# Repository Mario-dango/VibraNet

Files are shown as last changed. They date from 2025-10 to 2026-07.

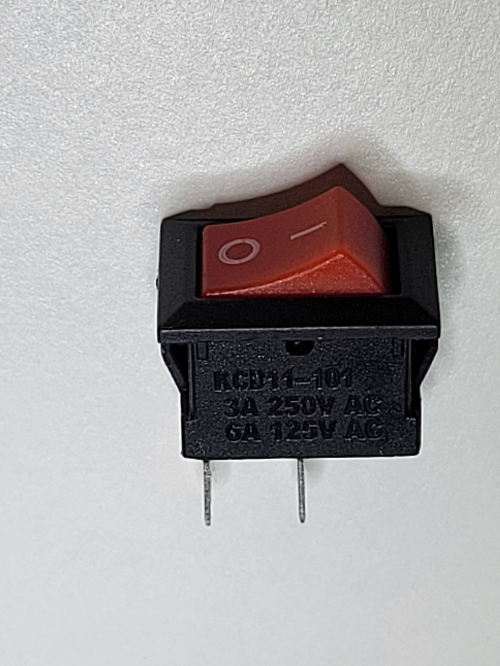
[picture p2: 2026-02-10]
DESIGN/mini-on-off-rocker-switch-2-pins-1.snapshot.4/KCD11-101.jpg

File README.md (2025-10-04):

# Proyecto Tipo C · Red de nodos de adquisición de datos sismográficos

> Monitoreo de vibraciones/sismos en edificación universitaria con nodos ESP8266 + MPU6050, backend Node-RED/Mosquitto/MySQL en Ubuntu Server. 

---

## 1) Contexto y alcance

* **Dominio:** monitoreo sísmico estructural en la Facultad de Medicina (UNCuyo), con **4–10 nodos** distribuidos en puntos de interés. 
* **Tecnologías núcleo:** Node-RED (gestión/visualización), Mosquitto (MQTT), MySQL (persistencia), Ubuntu Server (SO). 
* **Nodo:** ESP8266 (ESP-01) + MPU6050 (GY-521), alimentación fija y Li-ion, PCB propia. 
* **Motivación:** alternativa **de bajo costo** con desempeño “accionable” frente a soluciones comerciales de alta precisión pero costosas.  

**Objetivo general:** validar la factibilidad y el error objetivo (≤10%) mediante prototipado, pruebas y calibración.  

---

## 2) Arquitectura (E2E)

```mermaid
flowchart LR
  %% IDs simples (A–Z, 0–9, _), solo ASCII. Sin <br/> ni comillas curvas.
  subgraph Capa_Nodos_4_10
    A1["ESP8266 / ESP-01\nMPU6050 (GY-521)"] -->|MQTT QoS1| BRK[(Mosquitto)]
    A2["ESP8266 / ESP-01\nMPU6050 (GY-521)"] -->|MQTT QoS1| BRK
  end

  BRK --> NR["Node-RED\nFlows + Dashboards"]
  NR  --> DB[(MySQL)]
  NR  --> A[Alertas / Notificaciones]

  %% Estilo básico para infra
  classDef infra fill:#eeeeee,stroke:#333333,stroke-width:1px;
  class BRK,DB infra;
```

**Notas:**

* Visualización y orquestación en **Node-RED**, broker **Mosquitto**, almacenamiento **MySQL** sobre **Ubuntu Server**. 
* Escalabilidad por cobertura de **4–10** dispositivos; despliegue in situ en el edificio objetivo. 

---

## 3) Estructura del repositorio

```
.
├─ firmware/                # Código ESP8266 (ESP-01) + MPU6050
   ├─ src/
   └─ include/
├─ design/                  # 3D models
│  ├─ Acoples/              
│  ├─ Accesorios/                 
│  └─ Impresiones 3D/                   
├─ PCB/
│  └─ Diseño de módulo      
├─ docs/
│  ├─ arquitectura.md
│  ├─ calibracion.md
│  └─ o&m.md
└─ README.md
```

---

## 4) Requisitos

* **Nodo:** Módulo ESP-07, módulo GY-521, fuente 5 V + step-down 3.3 V, batería Li-ion opcional. 
* **Servidor:** Ubuntu Server con Node-RED, Mosquitto y MySQL. 

---

## 5) Firmware (ESP8266 + MPU6050)

**Intención:** lectura de aceleraciones/giroscopio, timestamp NTP, buffer local, MQTT QoS1 con reconexión y LWT, watchdog, empaquetado JSON/CBOR.

**Supuestos de diseño:**

* Frecuencia de muestreo recomendada 100–200 Hz para vibraciones estructurales de baja a media frecuencia.
* Antialiasing digital simple con media móvil/BIQUAD; calibración in situ en etapa de instalación.

**Esqueleto de payload (JSON):**

```json
{
  "node_id": "FACMED-03",
  "ts_unix_ms": 1733345678901,
  "ax": -0.0123, "ay": 0.0045, "az": 1.0012,
  "gx": 0.12, "gy": -0.05, "gz": 0.02,
  "vbat": 3.94, "temp": 28.4, "seq": 15231
}
```

**Tópicos MQTT:**

```
sismo/nodo/<node_id>/datos       (QoS1, no retenido)
sismo/nodo/<node_id>/estado      (QoS1, retenido)      # heartbeats
sismo/nodo/<node_id>/lwt         (QoS1, retenido)      # Last Will
sismo/cmd/<node_id>              (QoS1)                # control
```

**Criterios de prueba rápida:**

1. Pérdida de WiFi: datos en buffer y reenvío al reconectar.
2. Desconexión broker: activación de **LWT** y recuperación de sesión.
3. Variación NTP: jitter de timestamp < 20 ms en red local.

---

## 6) Backend

### 6.1 Mosquitto (MQTT)

**Intención:** broker central con TLS, usuarios/ACL y LWT.

```conf
# deploy/mqtt/mosquitto.conf (resumen)
listener 8883
cafile /etc/mosquitto/certs/ca.crt
certfile /etc/mosquitto/certs/server.crt
keyfile /etc/mosquitto/certs/server.key
require_certificate false
allow_anonymous false
password_file /etc/mosquitto/passwd
acl_file /etc/mosquitto/acl
persistence true
persistence_location /var/lib/mosquitto/
```

**ACL mínimo de ejemplo:**

```
user nodo01
topic write sismo/nodo/nodo01/#
topic read  sismo/cmd/nodo01

user nodered
topic read  sismo/nodo/+/datos
topic read  sismo/nodo/+/estado
topic read  sismo/nodo/+/lwt
topic write sismo/cmd/+
```

### 6.2 Node-RED

**Intención:** ingestión MQTT, cálculo de KPIs (PGA/PGV), alarmas y dashboard.
**KPIs sugeridos:** PGA, PGV, espectros de respuesta 5% amort.
**Entrega:** flujos exportables en `backend/nodered/flows/*.json`.

### 6.3 MySQL (modelo de datos)

**Intención:** persistencia de series temporales y metadatos.

```sql
-- backend/db/schema.sql (resumen)
CREATE TABLE nodes (
  id VARCHAR(32) PRIMARY KEY,
  alias VARCHAR(64),
  location VARCHAR(128),
  installed_at DATETIME,
  active TINYINT DEFAULT 1
);

CREATE TABLE samples (
  id BIGINT AUTO_INCREMENT PRIMARY KEY,
  node_id VARCHAR(32) NOT NULL,
  ts_unix_ms BIGINT NOT NULL,
  ax FLOAT NOT NULL, ay FLOAT NOT NULL, az FLOAT NOT NULL,
  gx FLOAT, gy FLOAT, gz FLOAT,
  vbat FLOAT, temp FLOAT, seq BIGINT,
  KEY k_node_ts (node_id, ts_unix_ms),
  CONSTRAINT fk_samples_node FOREIGN KEY (node_id) REFERENCES nodes(id)
);

CREATE TABLE events (
  id BIGINT AUTO_INCREMENT PRIMARY KEY,
  started_at DATETIME NOT NULL,
  ended_at   DATETIME,
  max_pga FLOAT, max_pgv FLOAT, note VARCHAR(255)
);
```

**Criterios de prueba rápida:**

* Inserción sostenida ≥ 200 msg/s en LAN con retardo < 100 ms E2E.
* Consultas por ventana móvil de 5 min bajo 200 ms.

---

## 7) Despliegue

### 7.1 Docker Compose (opcional)

```yaml
# deploy/docker-compose.yml
version: "3.9"
services:
  mosquitto:
    image: eclipse-mosquitto:2
    ports: ["1883:1883", "8883:8883"]
    volumes:
      - ./mqtt/mosquitto.conf:/mosquitto/config/mosquitto.conf:ro
      - ./mqtt/certs:/etc/mosquitto/certs:ro
      - mosq_data:/var/lib/mosquitto
  nodered:
    image: nodered/node-red:latest
    ports: ["1880:1880"]
    environment:
      - TZ=America/Argentina/Mendoza
    volumes:
      - ./nodered/data:/data
  mysql:
    image: mysql:8
    environment:
      - MYSQL_ROOT_PASSWORD=changeme
      - MYSQL_DATABASE=sismo
    ports: ["3306:3306"]
    volumes: [ "mysql_data:/var/lib/mysql" ]
volumes: { mosq_data: {}, mysql_data: {} }
```

### 7.2 Ubuntu Server

* Instalar paquetes base, habilitar firewall, configurar TLS y usuarios para broker y DB. 

---

## 8) Seguridad y roles

* **Transporte:** TLS en MQTT y en accesos al dashboard.
* **Autenticación:** usuarios separados por rol: `nodo`, `nodered`, `ops`.
* **Principio de mínimo privilegio:** ACL por tópico.
* **DB:** credenciales por servicio, rotación y backups programados.

---

## 9) Calibración y validación

* **Metodología:** prototipado → pruebas con estímulos conocidos → calibración para error ≤10%. 
* **Resultados esperados:** sistema instalado, base de datos operativa, informe técnico. 

---

## 10) Plan de pruebas

1. **Nodo**: watchdog, reconexión, buffer offline, precisión de timestamp.
2. **Red**: caída de WiFi y broker, recuperación de sesión MQTT.
3. **Integración**: ingestión Node-RED → MySQL, latencia y throughput.
4. **Resiliencia**: microcortes de energía, persistencia del broker.
5. **Validación**: comparación contra referencia en mesa vibratoria/estímulo controlado.

---

## 11) Instalación in situ y O&M

* **Ubicación y fijación** de nodos en la estructura; coordinación con autoridades para permisos y posiciones. 
* **Mantenimiento mínimo:** recambio/recarga de batería Li-ion según desgaste. 

---

## 12) Roadmap (alto nivel)

1. Diseño y prototipado del nodo.
2. Backend en nube y pruebas de integración.
3. Fabricación 4–10 unidades, instalación, optimización. 

---

## 13) Trazabilidad (resumen)

* **Requisito**: bajo costo y despliegue escalable → **Diseño**: ESP8266 + MPU6050; **Implementación**: MQTT/Node-RED/MySQL; **Prueba**: error ≤10%; **Resultado**: sistema instalado y DB operativa.   

---

## 14) Contribución

* PRs con tests y flujos reproducibles.
* Convenciones: commits tipo Conventional Commits, revisiones de seguridad básicas.

---

## 15) Licencia

Licencia MIT.

---

## 16) Créditos

* **Organismo:** Facultad de Ingeniería – UNCuyo. **Espacio:** Mecánica Vibratoria. 
* **Beneficiarios:** Facultad de Medicina (sistema + acceso lector a DB); cátedra Mecánica Vibratoria (nodo didáctico).  

---

## 17) Referencias del proyecto

* Documento base del proyecto: “Proyecto Tipo C: Red de nodos de adquisición de datos sismográficos.” (PDF). 
* Contexto y motivación (“Key Information”). 

---

### Anexo A · Diagrama de secuencia (telemetría)

```mermaid
sequenceDiagram
  autonumber
  participant MPU as MPU6050
  participant MCU as ESP8266 (ESP-01)
  participant BRK as Mosquitto
  participant NR as Node-RED
  participant DB as MySQL

  MPU->>MCU: Lectura ax,ay,az,gx,gy,gz @fs
  MCU->>MCU: Timestamp NTP + empaquetado JSON
  MCU->>BRK: PUBLISH sismo/nodo/<id>/datos (QoS1)
  BRK-->>NR: FORWARD mensaje
  NR->>DB: INSERT muestras
  NR-->>NR: KPIs (PGA/PGV) + alarmas
```

---

> **Cómo usar este README**
>
> 1. Adaptá el `docker-compose.yml` a tu servidor.
> 2. Importá los flujos Node-RED y conectá al broker y DB.
> 3. Flasheá el firmware del ESP-01 con tus credenciales WiFi/MQTT.
> 4. Corré pruebas de red, ingestión y calibración hasta cumplir el ≤10% de error. 

---

Medical References:
1. None — DOI: file-QWTmTeDuec8pwW5nHiFvFW

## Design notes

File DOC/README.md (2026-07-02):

## Mejoras futuras
- Que los nodos no deban de estar en la misma red que el servidor.
- Montar el servidor en un host cloud.
- Diseñarle acoples en 3D del nodo principal y de su extensión para el sensor s2.
- Agregarle una instancia de persistencia de datos, módulo microSD para que almacene las lecturas, pregunte si las lecturas guardadas respecto a las del servidor están actualizadas o deberá de enviarlas.
- Agregar en grafana la posibilidad de exportar todos esos datos que visualiza en un archibo .xlsx o .csv para análisis fuera de grafana.
- Agregar un botón de configuración (que permita ponerlo en modo AP y cambiar credenciales manualmente de red y mqtt).
- Configurar parámetros del nodo por mqtt (nodo id, cliente, etc).

## Faltó realizar pruebas
- Recepción de señal Wi-Fi en entornos industriales o de ruido electromagnético (para disernir si agregar antena externa o no).
- Comprobar ruidos EM que se colen en el cable del sensor s2.

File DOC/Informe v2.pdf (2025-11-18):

UNIVERSIDAD NACIONAL DE CUYO

Facultad de Ingeniería

Red de nodos de adquisición de datos sismográficos.

Red de adquisición sísmica: del prototipo THT a la revisión SMD

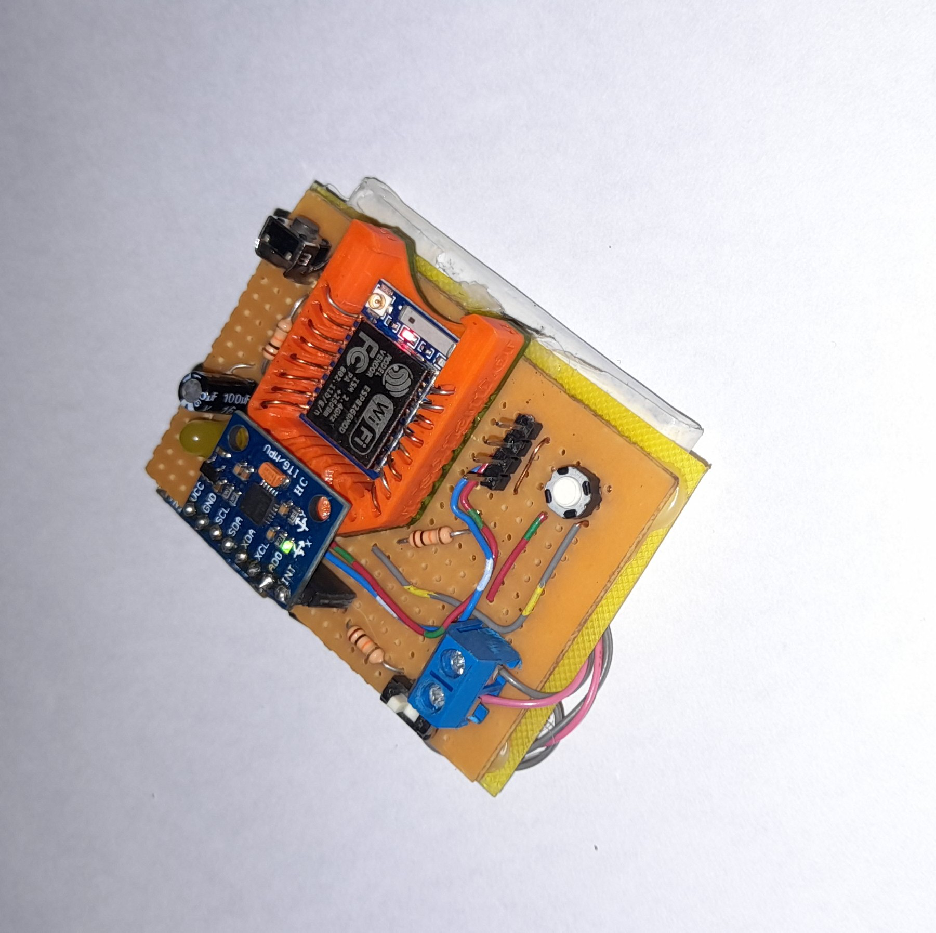
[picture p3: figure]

C A R R E R A | Ingeniería Mecatrónica
S E M E S T R E | Segundo Semestre 2025
C Á T E D R A | Proyecto Tipo C
A L U M N O S | Barrios Retta Federico , 14101
| Cano Francisco , 12487
| Pappeti Mario , 11807
F E C H A | 03 de noviembre de 2025

### Contents

1 Resumen ejecutivo | 3
2 Contexto y objetivos | 3
3 Alcance y trazabilidad | 3
4 Arquitectura general (E2E) | 4
5 Selección de plataforma MCU y módulos Wi-Fi | 5
6 Micro investigación de mercado | 6
7 Diseño HW — Placa v0.0.1 (THT) | 7
8 Problemática de energia — Batería Li-ion | 10
9 Diseño HW — Placa v0.0.2 (SMD) | 12
10 Prototipo físico | 15
11 Firmware (ESP8266/ESP32) | 17

Universidad Nacional de Cuyo | Facultad de Ingeniería
12 Cobertura y propagación (plan de medicion) | 18
13 Deep-sleep y “reset virtual” (ESP8266) | 18
14 Backend y dashboard | 19
15 Frecuencias de muestreo — justificación | 19
16 Riesgos y mitigaciones | 20
17 Plan de proxima iteracion | 20
18 Anexos | 20

### 1 Resumen ejecutivo

Este proyecto desarrolla una red de nodos sismográficos IoT con adquisición triaxial y backend MQTT+MySQL, orientada al monitoreo de vibraciones estructurales en la banda 0.5–30 Hz. Durante este corte se priorizó la verificación funcional de hardware (v0.0.1 THT y v0.0.2 SMD), la puesta en marcha de la base de datos y la consolidación del firmware para adquisición cruda y publicación por bloques. Se identificaron restricciones energéticas y de reconexión asociadas al uso de Li-ion y deep-sleep en ESP8266, que guían las decisiones de regulación y de diseño de ciclos de trabajo. El objetivo inmediato es cerrar mediciones en banco (consumo, autonomía y latencia E2E) y validar cobertura Wi-Fi para el piloto.

Avances clave

- Diseño de placa de desarrollo v0.0.1 (THT) y v0.0.2 (SMD).
- Prototipo físico para verificación dimensional y ensamble.
- Arquitectura de la base de datos MySQL.
- Análisis de energía y batería, con dificultades detectadas.
- Prototipo de firmware con timers/ISR para muestreo periódico (FreeRTOS).

Riesgos activos

- Autonomía real vs objetivo
- Deep sleep con reset
- Tensión de la pila de Li-ion difiere con Vcc de alimentación del microcontrolador
- Reconexión robusta tras sleep.

Próximos hitos

- Validación energética en banco
- Prototipo físico de la placa de desarrollo v0.0.2 (SMD)
- Inserción bulk y particionado en DB.

### 2 Contexto y objetivos

Este piloto aborda el monitoreo de vibraciones estructurales en banda 0.5-30 Hz mediante una red de nodos IoT que adquieren y publican datos crudos para su procesamiento en servidor. Objetivos medibles del corte: (i) adquisicion estable a 200 Hz y publicacion por bloques; (ii) exactitud ≤ 10% tras calibracion estatica de la IMU; (iii) disponibilidad de ingesta continua (MQTT→Node-RED→MySQL) y consultas por ventana temporal en dashboard.

### 3 Alcance y trazabilidad

Esta iteración se centra en adquirir y publicar datos crudos de aceleración triaxial desde nodos ESP8266 con IMU MPU6050, en la banda 0.5–30 Hz. El procesamiento (filtrado, espectros, KPIs) se realiza en el servidor, dejando al nodo la mínima responsabilidad: medir, empaquetar y publicar por bloques con marca de tiempo (ts_ms, fs_hz, seq). La base de datos MySQL debe aceptar ingesta idempotente y consultas por ventana temporal; el dashboard expone disponibilidad por nodo y series para diagnóstico.

Quedan fuera de alcance del presente corte la instalación definitiva en obra, la optimización energética con conversión buck-boost y las alarmas avanzadas; se documentan como pendientes con riesgos asociados. La validación prioriza: estabilidad de muestreo, reconexión tras deep-sleep y consistencia de la ingesta (sin duplicados) end-to-end.

Trazabilidad de requerimientos actuales

Requerimiento
(qué) | Artefacto (con qué) | Prueba/verificación (cómo) | Estado
Muestreo estable a 200 Hz | Firmware con timer+ISR y
| lectura I2C | Desvío < 1 % en periodo y
| | conteo en 30 min continuos | En
| | | curso
Publicación por bloques (QoS1) | MQTT tópicos
sismo/<site>/<nodeId>/data
| | Recepción íntegra y ordenada
| | de N bloques en broker | En
| | | curso
Reconexión tras deep-sleep | GPIO16->RST y arranque
| idempotente | wake->publish p95 ≤ 3 s;
| | status/LWT correcto | Pendiente
Ingesta idempotente en DB | Tabla mediciones con
| UNIQUE | INSERT ... ON DUPLICATE
| | KEY sin duplicados | OK/Parcial
Consulta por ventana temporal | Índice (nodo_id,
| measured_at) | SELECT rango con latencia
| | aceptable (p50/p95) | OK/Parcial
Trazabilidad de pines/IMU | Pinout efectivo y
| calibración | Lectura estable + offset
| | corregido en reposo | En
| | | curso
Cobertura Wi-Fi en sitio piloto | v0.0.2 con keep-out RF y
| plan de medición | RSSI medio y pérdida < 1 %
| | en 30 min | Planificado

Criterio de aceptación del corte: firmware capaz de medir y publicar bloques a 200 Hz con ts_ms/fs_hz/seq, ingesta idempotente operativa en MySQL y reconexión funcional tras deepsleep (jitter de muestreo, wake->publish, pérdida de mensajes).

### 4 Arquitectura general (E2E)

Diagrama de bloques (visión actual)

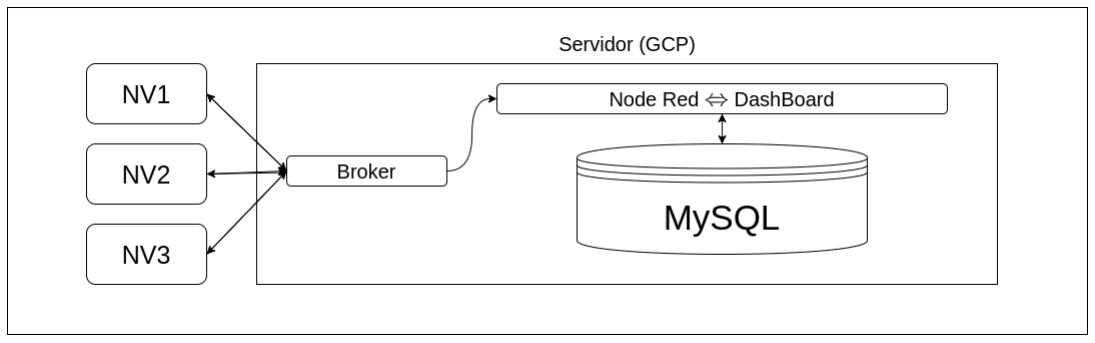
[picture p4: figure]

La solución se organiza en una tubería simple y robusta: cada nodo (ESP8266 + MPU6050) adquiere aceleración triaxial, agrega metadatos mínimos (ts_ms, fs_hz, seq, n, temp_c, vbat) y publica bloques crudos via MQTT hacia un broker Mosquitto. Un flujo en Node-RED valida el esquema, transforma y persiste en MySQL. Todo el posprocesamiento (filtrado, espectros, alarmas) se ejecuta en el servidor, manteniendo el firmware liviano.

El acoplamiento es débil y observable: los nodos usan QoS1 y LWT retenido para señalizar estado; al salir de deep-sleep el arranque es idempotente (re-sincroniza NTP, repone seq y reanuda publicación). El backend aplica inserción idempotente (UNIQUE por nodo_id, measured_at, seq) para tolerar reintentos, y el dashboard consulta por ventanas temporales indexadas. La comunicación va cifrada (TLS en MQTT y MySQL) y con usuarios de privilegios mínimos.

Flujo lógico: Nodos → MQTT (broker) → Node-RED (validación y SQL) → MySQL (persistencia) → Dashboard (consulta).

### 5 Selección de plataforma MCU y módulos Wi-Fi

Fuentes (datasheets)

- ESP8266EX | (Espressif): | https://www.alldatasheet.com/datasheet-pdf/view/
1148030/ESPRESSIF/ESP8266EX.html (https://www.alldatasheet.com/datasheet-pdf/view/1148030/ESPRESSIF/ESP8266EX.html)
- MPU-6050 | (InvenSense): | https://www.alldatasheet.es/datasheet-pdf/view/
517744/ETC1/MPU-6050.html (https://www.alldatasheet.es/datasheet-pdf/view/517744/ETC1/MPU-6050.html)

ESP8266 (ESP-07/ESP-12)

El ESP8266 integra CPU Tensilica LX106 @80–160 MHz, radio 802.11b/g/n 2.4 GHz, TCP/IP embebido, SPI/I2C/UART, timers y GPIO suficientes para un nodo de adquisición sísmica ligera. Para nuestra necesidad (muestreo 100–200 Hz y publicación MQTT), aporta capacidad de cómputo y conectividad de sobra, con un ecosistema maduro (Arduino core/RTOS), bajo costo y buena disponibilidad.

Funciones principales: Wi-Fi STA/AP, pila TCP/IP, TLS por software, interrupciones GPIO, timers HW, deep-sleep con wake en GPIO/RTC.

Consumos típicos (orden de magnitud, dependientes de firmware y AP):

- TX/RX Wi-Fi con ráfagas: picos ~200 mA; promedio en ráfagas 70–120 mA.
- Modem-sleep (CPU activa, radio duty-cycled): ~15–20 mA.
- Light-sleep (CPU en bajo consumo): ~0.8–2 mA.
- Deep-sleep: ~10–25 μA (despierta por GPIO/RTC externo). Estas cifras guían el dimensionamiento de batería y duty-cycle; se recomiendan mediciones reales en banco para validar.

Módulo elegido (ESP-07 frente a ESP-01): migramos de ESP-01 a ESP-07/ESP-12 por: (i) más GPIO útiles (I2C + INT de la IMU sin conflictos), (ii) mejor desempeño RF y keep-out claro para antena, y (iii) opción de antena externa (u.FL en algunas variantes) para ensayos de cobertura en edificio. Esto reduce riesgos de saturación de pines y mejora la robustez del enlace.

Por qué no ESP32 (por ahora): ESP32 agrega BT/BLE, más RAM/CPU y periféricos, pero incrementa costo y consumo en reposo. Dado que el ancho de banda de señal sísmica de interés es 0.5–30 Hz y la tasa de publicación es modesta, el ESP8266 cubre holgadamente requisitos con menor consumo en deep-sleep y menor BOM. Dejamos ESP32 como alternativa si más adelante requerimos: doble núcleo para procesamiento local, ADCs internos de mayor calidad, o cifrado TLS con mayores márgenes.

MPU-6050 (acelerómetro+giroscopio 6-ejes)

El MPU-6050 integra acelerómetro y giróscopo triaxiales con ADCs de 16 bits, DMP, FIFO de 1024 B e interfaz I2C (400 kHz). Rango programable ± 2/4/8/16 g y ±250/500/1000/2000 °/s. La interrupción INT permite muestreo cronometrado y lectura por ráfagas.

Consumos (datasheet):

- Acel+gyro+DMP activos: ~3.9 mA.
- Solo acelerómetro: ~500 μA.
- Acelerómetro en low-power: ~10 μA @1.25 Hz a ~140 μA @40 Hz.
- FIFO e INT reducen actividad del MCU al permitir lecturas en ráfagas.

Justificación de elección: amplia disponibilidad, costo bajo, documentación y ejemplos abundantes, y rendimiento suficiente para 100–200 Hz con ruido aceptable tras calibración de offsets/escala. El pin INT facilita sincronía de muestreo y el FIFO evita jitter por latencias de I2C/MQTT.

Síntesis comparativa

ESP8266 (ESP-07/12) + MPU-6050 ofrece la mejor relación costo/consumo/capacidad para un nodo IoT sísmico: Wi-Fi estable, consumo en deep-sleep de orden decenas de μA, y sensor 6-ejes ~4 mA activo. ESP32 queda como “plan B” si más adelante necesitamos procesamiento embarcado o enlaces más exigentes; el ESP-07 se prefiere al ESP-01 por GPIO y performance RF (opción de antena externa) que simplifican el cableado de I2C+INT y los ensayos de propagación.

### 6 Micro investigación de mercado

El monitoreo de vibraciones en la banda 0.5–30 Hz tiene dos ecosistemas cercanos pero distintos: SHM civil/sísmico y PdM industrial. El primero prioriza baja frecuencia real (hasta DC o 0.5 Hz), autonomía y robustez ambiental; el segundo privilegia diagnósticos de maquinaria y suele cortar por debajo de 1–3 Hz. En este contexto, los acelerómetros MEMS modernos de bajo ruido habilitan nodos IoT triaxiales de costo contenido y consumo moderado, mientras que las soluciones piezoeléctricas IEPE siguen dominando cuando se requiere precisión metrológica de alto nivel.

Hallazgos clave

- Compatibilidad de banda: muchos transmisores 4–20 mA industriales fallan por debajo de 3–10 Hz; no sirven para 0.5–30 Hz. En cambio, MEMS triaxiales específicos de baja frecuencia (p. ej., líneas tipo ADXL35x/derivados) sí cubren la banda objetivo.
- Nodos COTS: existen equipos SHM inalámbricos con rango útil desde 0.5 Hz y pisos de ruido <100 μg/√Hz; son robustos pero caros y, a menudo, con radio/protocolo propietarios (LoRaWAN/protocolos 2.4 GHz).
- Argentina (ecosistema): hay integradores locales para soluciones “llave en mano” y distribuidores de sensores sísmicos de baja frecuencia (v.g., VibraSens vía representante local), además de servicio/calibración con trazabilidad internacional.
- Backend: MQTT es estándar para telemetría; MySQL funciona para prototipo.
- Estrategia: para este proyecto académico con control de pila y costo, conviene Integrar (sensores adecuados + nodos propios + MQTT + DB) en lugar de Comprar COTS o Desarrollar desde cero ASIC/PCB de alto NRE.

Implicancias para nuestro diseño

Para capturar 0.5–30 Hz con SNR adecuado y mantener autonomía, se justifica continuar con nodos IoT MEMS triaxiales y publicación vía MQTT; mantener MySQL. En Argentina existe oferta para: (a) sensores de baja frecuencia, (b) integración LoRaWAN/MQTT, y (c) calibración con trazabilidad, lo que viabiliza escalamiento y validación metrológica local en siguientes cortes.

### 7 Diseño HW — Placa v0.0.1 (THT)

Descripción General

Se diseno una primera revision orientada a verificacion funcional. La alimentacion se resolvio con batería Li-ion, diodo serie y LDO AMS1117-3.3, suficiente para banco pero limitada en eficiencia y margen de caida. La logica de arranque incluye pulsadores de BOOT y RESET con EN por pull-up. La IMU MPU6050 se conecta por I2C y expone INT al MCU. Se dispone de senalizacion mediante cuatro LEDs y de headers para UART y MPU6050.

- Formato: 61.98 × 33.02 mm, 4 orificios de montaje.
- Topologia: batería Li-ion → diodo serie → LDO AMS1117-3.3 → rail 3V3 para ESP-07 y GY-521.
- Senalizacion: cuatro LEDs (Wi-Fi, datos, aux1, aux2) con resistencias limitadoras.
- Control: pulsadores de BOOT y RESET; EN con pull-up (R3).
- Interfaz: header UART para programacion y header I2C/INT para IMU.
- Conectividad IMU: SCL/SDA, INT y AD0 cableados al conector J4 (modulo MPU6050).

Bloques y esquemas

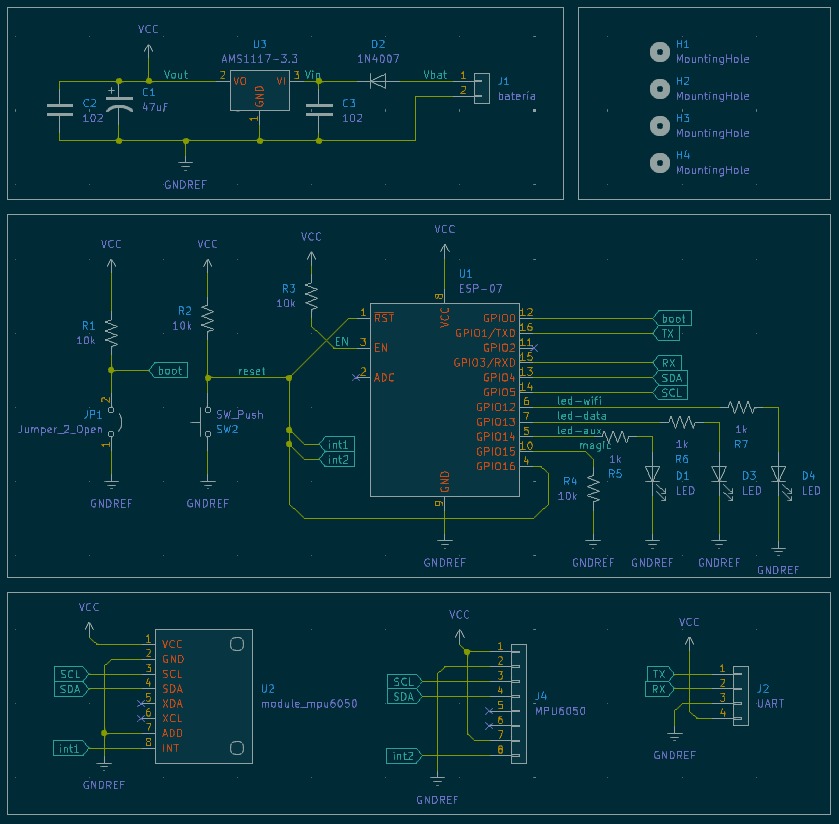
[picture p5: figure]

1. Alimentacion: AMS1117-3.3 con C1=47 μF de bulk y ceramicos de desacople (C2

, C3
).
Diodo 1N4007 en serie desde batería como solucion transitoria para reducir Vbat.
2. Control de arranque:
- BOOT con R1 = 10kΩ a GND y pulsador a VCC para forzar modo flash cuando se requiera.
- RESET con R2 = 10kΩ, pulsador a GND y EN con R3 = 10kΩ a VCC.
3. MCU + IO: ESP-07 con GPIOs mapeados a UART, I2C y LEDs (R4 − R7
).

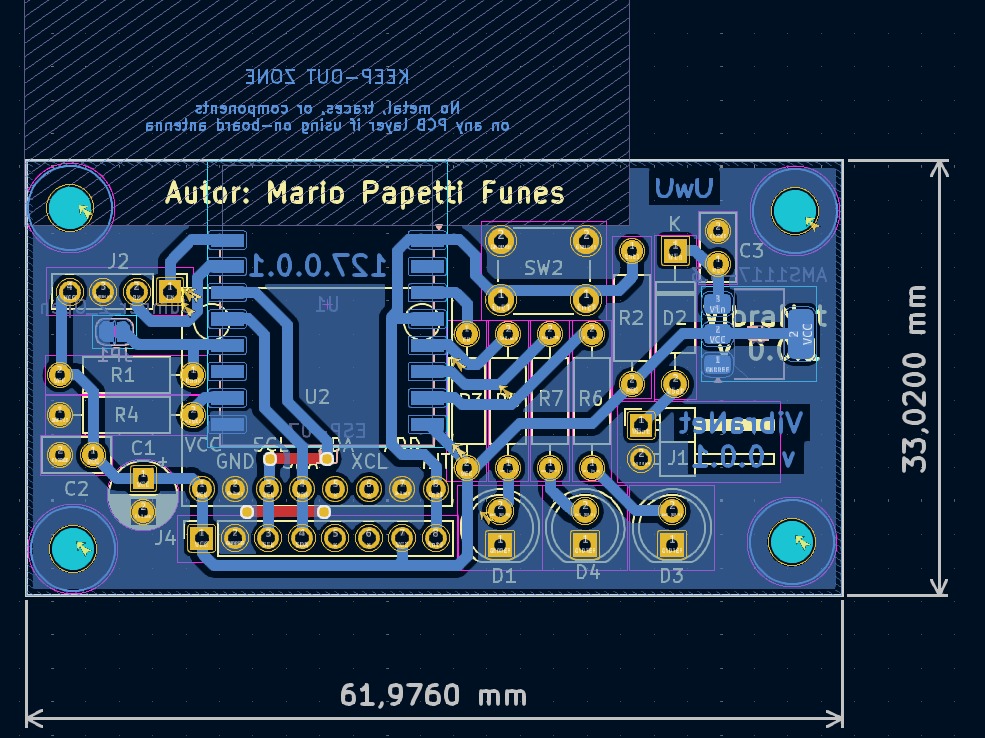
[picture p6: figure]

Ruteo de una cara con puentes; headers dedicados para UART y MPU6050. Se senalan keep-out y leyendas (autor, version).

Pinout efectivo (para trazabilidad de firmware)

Funcion | Pin ESP8266 | Conector | Nota
UART TX | GPIO1/TXD0 | J2-TX | Programacion/registro
UART RX | GPIO3/RXD0 | J2-RX | Programacion/registro
I2C SCL | GPIO5 | J4-SCL | Pull-ups en modulo GY-521
I2C SDA | GPIO4 | J4-SDA | —
IMU INT | GPIO14 (int1) | J4-INT | Interrupciones de movimiento
LED Wi-Fi | GPIO12 | D1 + R4 | Estado radio
LED Datos | GPIO13 | D2 + R5 | Publicacion/actividad
LED Aux 1 | GPIO15 | D3 + R6 | Uso general
LED Aux 2 | GPIO16 | D4 + R7 | Uso general
EN (chip-enable) | EN | — | Pull-up R3 = 10kΩ
RESET | RST | SW2 | Pulsador a GND
BOOT | GPIO0 | SW1/JP1 | Forzar modo programacion

Riesgos e impactos

Riesgo | Impacto
Dropout con LDO + diodo Resets en TX Falta de desacople correcto Ruido en IMU/MCU

Riesgo | Impacto
Sin medicion de corriente | Autonomia incierta
Proteccion insuficiente | Sensibilidad a ESD/fallos

Registro fotográfico (referencias)

- Vista superior: ubicacion de ESP-01, GY-521, LED y controles.
- Vista inferior: batería y cargador/proteccion con cableado.
- Vista lateral: apilado de modulos, disipador en ESP-01, accesos a headers.
- Vista isometrica: vista general de la disposicion del prototipo.

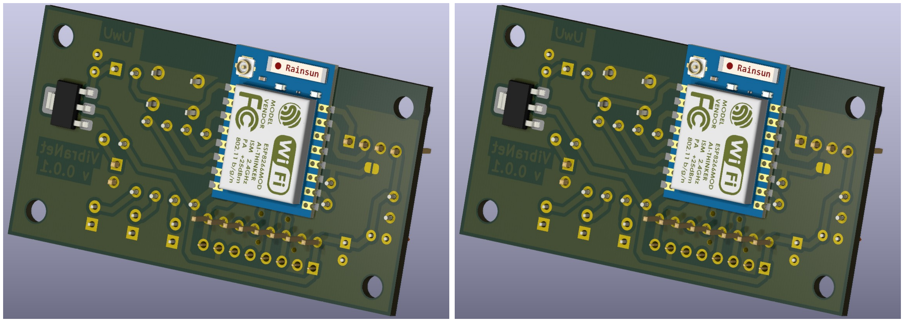
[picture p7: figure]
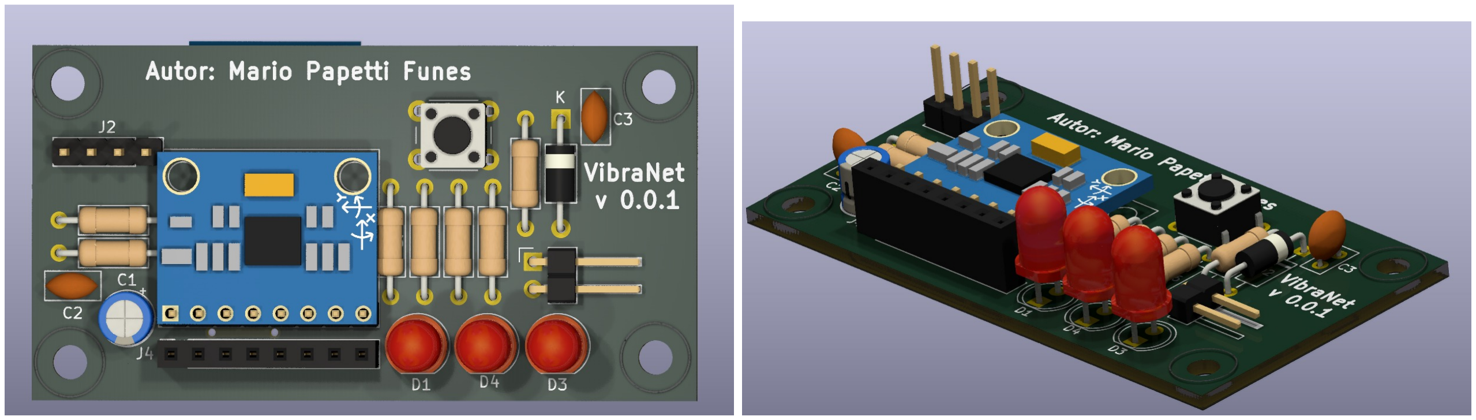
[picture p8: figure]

Figura: Vibranet v0.0.1 (vistas del prototipo THT).

### 8 Problemática de energia — Batería Li-ion

La red de nodos requiere autonomia electrica para operar sin red fija. La fuente elegida es una celda Li-ion de factor de forma compacto (≤ 50 × 50 mm, espesor < 7.5 mm). El ESP8266 opera entre 2.5-3.6 V y presenta cuatro modos de potencia (activo, modem-sleep, light-sleep y deep-sleep). Segun el datasheet del ESP8266EX (https://documentation.espressif.com/0a-esp8266ex_datasheet_en.pdf) , el consumo tipico es: deep-sleep ≈ 20μA, light-sleep ≈ 0.9mA, modem-sleep ≈ 15mA, y en activo con radio el promedio ronda decenas de mA con picos de >100 mA en TX/RX (ver Tabla 3-4 “Power Consumption by Power Modes” y Tabla 1-1 “Specifications”).

El consumo del modulo MPU6050 se debe suponer hasta realizarse mediciones. Supuesto: la IMU MPU6050 anade ≈ 3-4 mA en adquisicion continua y < 10 μA en modo low-power accel. Estos valores se validaran en banco.

Implicancia: la autonomia no la determina el consumo de 20μA en deep-sleep, sino el duty cycle real entre medir, transmitir y dormir. Ademas, el rango de tension de la celda Li-ion

(≈ 4.2 → 3.0V ) no es directamente compatible con la ventana 2.5 − 3.6V del ESP8266 si no se condiciona la tension.

Restricciones de diseno

1. Tensión
- Batería Li-ion: 4.2 V (cargada) a ~3.0 V (descargada).
- ESP8266: 2.5-3.6 V.
- Conclusión: se requiere regulacion.

– Un diodo en serie (≈ 0.7 V) reduce 4.2 -> 3.5 V, pero colapsa a ~2.3 V cuando la celda cae a 3.0 V, bajo el minimo del ESP8266. No es solucion de produccion. – Un LDO a 3.3 V desaprovecha la cola de la batería (cuando Vin < 3.3 V entra en dropout).
– Un buck a 3.3 V es eficiente por arriba de 3.3 V, pero no regula cuando Vin < 3.3 V.
2. Ciclo de operación Definimos un ciclo con tres estados:
- Activo (adquisicion + TX): ESP8266 activo con radio, IMU activa.
- Idle/light-sleep: CPU o perifericos pausados, radio apagado.
- Deep-sleep: solo RTC operativo; en ESP8266 el wake implica reset del MCU.
3. Recuperación post-sleep El deep-sleep reinicia el ESP8266: se debe reconstruir estado (NTP, MQTT, seq, reconfiguracion IMU) de forma idempotente.

Marco de calculo de autonomia

Para un ciclo de duracion T = ta + tl + td

con corrientes Ia

, Il

, Id
:

Considerando:

- T : duracion total de un ciclo.
- ta
: tiempo en estado activo (adquisicion + TX/RX).
- tl
: tiempo en light-sleep (CPU/perifericos en pausa, radio apagada).
- td
: tiempo en deep-sleep (solo RTC activo).
- Ia
: corriente media en estado activo.
- Il
: corriente media en light-sleep.
- Id
: corriente media en deep-sleep.

Iprom =

Ia

ta + Il

tl + Id

td
T

⇒ Autonomia (h) ≈ CmAh ⋅ η Iprom

- Capacidad efectiva CmAh: nominal × factor de eficiencia η ∈ [0.8, 0.9] para perdidas de regulador y temperatura.
- Supuestos iniciales (a validar): Ia = 120 mA promedio durante TX y lectura, Il = 0.9 mA, Id = 20 μA. IMU activa suma ~4 mA en Ia y ~10 μA en bajo consumo.

Ejemplo de orden de magnitud (no compromiso de diseno): Si ta = 2 s, tl = 8 s, td = 50 s por ciclo de 60 s, entonces Iprom ≈

(124)(2)+(0.9)(8)+(0.02)(50)
60 | ≈ 4.5 mA. Con una celda 2000 mAh y
η = 0.85 →≈ 377ℎ teoricas. Pequenos cambios en ta o Ia derrumban la cifra, de ahi la necesidad de medir.

### 9 Diseño HW — Placa v0.0.2 (SMD)

Descripción general

Revision orientada a compactar el diseno y mejorar DFM/EMI manteniendo la funcionalidad de la v0.0.1. Se migra a SMD con plano de masa continuo, keep-out para antena y headers accesibles para IMU y UART. La alimentacion continua con LDO AMS1117-3.3 + diodo serie como solucion de banco, en espera de migrar a buck-boost 3.3 V en la siguiente iteracion.

- Formato: 51.56 × 38.61 mm, 4 orificios de montaje.
- Topologia: batería Li-ion → diodo serie → LDO AMS1117-3.3 → rail 3V3 para ESP-12 y conector MPU6050.
- Keep-out RF: zona superior libre de cobre y componentes sobre la antena integrada (serigrafia “KEEP-OUT ZONE”).
- Control: pulsador RESET, pad para BOOT/FLASH y EN con pull-up.
- Interfaz: header UART de programacion y header I2C/INT para la IMU.
- Senalizacion: tres LEDs SMD para estado (Wi-Fi/datos/aux).

Vease Cobertura y propagacion (plan de medicion) para los ensayos de antena y cobertura asociados a esta revision.

Bloques y esquemas

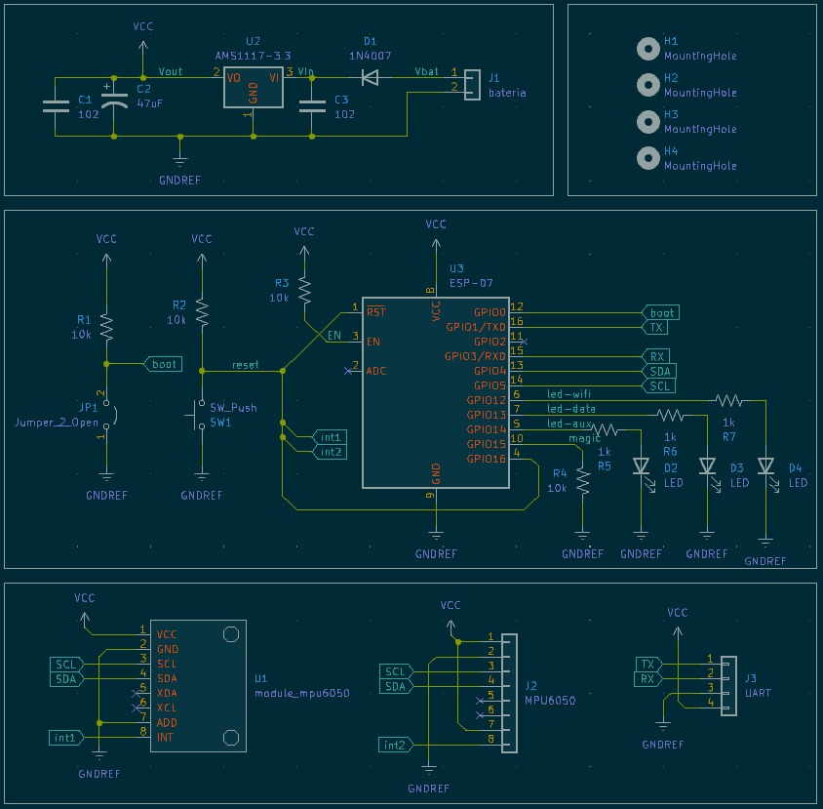
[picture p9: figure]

1. Alimentación: AMS1117-3.3 con C3 bulk y ceramicos de desacople cercanos; diodo 1N4007 serie desde batería como atajo temporal para ajustar Vbat.
2. RF/MCU: ESP-12 (ESP8266MOD) con antena integrada Rainsun y keep-out superior; GPIO mapeados a UART, I2C y LEDs.
3. Control de arranque: EN con pull-up, RESET por pulsador; pads para GPIO0 (modo flash).
4. IMU: conector para MPU6050 con SCL/SDA y INT.

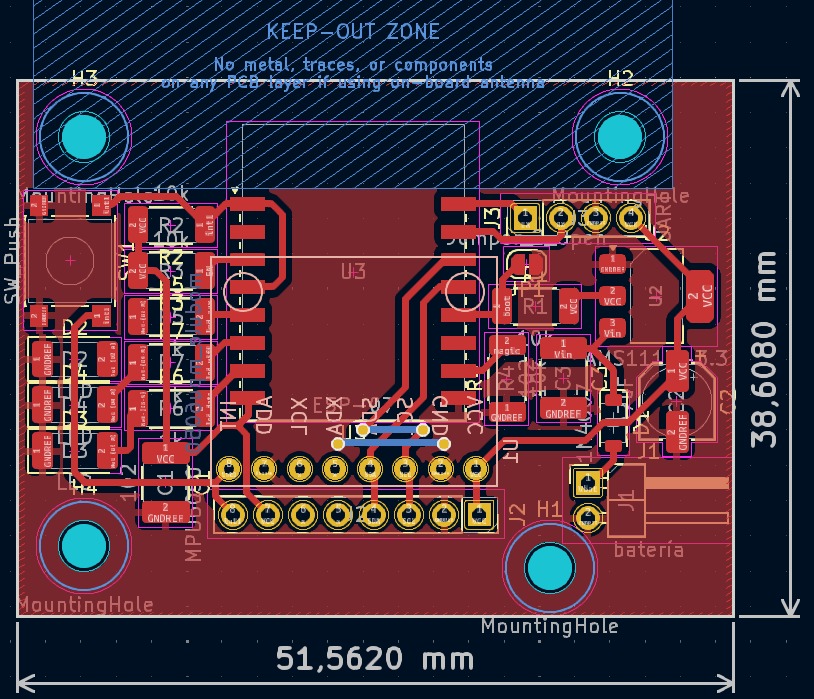
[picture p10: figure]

Ruteo con plano GND en top y via-stitching perimetral; colocacion SMD en bancos compactos para LEDs y RC de control; headers verticales para IMU/UART; keep-out RF claramente marcado.

Pinout efectivo (para trazabilidad de firmware)

Funcion | Pin ESP8266 | Conector | Nota
UART TX | GPIO1/TXD0 | J3-TX | Programacion/registro
UART RX | GPIO3/RXD0 | J3-RX | Programacion/registro
I2C SCL | GPIO5 | J2-SCL | Pull-ups en modulo IMU
I2C SDA | GPIO4 | J2-SDA | —
IMU INT | GPIO14 | J2-INT | Interrupciones de movimiento
LED Wi-Fi | GPIO12 | D? + R? | Estado radio
LED Datos | GPIO13 | D? + R? | Publicacion/actividad
LED Aux | GPIO16 | D? + R? | Uso general
EN (chip-enable) | EN | — | Pull-up
RESET | RST | SW1 | Pulsador a GND
BOOT/FLASH | GPIO0 | Pad/JP | Forzar modo programacion

### 10 Prototipo físico

Descripción general

Modulo de adquisicion autonomo montado en placa perforada (protoboard FR-4) con batería Li-ion plana como sustrato mecanico. El conjunto integra ESP8266 (ESP-01), IMU MPU6050 (GY-521), cargador/proteccion de batería Li-ion, y modulo DC-DC para acondicionamiento de tension. Se incorporan interruptor, pulsador de reset/usuario, LED de estado y test-pads para depuracion.

Componentes principales

Conjunto | Funcion | Observaciones de montaje
ESP8266 ESP-01 con soporte impreso | MCU + Wi-Fi | Soporte 3D para alivio de tension del conector;
| | disipador pasivo pequeno.
MPU6050 (GY-521) | Acelerometro/giroscopioMontado en el plano superior; acceso a
| | SDA/SCL en header.
Cargador/protector Li-ion | Carga 5 V y
| proteccion de celda | Entrada micro-USB; ubicado en cara inferior
| | junto a la batería.
DC-DC (ajustable) | Regulacion a 3.3 V | Modulo comercial; ajuste en 3.30 +- 0.03 V.
Batería Li-ion tipo “flat” | Fuente | Fijacion con cinta Kapton; cableado con alivio
| | termico.
Diodo serie (temporal) | Caida de ~0.7 V | Solucion transitoria para compatibilidad de
| | tension.
Interfaz | Interruptor,
| pulsador, LED | Acceso lateral; utiles para pruebas de banco.

Interconexión electrica (alto nivel)

- Batería -> cargador/proteccion -> DC-DC 3.3 V -> rail logica (ESP8266 + IMU).
- GPIO/UART: SDA/SCL expuestos; UART accesible para programacion.

Funcionalidad validada en banco

- Encendido estable a 3.3 V regulados.
- Lectura de IMU.
- Carga de batería por micro-USB y operacion en modo “cableado”.

Limitaciones actuales

- Regulación: uso de diodo de caida como solucion temporal; riesgo de subalimentacion cuando Vbat < 3.3 V + Vdrop.
- Mecanica: apilado con adhesivo caliente; se requiere placa SMD y separadores para rigidez y repetibilidad.
- Medición de consumo: sin shunt/INA dedicado; no hay perfil de corrientes por estado.
- Protección: sin TVS ni fusible rearmable en entrada; headers sin retencion.

Proximos pasos de mejora

1. Migrar a PCB v0.0.2 SMD con plano GND continuo bajo IMU y “via-stitching”.

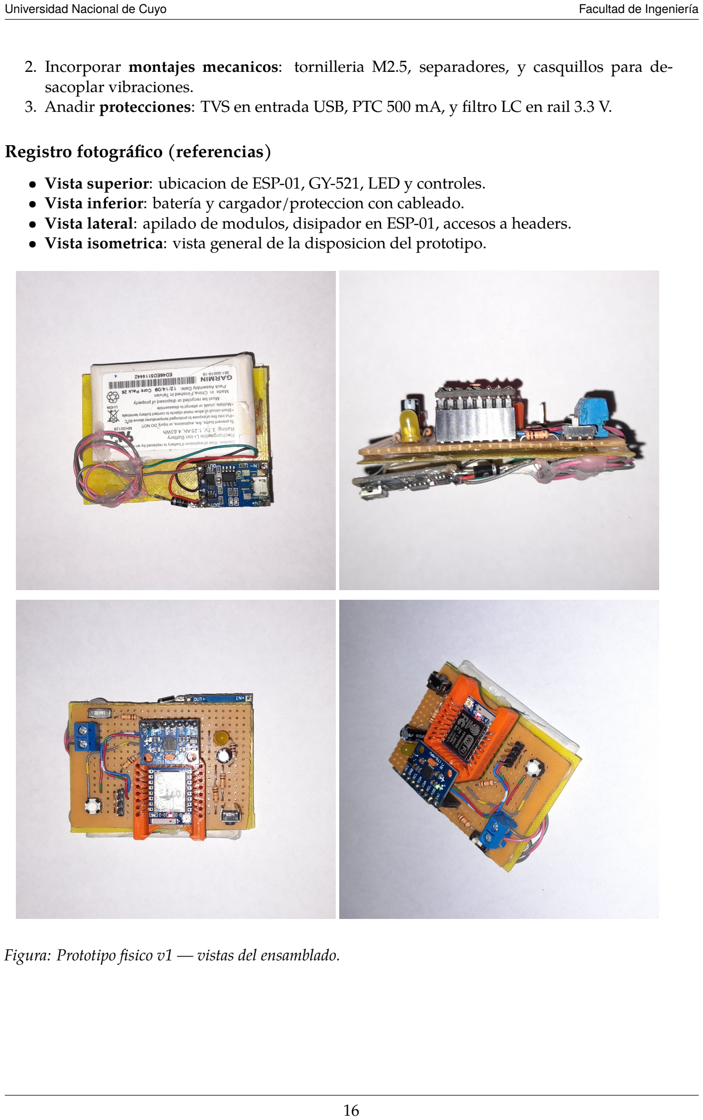
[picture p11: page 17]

2. Incorporar montajes mecanicos: tornilleria M2.5, separadores, y casquillos para desacoplar vibraciones.
3. Anadir protecciones: TVS en entrada USB, PTC 500 mA, y filtro LC en rail 3.3 V.

Registro fotográfico (referencias)

- Vista superior: ubicacion de ESP-01, GY-521, LED y controles.
- Vista inferior: batería y cargador/proteccion con cableado.
- Vista lateral: apilado de modulos, disipador en ESP-01, accesos a headers.
- Vista isometrica: vista general de la disposicion del prototipo.

Figura: Prototipo fisico v1 — vistas del ensamblado.

### 11 Firmware (ESP8266/ESP32)

Objetivo y alcance

El firmware temporiza la adquisicion con un timer periodico (200 Hz). La ISR solo encola un disparo; una tarea lee la IMU (MPU6050) por I2C en burst, aplica calibracion de offset (guardada en NVS/EEPROM) y llena un buffer de tamano fijo. Al completar el bloque, otra tarea empaqueta y publica por MQTT con QoS1; si no hay red, encola en SPIFFS para reenvio. El payload incluye ts_ms (marca de tiempo UTC en milisegundos del inicio del bloque), fs_hz, seq, n y las series crudas por canal. En ESP8266, el deep-sleep despierta por GPIO16→RST, por lo que el arranque rehidrata NTP/MQTT/IMU y seq. Adquirir datos crudos de la MPU6050 y publicarlos sin procesamiento local, delegando el posprocesado en el backend. Veanse §§14 y 15 para la integracion con deep-sleep y la justificacion de F_s.

Temporización y ejecución

- Temporizador periodico: genera una interrupcion cada T = 1/FSHZ para disparar la toma de muestra.
- ISR minima: coloca un “trigger” en una cola.
- Tarea de adquisición: toma el “trigger”, realiza lectura burst I2C del MPU6050, aplica calibracion y escribe la muestra cruda en un ring buffer.
- Tarea de publicacion: empaqueta bloques de N muestras y publica por MQTT (o los deja en cola local si no hay red).
- Deep-sleep (ESP8266): GPIO16 $\rightarrow$ RST produce reset; en setup() se rehidrata NTP/MQTT/IMU y se continua la secuencia seq.

Calibración del MPU6050 (compensación de offset)

Intención: remover sesgo de fabrica y de montaje.

1) Nodo inmovil 10-20 s.
2) Capturar N muestras.
3) Calcular medias por canal. Acel: bias_a[i]=mean(acc[i]) ajustando Z a ± 1 g; Giro: bias_g[i]=mean(gyro[i]). Guardar en NVS/EEPROM junto con temp_ref. En operacion: x_corr = x_raw − bias − k_temp*(temp − temp_ref) si se calibra termicamente. Criterio de aceptacion interno: var(acc) < 0.01 g.

MQTT: tópicos y payload

- Tópicos:

– sismo/<site>/<nodeId>/data (QoS1, no retenido)
– sismo/<site>/<nodeId>/status (QoS1, retenido, LWT=offline) – sismo/<site>/<nodeId>/cfg (QoS1, retenido)

ts_ms significa “timestamp en milisegundos desde epoca UNIX (UTC)”. En modo por bloques, ts_ms es el instante de la primera muestra del bloque. La separacion temporal entre muestras del bloque se infiere con fs_hz o con dt_us opcional.

Payload propuesto (bloques crudos, sin filtrado):

{
"ts_ms": 1730158805123,

"fs_hz": 200,
"seq": 15231,
"n": 100,
"ax": [ ... 100 valores ... ], "ay": [ ... 100 valores ... ], "az": [ ... 100 valores ... ], "gx": [ ... 100 valores ... ], "gy": [ ... 100 valores ... ], "gz": [ ... 100 valores ... ], "temp_c": 27.5,
"vbat": 3.92
}

Justificación de parametros:

- ts_ms y fs_hz permiten reconstruir el tiempo exacto de cada muestra en servidor.
- seq asegura idempotencia extremo a extremo junto al UNIQUE(nodo_id, measured_at, seq) en DB.
- n define tamano del bloque para decodificacion eficiente.
- temp_c habilita compensaciones termicas en analisis.
- vbat permite correlacionar eventos con caida de tension.

### 12 Cobertura y propagación (plan de medicion)

La performance depende del entorno (hormigon, acero, geometria de planta). Con la v0.0.2 se respeta el keep-out RF de antena; aun asi, se realizara un site-survey en dos pasos: (1) recorrido estatico con un nodo portatil registrando RSSI y tasa efectiva de publicacion; (2) prueba dinamica en horarios pico midiendo perdida y latencia “wake→publish” con deepsleep. Criterios de accion: si RSSI < -75 dBm sostenido o perdida > 1 % en 30 min, se define AP auxiliar o antena externa (ESP-07) y se reubican nodos. El backend usara status retenido + LWT para mapear disponibilidad por ubicacion.

### 13 Deep-sleep y “reset virtual” (ESP8266)

Es un hecho tecnico que en el microcontrolador ESP8266 el modo deep-sleep no “despierta” el programa donde quedo: reinicia el chip. El despertar se logra con la union GPIO16 (D0) → RST; al vencer el temporizador interno, GPIO16 impulsa RST y se produce un reset por hardware equivalente a un “software/virtual reset”.

Implicancias de diseno

- Re-hidratacion de estado: al iniciar, el firmware debe reconstruir NTP, MQTT, configuracion de IMU y contadores (seq) de forma idempotente.
- Persistencia minima: guardar en RTC/flash ligera: seq, ultimo ts, flags de “shutdown
limpio”.
- Tiempos de servicio: medir y reportar t_wake $\rightarrow$\rightarrow$\righta$\rightarrow$\rightarrow$row$ Wi-Fi $\rightarrow$\rightarrow$\rightarrow$\rightarrow$ publish (p95); los
costos de asociacion Wi-Fi dominan el consumo si el ciclo de sueno es corto.
- Senalizacion y LWT: publicar status=boot/deepsleep_wakeup y configurar LWT para
recuperacion en backend.

Requisito eléctrico

- Trazar GPIO16 → RST con retorno GND corto y mantener pull-ups de RST/EN segun datasheet. No conectar GPIO16 a otros perifericos.

Prueba minima

1. Programar deepSleep(us), verificar pulso en RST desde GPIO16.
2. Comprobar re-inicio completo y publicacion de status en <= 3 s tras el reset.

En ESP8266, deepSleep(us) despierta por pulso de GPIO16 a RST, equivalendo a un reset por hardware. El arranque debe sincronizar NTP, reconectar MQTT publicando status=deepsleep_wakeup, restaurar seq, reconfigurar la IMU y enviar/barrer cualquier bloque encolado en SPIFFS.

### 14 Backend y dashboard

Node-RED procesa la ingesta (validacion del esquema, construccion de SQL) y publica KPIs en un dashboard (disponibilidad por nodo, volumen por dia y graficos de aceleracion). La conexión a MySQL se realiza con TLS y usuarios de privilegios minimos.

### 15 Frecuencias de muestreo — justificación

Las vibraciones sismicas de interes estan en 0.5-30 Hz. Se adopta Fs = 200 Hz por sobre-muestreo >= 5x respecto de fmax y margen para transitorios y jitter; Nyquist queda en 100 Hz. Publicar por bloques a 200 Hz mantiene resolucion y un volumen de datos razonable; cualquier filtrado/decimado se realiza en servidor.

Justificación de frecuencias de muestreo

Las vibraciones sismicas estructurales de interes se concentran tipicamente entre 0.5 y 30 Hz. Para capturarlas sin distorsion y con margen de analisis, se adopta un factor de sobre-muestreo >= 5x respecto de la frecuencia maxima de interes:

Fs ≥ k ⋅ fmax con k ∈ [5, 10]

Con fmax = 30 Hz y k = 5 resulta Fs ≥ 150 Hz. Se fija Fs = 200 Hz por las siguientes razones:

1. deja banda util hasta 100 Hz (Nyquist) para cubrir picos transitorios o impactos por encima de 30 Hz;
2. mejora la estimacion de espectros y tiempos caracteristicos al contar con mas muestras por ciclo;
3. aporta robustez a jitter del temporizador y a pequenas derivas del bus I2C sin perder cobertura;
4. mantiene un coste de red razonable cuando se publica en bloques (sin filtrado en el nodo), dejando todo el posprocesamiento al servidor.

Parametros operativos asociados:

- FS_HZ = 200 define la frecuencia de adquisicion en el microcontrolador.
- PUB_BLOCK_SAMPLES controla el tamano del bloque publicado y, por ende, la latencia y el ancho de banda efectivo. Por ejemplo, PUB_BLOCK_SAMPLES = 100 implica bloques de 0.5 s a 200 Hz.

Este esquema garantiza resolucion suficiente para la banda 0.5-30 Hz con margen de analisis y sin carga de computo en el firmware, que solo mide y publica datos crudos.

### 16 Riesgos y mitigaciones

Energia (dropout y autonomia), RF/cobertura (areas sombra), DB/retencion (tamano y tiempos de consulta), robustez mecanica. Mitigaciones: buck-boost 3.3 V, site-survey y/o AP auxiliar, particionado temporal, pads de test y protecciones ESD/PTC.

Riesgos y mitigaciones

Riesgo | Efecto | Mitigacion
Picos de TX > 200 mA | Reset
| brown-out | Capacitores cerca del SoC y del regulador, ruta de
| | GND corta
Dropout en LDO | Apagado
| prematuro | Buck-boost o cutoff a Vbat que garantice 3.3 V
| | estable
Overhead de reconexion Wi-Fi | Aumenta ta | Persistir credenciales, aumentar DTIM, batch de
| | publicaciones
Deriva de consumo IMU | Baja
| autonomia | Cambiar a modo low-power accel entre eventos

### 17 Plan de proxima iteracion

Energia (mediciones por estado y decision de regulador), cobertura (site-survey y acciones), firmware (cola local y secuencia persistente), DB (particiones y vistas), instalacion piloto acotada.

Cronograma y plan de la siguiente iteracion

Objetivos verificables

- Crear un prototipo funcional de la placa de desarrollo v0.0.2 (SMD)
- Implementar cola local en firmware con reenvio y prueba de caida 10 min.
- Integrar TLS mutual en Mosquitto y validar ACLs por topico.
- Completar dashboard con espectro en ventana movil y alarmas.
- Ensayo de calibracion de 2 nodos y reporte de error con incertidumbre.

### 18 Anexos

Bibliografía y referencias

[1] Espressif Systems, “ESP8266EX Datasheet,” 2019. | [En linea]. | Disponible:
https://www.alldatasheet.com/datasheet-pdf/view/1148030/ESPRESSIF/ESP8266EX.html.
[2] Espressif Systems, “ESP8266EX Technical Reference,” v2.x. [En linea]. Disponible: https://docs.espressif.com/projects/esp8266-rtos-sdk/en/latest/.
[3] Espressif Systems, “ESP8266 RTOS SDK Programming Guide.” [En linea]. Disponible: https://documentation.espressif.com/en/home.

[4] TDK InvenSense, “MPU-6000 and MPU-6050 Product Specification,” Rev. 3.4. [En linea]. Disponible: https://www.alldatasheet.es/datasheet-pdf/view/517744/ETC1/MPU-6050.html.
[5] TDK InvenSense, “MPU-6050 Register Map and Descriptions,” Rev. 4.2. [En linea]. Disponible: https://invensense.tdk.com/.
[6] OASIS, “MQTT Version 3.1.1 Plus Errata 01,” OASIS Standard, Dec. 2015. [En linea]. Disponible: https://docs.oasis-open.org/mqtt/mqtt/.
[7] Eclipse Foundation, “Eclipse Mosquitto - Open Source MQTT Broker.” [En linea]. Disponible: https://mosquitto.org/.
[8] Node-RED Project, “Node-RED Documentation.” | [En linea]. | Disponible:
https://nodered.org/docs/.
[9] Oracle, | “MySQL 8.0 Reference Manual.” | [En linea]. | Disponible:
https://dev.mysql.com/doc/.
[10] D. Mills, J. Martin, J. Burbank, y W. Kasch, “Network Time Protocol Version 4: Protocol and Algorithms Specification,” RFC 5905, Jun. 2010. [En linea]. Disponible: https://www.rfceditor.org/rfc/rfc5905.
[11] Advanced Monolithic Systems, “AMS1117 Fixed 1A Low Dropout Linear Regulator,” Datasheet. [En linea]. Disponible: https://www.advanced-monolithic.com/.
[12] Espressif Systems, “ESP8266 Deep-sleep and Low Power Solutions,” App Notes. [En linea]. Disponible: https://docs.espressif.com/.
[13] TDK InvenSense, “Low-Power Accelerometer Operating Modes (Application Note),” s.
f. [En linea]. Disponible: https://invensense.tdk.com/.
[14] Proyecto Node-RED, “Node-RED Dashboard (UI) - Documentation.” [En linea]. Disponible: https://nodered.org/docs/user-guide/dashboard/.

Solicitudes al comite/directores (bloqueadores)

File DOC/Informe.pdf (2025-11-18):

UNIVERSIDAD NACIONAL DE CUYO

Facultad de Ingeniería

Red de nodos de adquisición de datos sismográficos.

Informe de avance - Versión 0.1


C A R R E R A | Ingeniería Mecatrónica
S E M E S T R E | Segundo Semestre 2025
C Á T E D R A | Proyecto Tipo C
A L U M N O S | Barrios Retta Federico , 14101
| Cano Francisco , 12487
| Pappeti Juan Ignacio , 11807
F E C H A | 03 de noviembre de 2025

### Contents

1 Resumen ejecutivo | 3
2 Trazabilidad de requerimientos actuales | 3
3 Problematica actual: la bateria de Li-ion | 4
4 Diseños de placas de Desarrollo | 5
5 Base de datos MySQL | 14
6 Firmware | 15
7 Cronograma y plan de la siguiente iteración | 19

Universidad Nacional de Cuyo | Facultad de Ingeniería
8 Solicitudes al comité/directores (bloqueadores) | 19
9 Bibliografia y Referencias | 19

### 1 Resumen ejecutivo

Alcance acordado: red de nodos sismográficos IoT con adquisición triaxial, backend MQTT+MySQL, dashboard.

### 1.1 Avances clave

- Diseño de placa de desarrollo v0.0.1 (THT) y v0.0.2 (SMD).
- Prototipo físico para dimensionamiento de dimensiones.
- Base de datos MySQL operativa.
- Análisis de energía y batería, con dificultades detectadas.
- Prototipo de firmware con timers/ISR para muestreo periódico (FreeRTOS).

### 1.2 Riesgos activos

- Autonomía real vs objetivo
- Deep sleep con reset
- Tensión de la pila de Li-ion difiere con Vcc de alimentación del microcontrolador
- Reconexión robusta tras sleep.

### 1.3 Próximos hitos

- Validación energética en banco
- Prototipo físico de la placa de desarrollo v0.0.2 (SMD)
- Inserción bulk y particionado en DB.

### 1.4 Diagrama de bloques (visión actual)


### 2 Trazabilidad de requerimientos actuales

Tabla simple: Requerimientos clave → Artefactos → Pruebas → Resultado

Req | Artefacto | Prueba | Estado
Muestreo estable (100–200 Hz) | FW timers/ISR | Jitter < 1% en 30 min | En curso
Persistencia | Esquema MySQL | Inserciones 1k msg/min 10 min | OK/Parcial
Autonomía mínima N horas | Modelo energía | Medición I y duty cycle | En riesgo

Req | Artefacto | Prueba | Estado
Reconexión tras deep sleep | FW estados | Publicación QoS1 en ≤3 s | Pendiente

### 3 Problematica actual: la bateria de Li-ion

La red de nodos requiere autonomía eléctrica para operar sin red fija. La fuente elegida es una celda Li-ion de factor de forma compacto (≤ 50 × 50 mm, espesor < 7.5 mm). El ESP8266 opera entre 2.5~3.6 V y presenta cuatro modos de potencia (activo, modem-sleep, light-sleep y deep-sleep). Según el datasheet del ESP8266EX (https://documentation.espressif.com/0a-esp8266ex_datasheet_en.pdf) , el consumo típico es: deep − sleep ≈ 20μA, light − sleep ≈ 0.9mA, modem − sleep ≈ 15mA, y en activo con radio el promedio ronda decenas de mA con picos de >100 mA en TX/RX (ver Tabla 3-4 “Power Consumption by Power Modes” y Tabla 1-1 “Specifications”).

El consumo del módulo MPU6050 se debe suponer hasta realizarse mediciones. Supuesto: la IMU MPU6050 añade ≈ 3–4 mA en adquisición continua y < 10 µA en modo low-power accel. Estos valores se validarán en banco.

Implicancia: la autonomía no la determina el consumo de 20μA en deep-sleep, sino el duty cycle real entre medir, transmitir y dormir. Además, el rango de tensión de la celda Li-ion (≈ 4.2 → 3.0V ) no es directamente compatible con la ventana 2.5–3.6V del ESP8266 si no se condiciona la tensión.

### 3.1 Restricciones de diseño

1. Tensión
- Batería Li-ion: 4.2 V (cargada) a ~3.0 V (descargada).
- ESP8266: 2.5–3.6 V.
- Conclusión: se requiere regulación.

– Un diodo en serie (≈ 0.7 V) reduce 4.2 → 3.5 V, pero colapsa a ~2.3 V cuando la celda cae a 3.0 V, bajo el mínimo del ESP8266. No es solución de producción. – Un LDO a 3.3 V desaprovecha la cola de la batería (cuando Vin < 3.3 V entra en dropout).
– Un buck a 3.3 V es eficiente por arriba de 3.3 V, pero no regula cuando Vin < 3.3 V.
2. Ciclo de operación Definimos un ciclo con tres estados:
- Activo (adquisición + TX): ESP8266 activo con radio, IMU activa.
- Idle/light-sleep: CPU o periféricos pausados, radio apagado.
- Deep-sleep: solo RTC operativo; en ESP8266 el wake implica reset del MCU.
3. Recuperación post-sleep El deep-sleep reinicia el ESP8266: se debe reconstruir estado (NTP, MQTT, seq, reconfiguración IMU) de forma idempotente.

### 3.2 Marco de cálculo de autonomía

Para un ciclo de duración T = ta + tl + td

con corrientes Ia

| | , Il , Id :

Considerando:

- T : duración total de un ciclo.

- ta
: tiempo en estado activo (adquisición + TX/RX).
- tl
: tiempo en light-sleep (CPU/periféricos en pausa, radio apagada).
- td
: tiempo en deep-sleep (solo RTC activo).
- Ia
: corriente media en estado activo.
- Il
: corriente media en light-sleep.
- Id
: corriente media en deep-sleep.

Iprom =

Ia

ta + Il

tl + Id

td
T

⇒ Autonomía (h) ≈

CmAh ⋅ η

Iprom

- Capacidad efectiva CmAh: nominal × factor de eficiencia η ∈ [0.8, 0.9] para pérdidas de regulador y temperatura.
- Supuestos iniciales (a validar): $ I_a=120 mA $ promedio durante TX y lectura, Il = 0.9 mA , Id = 20 μA. IMU activa suma ~4 mA en Ia y ~10 μA en bajo consumo.

Ejemplo de orden de magnitud (no compromiso de diseño): Si ta = 2 s, tl = 8 s, td = 50 s por ciclo de 60 s, entonces Iprom ≈

(124)(2)+(0.9)(8)+(0.02)(50)
60 | ≈ 4.5 mA. Con una celda 2000 mAh y
η = 0.85 →≈ 377ℎ teóricas. Pequeños cambios en ta o Ia derrumban la cifra, de ahí la necesidad de medir.

### 3.3 Riesgos y mitigaciones

Riesgo | Efecto | Mitigación
Picos de TX > 200 mA | Reset
| brown-out | Capacitores cerca del SoC y del regulador, ruta de
| | GND corta
Dropout en LDO | Apagado
| prematuro | Buck-boost o cutoff a Vbat que garantice 3.3 V
| | estable
Overhead de reconexión Wi-Fi | Aumenta ta | Persistir credenciales, aumentar DTIM, batch de
| | publicaciones
Deriva de consumo IMU | Baja
| autonomía | Cambiar a modo low-power accel entre eventos

### 4 Diseños de placas de Desarrollo

### 4.1 Prototipo físico

### 4.1.1 Descripción general

Módulo de adquisición autónomo montado en placa perforada (protoboard FR-4) con batería Li-ion plana como sustrato mecánico. El conjunto integra ESP8266 (ESP-01), IMU MPU6050 (GY-521), cargador/protección de batería Li-ion, y módulo DC-DC para acondicionamiento de tensión. Se incorporan interruptor, pulsador de reset/usuario, LED de estado y test-pads para depuración.

### 4.1.2 Componentes principales

Conjunto | Función | Observaciones de montaje
ESP8266 ESP-01 con soporte impreso | MCU + Wi-Fi | Soporte 3D para alivio de tensión del conector; disipador pasivo pequeño.

Conjunto | Función | Observaciones de montaje
MPU6050 (GY-521) | Acelerómetro/giroscopioMontado en el plano superior; acceso a
| | SDA/SCL en header.
Cargador/protector Li-ion | Carga 5 V y
| protección de celda | Entrada micro-USB; ubicado en cara inferior
| | junto a la batería.
DC-DC (ajustable) | Regulación a 3.3 V | Módulo comercial; ajuste en 3.30 ± 0.03 V.
Batería Li-ion tipo “flat” | Fuente | Fijación con cinta Kapton; cableado con alivio
| | térmico.
Diodo serie (temporal) | Caída de ~0.7 V | Solución transitoria para compatibilidad de
| | tensión.
Interfaz | Interruptor,
| pulsador, LED | Acceso lateral; útiles para pruebas de banco.

### 4.1.3 Interconexión eléctrica (alto nivel)

- Batería → cargador/protección → DC-DC 3.3 V → rail lógica (ESP8266 + IMU).
- GPIO/UA: SDA/SCL expuestos; UART accesible para programación.

### 4.1.4 Funcionalidad validada en banco

- Encendido estable a 3.3 V regulados.
- Lectura de IMU.
- Carga de batería por micro-USB y operación en modo “cableado”.

### 4.1.5 Limitaciones actuales

- Regulación: uso de diodo de caída como solución temporal; riesgo de subalimentación cuando Vbat < 3.3 V + Vdrop.
- Mecánica: apilado con adhesivo caliente; se requiere placa SMD y separadores para rigidez y repetibilidad.
- Medición de consumo: sin shunt/INA dedicado; no hay perfil de corrientes por estado.
- Protección: sin TVS ni fusible rearmable en entrada; headers sin retención.

### 4.1.6 Próximos pasos de mejora

1. Migrar a PCB v0.0.2 SMD con plano GND continuo bajo IMU y “via-stitching”.
2. Incorporar montajes mecánicos: tornillería M2.5, separadores, y casquillos para desacoplar vibraciones.
3. Añadir protecciones: TVS en entrada USB, PTC 500 mA, y filtro LC en rail 3.3 V.

### 4.1.7 Registro fotográfico (referencias)

- Vista superior: ubicación de ESP-01, GY-521, LED y controles.
- Vista inferior: batería y cargador/protección con cableado.
- Vista lateral: apilado de módulos, disipador en ESP-01, accesos a headers.
- Vista isométrica: vista general de la disposición del prototipo.

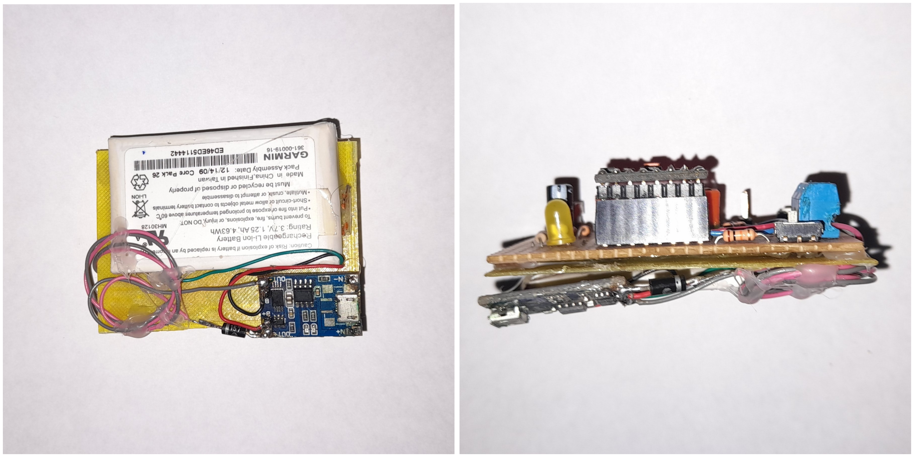
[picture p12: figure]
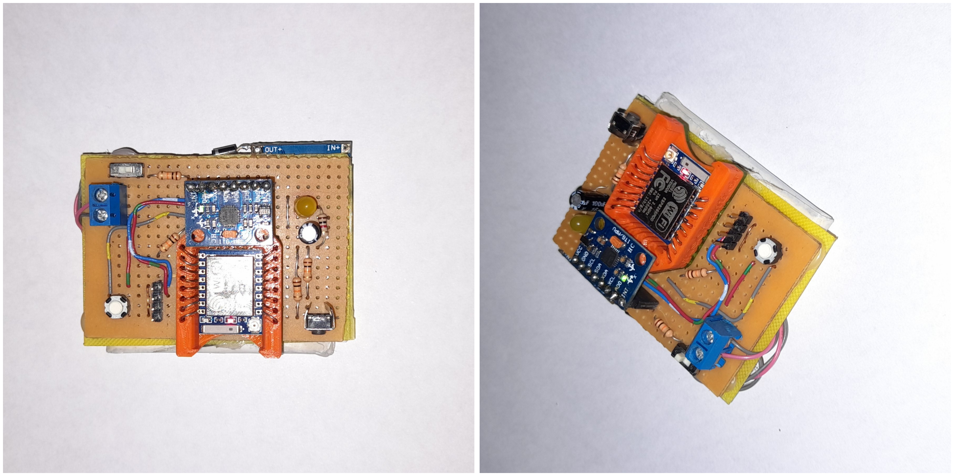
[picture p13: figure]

### 4.2 Placa de Desarrollo v0.0.1 (THT)

### 4.2.1 Descripción General

Se diseñó una primera revisión orientada a verificación funcional. La alimentación se resolvió con batería Li-ion, diodo serie y LDO AMS1117-3.3, suficiente para banco pero limitada en eficiencia y margen de caída. La lógica de arranque incluye pulsadores de BOOT y RESET con EN por pull-up. La IMU MPU6050 se conecta por I2C y expone INT al MCU. Se dispone de señalización mediante cuatro LEDs y de headers para UART y MPU6050.

- Formato: 61.98 × 33.02 mm, 4 orificios de montaje.
- Topología: batería Li-ion → diodo serie → LDO AMS1117-3.3 → rail 3V3 para ESP-07 y GY-521.
- Señalización: cuatro LEDs (Wi-Fi, datos, aux1, aux2) con resistencias limitadoras.
- Control: pulsadores de BOOT y RESET; EN con pull-up (R3).
- Interfaz: header UART para programación y header I2C/INT para IMU.
- Conectividad IMU: SCL/SDA, INT y AD0 cableados al conector J4 (módulo MPU6050).

4.2.2 3) Bloques y esquemas


1. Alimentación: AMS1117-3.3 con C1=47 µF de bulk y cerámicos de desacople (C2, C3). Diodo 1N4007 en serie desde batería como solución transitoria para reducir Vbat.
2. Control de arranque:
- BOOT con R1=10 kΩ a GND y pulsador a VCC para forzar modo flash cuando se requiera.
- RESET con R2=10 kΩ, pulsador a GND y EN con R3=10 kΩ a VCC.
3. MCU + IO: ESP-07 con GPIOs mapeados a UART, I2C y LEDs (R4–R7).


Ruteo de una cara con puentes; headers dedicados para UART y MPU6050. Se señalan keep-out y leyendas (autor, versión).

### 4.2.3 Pinout efectivo (para trazabilidad de firmware)

Función | Pin ESP8266 | Conector | Nota
UART TX | GPIO1/TXD0 | J2-TX | Programación/registro
UART RX | GPIO3/RXD0 | J2-RX | Programación/registro
I2C SCL | GPIO5 | J4-SCL | Pull-ups en módulo GY-521
I2C SDA | GPIO4 | J4-SDA | —
IMU INT | GPIO14 (int1) | J4-INT | Interrupciones de movimiento
LED Wi-Fi | GPIO12 | D1 + R4 | Estado radio
LED Datos | GPIO13 | D2 + R5 | Publicación/actividad
LED Aux 1 | GPIO15 | D3 + R6 | Uso general
LED Aux 2 | GPIO16 | D4 + R7 | Uso general
EN (chip-enable) | EN | — | Pull-up R3=10 kΩ
RESET | RST | SW2 | Pulsador a GND
BOOT | GPIO0 | SW1/JP1 | Forzar modo programación

### 4.2.4 Riesgos y mitigaciones (esta revisión)

Riesgo | Impacto | Mitigación en v0.0.2
Dropout con LDO + diodo Resets en TX | Buck-boost, cutoff Vbat
Falta de desacople correcto Ruido en IMU/MCU | 100 nF locales + 10 µF; trazas cortas

Riesgo | Impacto | Mitigación en v0.0.2
Sin medición de corriente | Autonomía incierta | Shunt/INA + pads Kelvin
Protección insuficiente | Sensibilidad a
| ESD/fallos | TVS, PTC, clearances y serigrafía

Con esto capitalizás las imágenes: el lector ve el esquema, entiende las rutas críticas, tiene tabla de pines para firmware y una lista clara de mejoras hacia v0.0.2.

### 4.2.5 Registro fotográfico (referencias)

- Vista superior: ubicación de ESP-01, GY-521, LED y controles.
- Vista inferior: batería y cargador/protección con cableado.
- Vista lateral: apilado de módulos, disipador en ESP-01, accesos a headers.
- Vista isométrica: vista general de la disposición del prototipo.

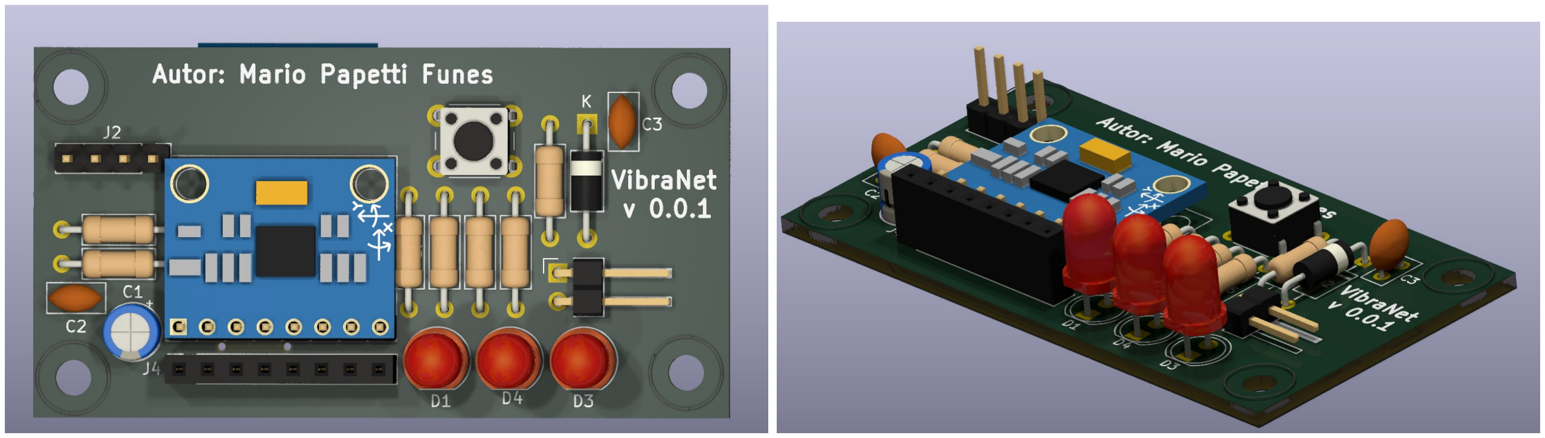
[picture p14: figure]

### 4.3 Placa de Desarrollo v0.0.2 (SMD)

### 4.3.1 Placa de Desarrollo v0.0.2 (SMD)

Descripción general Revisión orientada a compactar el diseño y mejorar DFM/EMI manteniendo la funcionalidad de la v0.0.1. Se migra a SMD con plano de masa continuo, keep-out para antena y headers accesibles para IMU y UART. La alimentación continúa con LDO AMS1117-3.3 + diodo serie como solución de banco, en espera de migrar a buck-boost 3.3 V en la siguiente iteración.

- Formato: 51.56 × 38.61 mm, 4 orificios de montaje.
- Topología: batería Li-ion → diodo serie → LDO AMS1117-3.3 → rail 3V3 para ESP-12 y conector MPU6050.

- Keep-out RF: zona superior libre de cobre y componentes sobre la antena integrada (serigrafía “KEEP-OUT ZONE”).
- Control: pulsador RESET, pad para BOOT/FLASH y EN con pull-up.
- Interfaz: header UART de programación y header I2C/INT para la IMU.
- Señalización: tres LEDs SMD para estado (Wi-Fi/datos/aux).


Bloques y esquemas

1. Alimentación: AMS1117-3.3 con C3 bulk y cerámicos de desacople cercanos; diodo 1N4007 serie desde batería como atajo temporal para ajustar Vbat.
2. RF/MCU: ESP-12 (ESP8266MOD) con antena integrada Rainsun y keep-out superior; GPIO mapeados a UART, I2C y LEDs.
3. Control de arranque: EN con pull-up, RESET por pulsador; pads para GPIO0 (modo flash).
4. IMU: conector para MPU6050 con SCL/SDA y INT.


Ruteo con plano GND en top y vía-stitching perimetral; colocación SMD en bancos compactos para LEDs y RC de control; headers verticales para IMU/UART; keep-out RF claramente marcado.

Pinout efectivo (para trazabilidad de firmware)

Función | Pin ESP8266 | Conector | Nota
UART TX | GPIO1/TXD0 | J3-TX | Programación/registro
UART RX | GPIO3/RXD0 | J3-RX | Programación/registro
I2C SCL | GPIO5 | J2-SCL | Pull-ups en módulo IMU
I2C SDA | GPIO4 | J2-SDA | —
IMU INT | GPIO14 | J2-INT | Interrupciones de movimiento
LED Wi-Fi | GPIO12 | D? + R? | Estado radio
LED Datos | GPIO13 | D? + R? | Publicación/actividad
LED Aux | GPIO16 | D? + R? | Uso general
EN (chip-enable) | EN | — | Pull-up
RESET | RST | SW1 | Pulsador a GND
BOOT/FLASH | GPIO0 | Pad/JP | Forzar modo programación

Registro render/fotográfico

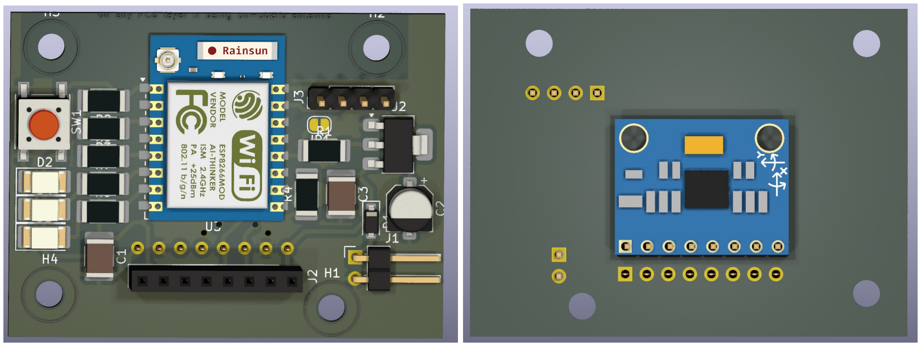
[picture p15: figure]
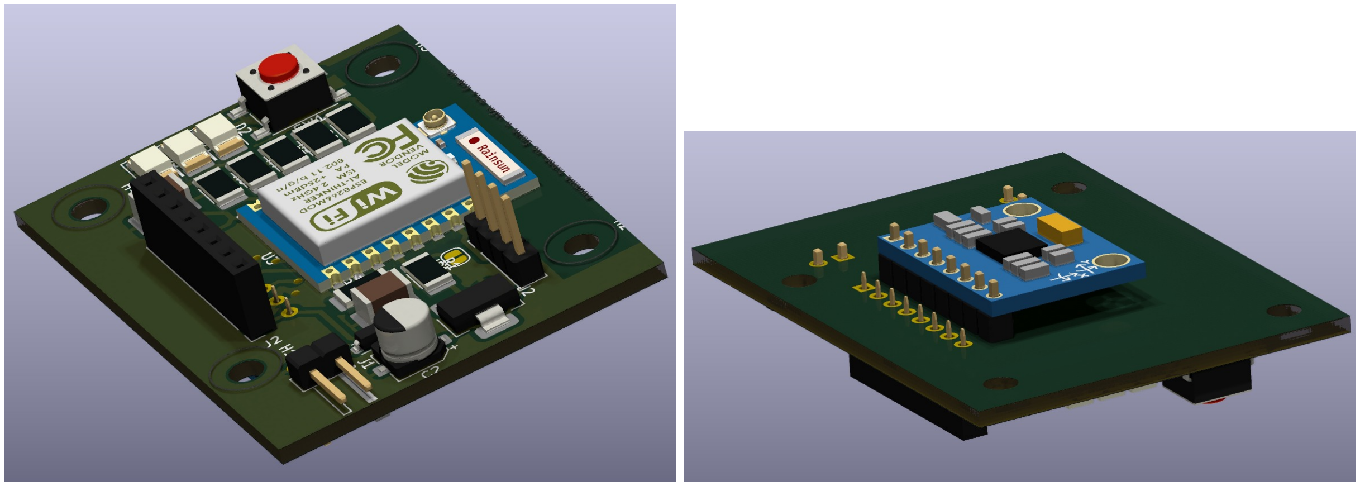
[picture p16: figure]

### 4.4 Deep-sleep y “reset virtual” (ESP8266)

Es un hecho técnico que en el microcontrolador ESP8266 el modo deep-sleep no “despierta” el programa donde quedó: reinicia el chip. El despertar se logra con la unión GPIO16 (D0) → RST; al vencer el temporizador interno, GPIO16 impulsa RST y se produce un reset por hardware equivalente a un “software/virtual reset”.

Implicancias de diseño

- Re-hidratación de estado: al iniciar, el firmware debe reconstruir NTP, MQTT, configuración de IMU y contadores (seq) de forma idempotente.
- Persistencia mínima: guardar en RTC/flash ligera: seq, último ts, flags de “shutdown limpio”.
- Tiempos de servicio: medir y reportar t_wake --> wifi --> publish (p95); los costos de asociación Wi-Fi dominan el consumo si el ciclo de sueño es corto.
- Señalización y LWT: publicar status=boot/deepsleep_wakeup y configurar LWT para recuperación en backend.

Requisito eléctrico

- Trazar GPIO16 → RST con retorno GND corto y mantener pull-ups de RST/EN según datasheet. No conectar GPIO16 a otros periféricos.

Prueba mínima

1. Programar deepSleep(us), verificar pulso en RST desde GPIO16.
2. Comprobar re-inicio completo y publicación de status en ≤ 3 s tras el reset.

### 5 Base de datos MySQL

### 5.1 Objetivo

Almacenar mediciones por nodo con trazabilidad mínima y consultas rápidas por ventana temporal, usando UTC con milisegundos. El diagrama proporcionado es la referencia del modelo: cliente posee sistemas; cada sistema agrupa nodos; cada nodo genera mediciones; los usuarios acceden por rol mediante una tabla de relación.

### 5.2 Modelo lógico

Tablas de administración: cliente, sistema, usuario, usuario_sistema. Tablas operativas: nodo (metadatos, keep-alive, habilitación) y mediciones (serie temporal). Identificadores BIG-INT autoincrementales y campos created_at, updated_at, deleted_at en DATETIME(3) para auditoría y soft-delete. Códigos legibles (*_code) únicos para direccionamiento desde flujos y UI.

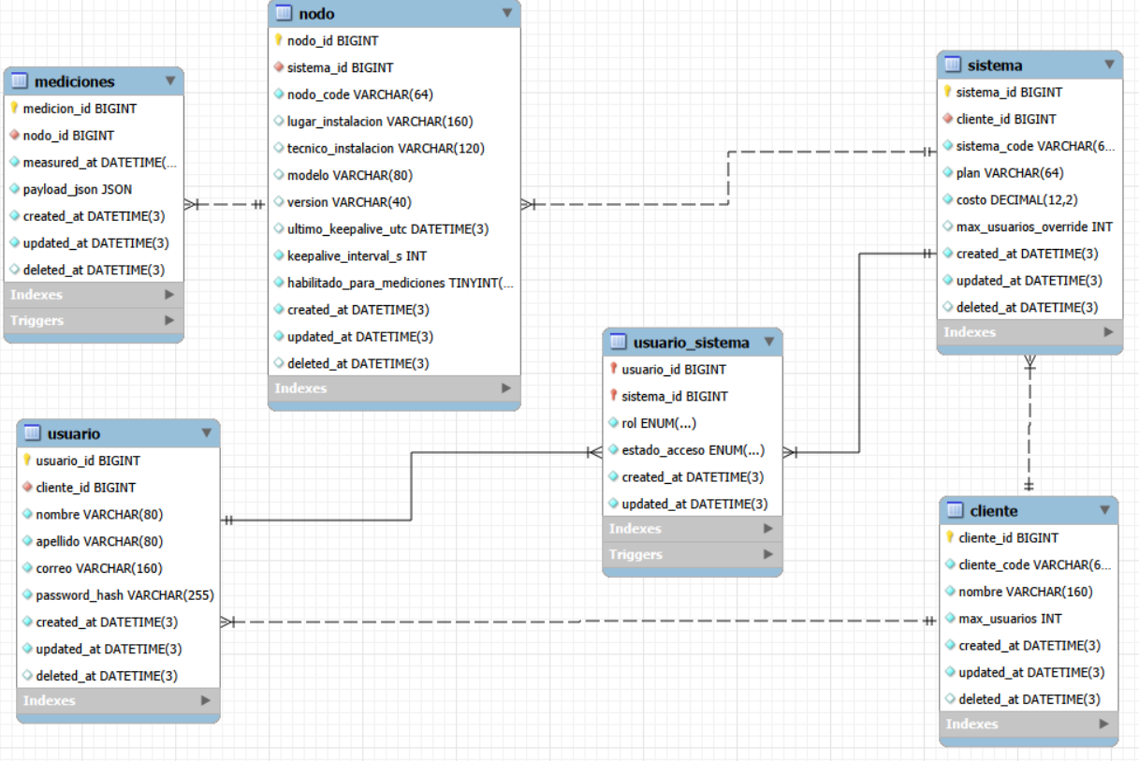
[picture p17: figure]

### 5.3 Tabla central

mediciones guarda el instante de captura y el payload crudo en JSON, más columnas generadas para filtrar por secuencia, frecuencia de muestreo y tensión de batería. Se impone unicidad por (nodo_id, measured_at, seq) para lograr ingesta idempotente y evitar duplicados ante reintentos.

CREATE TABLE mediciones (
medicion_id BIGINT UNSIGNED PRIMARY KEY AUTO_INCREMENT,
nodo_id BIGINT UNSIGNED NOT NULL,
measured_at DATETIME(3) NOT NULL, | -- UTC
payload_json JSON NOT NULL, | -- ax, ay, az, fs_hz, seq, vbat...
seq | INT | GENERATED ALWAYS AS (CAST(JSON_UNQUOTE(JSON_EXTRACT(payload_json,'$.seq')) | AS UNSIGNED)) STORED,
fs_hz SMALLINT GENERATED ALWAYS AS (CAST(JSON_UNQUOTE(JSON_EXTRACT(payload_json,'$.fs_hz')) AS UNSIGNED)) STORED, vbat DECIMAL(4,2) GENERATED ALWAYS AS (CAST(JSON_UNQUOTE(JSON_EXTRACT(payload_json,'$.vbat')) AS DECIMAL(4,2))) STORED, created_at DATETIME(3) NOT NULL DEFAULT CURRENT_TIMESTAMP(3),
updated_at DATETIME(3) NOT NULL DEFAULT CURRENT_TIMESTAMP(3) ON UPDATE CURRENT_TIMESTAMP(3),
UNIQUE KEY uk_med (nodo_id, measured_at, seq),
KEY k_nodo_ts (nodo_id, measured_at),
CONSTRAINT fk_med_nodo FOREIGN KEY (nodo_id) REFERENCES nodo(nodo_id)
) ENGINE=InnoDB;

### 5.4 Ingesta (idempotente)

El flujo de Node-RED inserta usando INSERT ... ON DUPLICATE KEY UPDATE, con tres parámetros: nodo_id (identidad del dispositivo), ts_ms (marca de tiempo en milisegundos convertida a DATETIME(3) UTC) y payload_json (mensaje validado).

INSERT INTO mediciones (nodo_id, measured_at, payload_json)
VALUES (?nodo_id, FROM_UNIXTIME(?ts_ms/1000), ?payload_json)
ON DUPLICATE KEY UPDATE payload_json = VALUES(payload_json), updated_at = CURRENT_TIMESTAMP(3);

### 5.5 Consulta típica

Para graficar una ventana temporal por nodo se filtra por nodo_id y rango de measured_at, aprovechando el índice k_nodo_ts.

SELECT measured_at, payload_json
FROM mediciones
WHERE nodo_id = ? AND measured_at BETWEEN ?ini AND ?fin ORDER BY measured_at;

### 5.6 Particionado y operación

Se recomienda particionar mediciones por rango mensual de measured_at para mantener índices compactos y facilitar la retención de crudos (p. ej., 180 días). El acceso desde Node-RED debe ir por TLS y con privilegios mínimos; la UI solo requiere SELECT.

Roles propuestos: - ingestor (INSERT/SELECT en mediciones y SELECT en nodo) -dashboard (SELECT) - admin_db (DDL/particiones).

### 6 Firmware

### 6.1 Objetivo y alcance

Adquirir datos crudos de la MPU6050 con temporización estable y publicarlos por MQTT con marca de tiempo en milisegundos UTC. El microcontrolador no filtra ni procesa: solo mide y publica. Todo posprocesado (filtros, espectros, KPIs) corre en el servidor.

### 6.2 Justificación de frecuencias de muestreo

Las vibraciones sísmicas estructurales de interés se concentran típicamente entre 0.5 y 30 Hz. Para capturarlas sin distorsión y con margen de análisis, se adopta un factor de sobre-muestreo ≥ 5 × respecto de la frecuencia máxima de interés:

Fs ≥ k ⋅ fmax con k ∈ [5, 10]

Con fmax = 30, Hz y k = 5 resulta Fs ≥ 150 Hz. Se fija Fs = 200 Hz por las siguientes razones:

1. deja banda útil hasta 100 Hz (Nyquist) para cubrir picos transitorios o impactos por encima de 30 Hz;
2. mejora la estimación de espectros y tiempos característicos al contar con más muestras por ciclo;
3. aporta robustez a jitter del temporizador y a pequeñas derivas del bus I2C sin perder cobertura;
4. mantiene un coste de red razonable cuando se publica en bloques (sin filtrado en el nodo), dejando todo el posprocesamiento al servidor.

Parámetros operativos asociados:

- FS_HZ = 200 define la frecuencia de adquisición en el microcontrolador.
- PUB_BLOCK_SAMPLES controla el tamaño del bloque publicado y, por ende, la latencia y el ancho de banda efectivo. Por ejemplo, PUB_BLOCK_SAMPLES = 100 implica bloques de 0.5 s a 200 Hz.

Este esquema garantiza resolución suficiente para la banda 0.5–30 Hz con margen de análisis y sin carga de cómputo en el firmware, que solo mide y publica datos crudos.

### 6.3 Temporización y ejecución

- Temporizador periódico: genera una interrupción cada T = 1/FSHZ para disparar la toma de muestra.
- ISR mínima: coloca un “trigger” en una cola.
- Tarea de adquisición: toma el “trigger”, realiza lectura burst I2C del MPU6050, aplica calibración y escribe la muestra cruda en un ring buffer.
- Tarea de publicación: empaqueta bloques de N muestras y publica por MQTT (o los deja en cola local si no hay red).
- Deep-sleep (ESP8266): GPIO16 --> RST produce reset; en setup() se rehidrata NTP/MQTT/IMU y se continúa la secuencia seq.

### 6.4 Calibración del MPU6050 (compensación de offset)

Intención: remover sesgo de fábrica y de montaje.

1) Nodo inmóvil 10–20 s.
2) Capturar N muestras.
3) Calcular medias por canal. Acel: bias_a[i]=mean(acc[i]) ajustando Z a ± 1 g; Giro: bias_g[i]=mean(gyro[i]). Guardar en NVS/EEPROM junto con temp_ref. En operación: x_corr = x_raw − bias − k_temp*(temp − temp_ref) si se calibra térmicamente. Criterio de aceptación interno: var(acc) < 0.01 g.

### 6.5 MQTT: tópicos y payload

- Tópicos:

– sismo/<site>/<nodeId>/data (QoS1, no retenido)
– sismo/<site>/<nodeId>/status (QoS1, retenido, LWT=offline)

– sismo/<site>/<nodeId>/cfg (QoS1, retenido)

ts_ms significa “timestamp en milisegundos desde época UNIX (UTC)”. En modo por bloques, ts_ms es el instante de la primera muestra del bloque. La separación temporal entre muestras del bloque se infiere con fs_hz o con dt_us opcional.

Payload propuesto (bloques crudos, sin filtrado):

{
"ts_ms": 1730158805123, | // UTC de la PRIMERA muestra del bloque
"fs_hz": 200, | // frecuencia de adquisición en el MCU
"seq": 15231, | // contador de bloque (monótono, persiste entre resets)
"n": 100, | // muestras por canal en este bloque
"ax": [ ... 100 valores ... ],
"ay": [ ... 100 valores ... ],
"az": [ ... 100 valores ... ],
"gx": [ ... 100 valores ... ],
"gy": [ ... 100 valores ... ],
"gz": [ ... 100 valores ... ],
"temp_c": 27.5, | // temperatura IMU durante el bloque (media)
"vbat": 3.92 | // tensión de batería al cerrar el bloque
}

Justificación de parámetros:

- ts_ms y fs_hz permiten reconstruir el tiempo exacto de cada muestra en servidor.
- seq asegura idempotencia extremo a extremo junto al UNIQUE(nodo_id, measured_at, seq) en DB.
- n define tamaño del bloque para decodificación eficiente.
- temp_c habilita compensaciones térmicas en análisis.
- vbat permite correlacionar eventos con caída de tensión.

### 6.6 Código de referencia (ESP32 FreeRTOS; crudo → bloque → MQTT)

Intención: ISR mínima, adquisición I2C con calibración, publicación por bloques, sin filtros en MCU.

// ---- Parámetros clave ----
constexpr uint16_t FS_HZ = 200; | // adquisición cruda
constexpr uint16_t PUB_BLOCK_SAMPLES = 100; | // tamaño de bloque (0.5 s)
constexpr uint32_t T_US = 1000000UL / FS_HZ; | // periodo en microsegundos

struct Calib { float ax, ay, az, gx, gy, gz, t_ref; } gCal;
struct Sample { uint32_t t_us; float ax, ay, az, gx, gy, gz; float temp; };

static QueueHandle_t qTrig;
static hw_timer_t* timer0 = nullptr;

// --- ISR: solo notifica tiempo ---
void IRAM_ATTR onTimerISR() {
BaseType_t hp = pdFALSE;
uint32_t t = (uint32_t) esp_timer_get_time(); xQueueSendFromISR(qTrig, &t, &hp);
if (hp) portYIELD_FROM_ISR();

}

// --- Buffer de muestras crudas ---
static Sample rb[PUB_BLOCK_SAMPLES];
static volatile uint16_t rb_idx = 0;

// --- Tarea de adquisición: I2C + calibración ---void taskAcquire(void*){
for(;;){
uint32_t t_us;
if (xQueueReceive(qTrig, &t_us, portMAX_DELAY)) {
int16_t ra[3], rg[3]; float temp;
mpu6050_read_raw_burst(ra, rg, &temp); | // lectura atómica

Sample s;
s.t_us = t_us;
s.ax = ra[0]*ACC_SCALE - gCal.ax;
s.ay = ra[1]*ACC_SCALE - gCal.ay; s.az = ra[2]*ACC_SCALE - gCal.az; s.gx = rg[0]*GYR_SCALE - gCal.gx; s.gy = rg[1]*GYR_SCALE - gCal.gy; s.gz = rg[2]*GYR_SCALE - gCal.gz; s.temp = temp;

rb[rb_idx++] = s;
if (rb_idx >= PUB_BLOCK_SAMPLES) {
rb_idx = 0;
notify_block_ready(); | // señal a publicador
}
}
}
}

// --- Tarea de publicación: empaqueta y envía bloque ---void taskPublish(void*){
static uint32_t seq = load_seq_from_nvs();
for(;;){
if (block_ready()){
// construir JSON (o CBOR) con ts_ms de la primera muestra: uint64_t ts_ms = to_unix_ms(rb[0].t_us); // NTP base + offset local JsonDoc doc;
doc["ts_ms"] = ts_ms;
doc["fs_hz"] = FS_HZ;
doc["seq"] | = seq++;
doc["n"] | = PUB_BLOCK_SAMPLES;
append_arrays_from_rb(rb, PUB_BLOCK_SAMPLES, doc); // ax..gz, temp/vbat

if (net_ok()) mqtt_publish_qos1("sismo/siteX/nodeY/data", doc);
else spiffs_enqueue(doc);

save_seq_to_nvs(seq);

} else {
vTaskDelay(pdMS_TO_TICKS(1)); }
}
}

void setup(){
// NTP (UTC), MQTT con LWT retenido, carga de calibración y seq load_calibration(&gCal);

qTrig = xQueueCreate(64, sizeof(uint32_t));
timer0 = timerBegin(0, 80, true); | // 80 MHz / 80 = 1 MHz
timerAttachInterrupt(timer0, &onTimerISR, true);
timerAlarmWrite(timer0, T_US, true);
timerAlarmEnable(timer0);

xTaskCreatePinnedToCore(taskAcquire, "acq", 4096, nullptr, 3, nullptr, 0); xTaskCreatePinnedToCore(taskPublish, "pub", 6144, nullptr, 2, nullptr, 1); }

ESP8266 | (sin | FreeRTOS): | sustituir | hw_timer_t | por | Timer1, | y
notify_block_ready()/block_ready() por una cola circular en “loop cooperativo”. El resto del flujo se mantiene igual.

### 6.7 Deep-sleep y “reset virtual”

En ESP8266, deepSleep(us) despierta por pulso de GPIO16 a RST, equivalendo a un reset por hardware. El arranque debe: sincronizar NTP, reconectar MQTT publicando status=deepsleep_wakeup, restaurar seq, reconfigurar IMU y enviar/barrer cualquier bloque encolado en SPIFFS.

### 7 Cronograma y plan de la siguiente iteración

Objetivos verificables

- Crear un prototípo funcional de la placa de desarrollo v0.0.2 (SMD)
- Implementar cola local en firmware con reenvío y prueba de caída 10 min.
- Integrar TLS mutual en Mosquitto y validar ACLs por tópico.
- Completar dashboard con espectro en ventana móvil y alarmas.
- Ensayo de calibración de 2 nodos y reporte de error con incertidumbre.

### 8 Solicitudes al comité/directores (bloqueadores)

### 9 Bibliografia y Referencias

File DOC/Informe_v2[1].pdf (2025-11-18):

UNIVERSIDAD NACIONAL DE CUYO

Facultad de Ingeniería

Red de nodos de adquisición de datos sismográficos.

Informe de avance - Versión 0.2


C A R R E R A | Ingeniería Mecatrónica
S E M E S T R E | Segundo Semestre 2025
C Á T E D R A | Proyecto Tipo C
A L U M N O S | Barrios Retta Federico , 14101
| Cano Francisco , 12487
| Pappeti Juan Ignacio , 11807
F E C H A | 03 de noviembre de 2025

### Contents

1 Resumen ejecutivo | 3
2 Contexto y objetivos | 3
3 Alcance y trazabilidad | 3
4 Trazabilidad de requerimientos actuales | 3
5 Arquitectura general (E2E) | 4
6 Selección de plataforma MCU y módulos Wi-Fi | 4
7 Micro-investigación del mercado | 4
8 Diseño HW — Placa v0.0.1 (THT) | 4
9 Problemática de energia — Batería Li-ion | 7
10 Diseño HW — Placa v0.0.2 (SMD) | 9
11 Prototipo físico | 12
12 Firmware (ESP8266/ESP32) | 14
13 Cobertura y propagación (plan de medicion) | 15

Universidad Nacional de Cuyo | Facultad de Ingeniería
14 Deep-sleep y “reset virtual” (ESP8266) | 15
15 Frecuencias de muestreo — justificación | 16
16 Base de datos (MySQL) — resumen operativo | 17
17 Backend y dashboard | 18
18 Riesgos y mitigaciones | 19
19 Plan de proxima iteracion | 19
20 Anexos | 19

### 1 Resumen ejecutivo

Alcance acordado: red de nodos sismográficos IoT con adquisición triaxial, backend MQTT+MySQL, dashboard.

### 1.1 Avances clave

- Diseño de placa de desarrollo v0.0.1 (THT) y v0.0.2 (SMD).
- Prototipo físico para dimensionamiento de dimensiones.
- Base de datos MySQL operativa.
- Análisis de energía y batería, con dificultades detectadas.
- Prototipo de firmware con timers/ISR para muestreo periódico (FreeRTOS).

### 1.2 Riesgos activos

- Autonomía real vs objetivo
- Deep sleep con reset
- Tensión de la pila de Li-ion difiere con Vcc de alimentación del microcontrolador
- Reconexión robusta tras sleep.

### 1.3 Próximos hitos

- Validación energética en banco
- Prototipo físico de la placa de desarrollo v0.0.2 (SMD)
- Inserción bulk y particionado en DB.

### 2 Contexto y objetivos

Este piloto aborda el monitoreo de vibraciones estructurales en banda 0.5-30 Hz mediante una red de nodos IoT que adquieren y publican datos crudos para su procesamiento en servidor. Objetivos medibles del corte: (i) adquisicion estable a 200 Hz y publicacion por bloques; (ii) exactitud ≤ 10% tras calibracion estatica de la IMU; (iii) disponibilidad de ingesta continua (MQTT→Node-RED→MySQL) y consultas por ventana temporal en dashboard.

### 3 Alcance y trazabilidad

### 4 Trazabilidad de requerimientos actuales

Tabla simple: Requerimientos clave → Artefactos → Pruebas → Resultado

Req | Artefacto | Prueba | Estado
Muestreo estable (100–200 Hz) | FW timers/ISR | Jitter < 1% en 30 min | En curso
Persistencia | Esquema MySQL | Inserciones 1k msg/min 10 min | OK/Parcial
Autonomía mínima N horas | Modelo energía | Medición I y duty cycle | En riesgo
Reconexión tras deep sleep | FW estados | Publicación QoS1 en ≤3 s | Pendiente

### 5 Arquitectura general (E2E)

### 5.1 Diagrama de bloques (visión actual)


### 6 Selección de plataforma MCU y módulos Wi-Fi

La iteracion actual adopta ESP8266 por costo, disponibilidad local y suficiencia para el objetivo de esta fase: adquirir y publicar datos crudos (sin procesamiento en el nodo). ESP32 queda como ruta de crecimiento (mas RAM/flash, doble core, BLE, FreeRTOS nativo) si en validacion aparecen limites en latencia de reconexion, TLS mutuo o colas locales. La migracion ESP-01 → ESP-07/ESP-12 obedecio a dos necesidades: mas GPIO utiles (I2C + INT + senales de estado sin “malabares”) y mejor diseno RF con keep-out sobre la antena y opcion de antena externa (ESP-07) para pruebas de cobertura. En esta etapa se optimiza el I/O minimo y la RF antes de escalar complejidad de computo.

### 7 Micro-investigación del mercado

El monitoreo de vibraciones se usa en CMS industrial (fallas en rodamientos, desbalances) y en estructuras civiles (SHM, vibraciones de suelo). El relevamiento del equipo situa cuatro niveles de costo: transmisores 4-20 mA (~USD 200-600), acelerometros industriales (~USD 500-1 500), nodos IIoT integrados (~USD 1 000-2 500) y analizadores portatiles (USD 3 000-15 000+). El proyecto se posiciona como nodo IoT academico/de bajo costo con stack abierto (MQTT + MySQL + Node-RED) para banda 0.5-30 Hz en edificaciones, aceptando como tradeoff la necesidad de ensayos de exactitud y confiabilidad para cerrar la brecha con equipos industriales.

### 8 Diseño HW — Placa v0.0.1 (THT)

### 8.1 Placa de Desarrollo v0.0.1 (THT)

### 8.1.1 Descripción General

Se diseno una primera revision orientada a verificacion funcional. La alimentacion se resolvio con batería Li-ion, diodo serie y LDO AMS1117-3.3, suficiente para banco pero limitada en eficiencia y margen de caida. La logica de arranque incluye pulsadores de BOOT y RESET con EN por pull-up. La IMU MPU6050 se conecta por I2C y expone INT al MCU. Se dispone de senalizacion mediante cuatro LEDs y de headers para UART y MPU6050.

- Formato: 61.98 × 33.02 mm, 4 orificios de montaje.

- Topologia: batería Li-ion → diodo serie → LDO AMS1117-3.3 → rail 3V3 para ESP-07 y GY-521.
- Senalizacion: cuatro LEDs (Wi-Fi, datos, aux1, aux2) con resistencias limitadoras.
- Control: pulsadores de BOOT y RESET; EN con pull-up (R3).
- Interfaz: header UART para programacion y header I2C/INT para IMU.
- Conectividad IMU: SCL/SDA, INT y AD0 cableados al conector J4 (modulo MPU6050).

8.1.2 3) Bloques y esquemas


1. Alimentacion: AMS1117-3.3 con C1=47 μF de bulk y ceramicos de desacople (C2

, C3
).
Diodo 1N4007 en serie desde batería como solucion transitoria para reducir Vbat.
2. Control de arranque:
- BOOT con R1 = 10kΩ a GND y pulsador a VCC para forzar modo flash cuando se requiera.
- RESET con R2 = 10kΩ, pulsador a GND y EN con R3 = 10kΩ a VCC.
3. MCU + IO: ESP-07 con GPIOs mapeados a UART, I2C y LEDs (R4 − R7
).


Ruteo de una cara con puentes; headers dedicados para UART y MPU6050. Se senalan keep-out y leyendas (autor, version).

### 8.1.3 Pinout efectivo (para trazabilidad de firmware)

Funcion | Pin ESP8266 | Conector | Nota
UART TX | GPIO1/TXD0 | J2-TX | Programacion/registro
UART RX | GPIO3/RXD0 | J2-RX | Programacion/registro
I2C SCL | GPIO5 | J4-SCL | Pull-ups en modulo GY-521
I2C SDA | GPIO4 | J4-SDA | —
IMU INT | GPIO14 (int1) | J4-INT | Interrupciones de movimiento
LED Wi-Fi | GPIO12 | D1 + R4 | Estado radio
LED Datos | GPIO13 | D2 + R5 | Publicacion/actividad
LED Aux 1 | GPIO15 | D3 + R6 | Uso general
LED Aux 2 | GPIO16 | D4 + R7 | Uso general
EN (chip-enable) | EN | — | Pull-up R3 = 10kΩ
RESET | RST | SW2 | Pulsador a GND
BOOT | GPIO0 | SW1/JP1 | Forzar modo programacion

### 8.1.4 Riesgos y mitigaciones

Riesgo | Impacto | Mitigacion en v0.0.2
Dropout con LDO + diodo Resets en TX | Buck-boost, cutoff Vbat
Falta de desacople correcto Ruido en IMU/MCU | 100 nF locales + 10 μF; trazas cortas

Riesgo | Impacto | Mitigacion en v0.0.2
Sin medicion de corriente | Autonomia incierta | Shunt/INA + pads Kelvin
Proteccion insuficiente | Sensibilidad a
| ESD/fallos | TVS, PTC, clearances y serigrafia

### 8.1.5 Registro fotográfico (referencias)

- Vista superior: ubicacion de ESP-01, GY-521, LED y controles.
- Vista inferior: batería y cargador/proteccion con cableado.
- Vista lateral: apilado de modulos, disipador en ESP-01, accesos a headers.
- Vista isometrica: vista general de la disposicion del prototipo.


Figura: Vibranet v0.0.1 (vistas del prototipo THT).

### 9 Problemática de energia — Batería Li-ion

La red de nodos requiere autonomia electrica para operar sin red fija. La fuente elegida es una celda Li-ion de factor de forma compacto (≤ 50 × 50 mm, espesor < 7.5 mm). El ESP8266 opera entre 2.5-3.6 V y presenta cuatro modos de potencia (activo, modem-sleep, light-sleep y deep-sleep). Segun el datasheet del ESP8266EX (https://documentation.espressif.com/0a-esp8266ex_datasheet_en.pdf) , el consumo tipico es: deep-sleep ≈ 20μA, light-sleep ≈ 0.9mA, modem-sleep ≈ 15mA, y en activo con radio el promedio ronda decenas de mA con picos de >100 mA en TX/RX (ver Tabla 3-4 “Power Consumption by Power Modes” y Tabla 1-1 “Specifications”).

El consumo del modulo MPU6050 se debe suponer hasta realizarse mediciones. Supuesto: la IMU MPU6050 anade ≈ 3-4 mA en adquisicion continua y < 10 μA en modo low-power accel. Estos valores se validaran en banco.

Implicancia: la autonomia no la determina el consumo de 20μA en deep-sleep, sino el duty cycle real entre medir, transmitir y dormir. Ademas, el rango de tension de la celda Li-ion (≈ 4.2 → 3.0V ) no es directamente compatible con la ventana 2.5 − 3.6V del ESP8266 si no se condiciona la tension.

### 9.1 Restricciones de diseno

1. Tensión
- Batería Li-ion: 4.2 V (cargada) a ~3.0 V (descargada).
- ESP8266: 2.5-3.6 V.
- Conclusión: se requiere regulacion.

– Un diodo en serie (≈ 0.7 V) reduce 4.2 -> 3.5 V, pero colapsa a ~2.3 V cuando la celda cae a 3.0 V, bajo el minimo del ESP8266. No es solucion de produccion. – Un LDO a 3.3 V desaprovecha la cola de la batería (cuando Vin < 3.3 V entra en dropout).
– Un buck a 3.3 V es eficiente por arriba de 3.3 V, pero no regula cuando Vin < 3.3 V.
2. Ciclo de operación Definimos un ciclo con tres estados:
- Activo (adquisicion + TX): ESP8266 activo con radio, IMU activa.
- Idle/light-sleep: CPU o perifericos pausados, radio apagado.
- Deep-sleep: solo RTC operativo; en ESP8266 el wake implica reset del MCU.
3. Recuperación post-sleep El deep-sleep reinicia el ESP8266: se debe reconstruir estado (NTP, MQTT, seq, reconfiguracion IMU) de forma idempotente.

### 9.2 Marco de calculo de autonomia

Para un ciclo de duracion T = ta + tl + td

con corrientes Ia

, Il

, Id
:

Considerando:

- T : duracion total de un ciclo.
- ta
: tiempo en estado activo (adquisicion + TX/RX).
- tl
: tiempo en light-sleep (CPU/perifericos en pausa, radio apagada).
- td
: tiempo en deep-sleep (solo RTC activo).
- Ia
: corriente media en estado activo.
- Il
: corriente media en light-sleep.
- Id
: corriente media en deep-sleep.

Iprom =

Ia

ta + Il

tl + Id

td
T

⇒ Autonomia (h) ≈ CmAh ⋅ η Iprom

- Capacidad efectiva CmAh: nominal × factor de eficiencia η ∈ [0.8, 0.9] para perdidas de regulador y temperatura.
- Supuestos iniciales (a validar): $ I_a=120 mA $ promedio durante TX y lectura, Il = 0.9 mA , Id = 20 μA. IMU activa suma ~4 mA en Ia y ~10 μA en bajo consumo.

Ejemplo de orden de magnitud (no compromiso de diseno): Si ta = 2 s, tl = 8 s, td = 50 s por ciclo de 60 s, entonces Iprom ≈

(124)(2)+(0.9)(8)+(0.02)(50)
60 | ≈ 4.5 mA. Con una celda 2000 mAh y

η = 0.85 →≈ 377ℎ teoricas. Pequenos cambios en ta o Ia derrumban la cifra, de ahi la necesidad de medir.

### 10 Diseño HW — Placa v0.0.2 (SMD)

### 10.1 Placa de Desarrollo v0.0.2 (SMD)

### 10.1.1 Placa de Desarrollo v0.0.2 (SMD)

Descripción general Revision orientada a compactar el diseno y mejorar DFM/EMI manteniendo la funcionalidad de la v0.0.1. Se migra a SMD con plano de masa continuo, keep-out para antena y headers accesibles para IMU y UART. La alimentacion continua con LDO AMS1117-3.3 + diodo serie como solucion de banco, en espera de migrar a buck-boost 3.3 V en la siguiente iteracion.

- Formato: 51.56 × 38.61 mm, 4 orificios de montaje.
- Topologia: batería Li-ion → diodo serie → LDO AMS1117-3.3 → rail 3V3 para ESP-12 y conector MPU6050.
- Keep-out RF: zona superior libre de cobre y componentes sobre la antena integrada (serigrafia “KEEP-OUT ZONE”).
- Control: pulsador RESET, pad para BOOT/FLASH y EN con pull-up.
- Interfaz: header UART de programacion y header I2C/INT para la IMU.
- Senalizacion: tres LEDs SMD para estado (Wi-Fi/datos/aux).

Vease Cobertura y propagacion (plan de medicion) para los ensayos de antena y cobertura asociados a esta revision.


Bloques y esquemas

1. Alimentación: AMS1117-3.3 con C3 bulk y ceramicos de desacople cercanos; diodo 1N4007 serie desde batería como atajo temporal para ajustar Vbat.
2. RF/MCU: ESP-12 (ESP8266MOD) con antena integrada Rainsun y keep-out superior; GPIO mapeados a UART, I2C y LEDs.
3. Control de arranque: EN con pull-up, RESET por pulsador; pads para GPIO0 (modo flash).
4. IMU: conector para MPU6050 con SCL/SDA y INT.


Ruteo con plano GND en top y via-stitching perimetral; colocacion SMD en bancos compactos para LEDs y RC de control; headers verticales para IMU/UART; keep-out RF claramente marcado.

Pinout efectivo (para trazabilidad de firmware)

Funcion | Pin ESP8266 | Conector | Nota
UART TX | GPIO1/TXD0 | J3-TX | Programacion/registro
UART RX | GPIO3/RXD0 | J3-RX | Programacion/registro
I2C SCL | GPIO5 | J2-SCL | Pull-ups en modulo IMU
I2C SDA | GPIO4 | J2-SDA | —
IMU INT | GPIO14 | J2-INT | Interrupciones de movimiento
LED Wi-Fi | GPIO12 | D? + R? | Estado radio
LED Datos | GPIO13 | D? + R? | Publicacion/actividad
LED Aux | GPIO16 | D? + R? | Uso general
EN (chip-enable) | EN | — | Pull-up
RESET | RST | SW1 | Pulsador a GND
BOOT/FLASH | GPIO0 | Pad/JP | Forzar modo programacion

### 11 Prototipo físico

### 11.0.1 Descripción general

Modulo de adquisicion autonomo montado en placa perforada (protoboard FR-4) con batería Li-ion plana como sustrato mecanico. El conjunto integra ESP8266 (ESP-01), IMU MPU6050 (GY-521), cargador/proteccion de batería Li-ion, y modulo DC-DC para acondicionamiento de tension. Se incorporan interruptor, pulsador de reset/usuario, LED de estado y test-pads para depuracion.

### 11.0.2 Componentes principales

Conjunto | Funcion | Observaciones de montaje
ESP8266 ESP-01 con soporte impreso | MCU + Wi-Fi | Soporte 3D para alivio de tension del conector;
| | disipador pasivo pequeno.
MPU6050 (GY-521) | Acelerometro/giroscopioMontado en el plano superior; acceso a
| | SDA/SCL en header.
Cargador/protector Li-ion | Carga 5 V y
| proteccion de celda | Entrada micro-USB; ubicado en cara inferior
| | junto a la batería.
DC-DC (ajustable) | Regulacion a 3.3 V | Modulo comercial; ajuste en 3.30 +- 0.03 V.
Batería Li-ion tipo “flat” | Fuente | Fijacion con cinta Kapton; cableado con alivio
| | termico.
Diodo serie (temporal) | Caida de ~0.7 V | Solucion transitoria para compatibilidad de
| | tension.
Interfaz | Interruptor,
| pulsador, LED | Acceso lateral; utiles para pruebas de banco.

### 11.0.3 Interconexión electrica (alto nivel)

- Batería -> cargador/proteccion -> DC-DC 3.3 V -> rail logica (ESP8266 + IMU).
- GPIO/UART: SDA/SCL expuestos; UART accesible para programacion.

### 11.0.4 Funcionalidad validada en banco

- Encendido estable a 3.3 V regulados.
- Lectura de IMU.
- Carga de batería por micro-USB y operacion en modo “cableado”.

### 11.0.5 Limitaciones actuales

- Regulación: uso de diodo de caida como solucion temporal; riesgo de subalimentacion cuando Vbat < 3.3 V + Vdrop.
- Mecanica: apilado con adhesivo caliente; se requiere placa SMD y separadores para rigidez y repetibilidad.
- Medición de consumo: sin shunt/INA dedicado; no hay perfil de corrientes por estado.
- Protección: sin TVS ni fusible rearmable en entrada; headers sin retencion.

### 11.0.6 Proximos pasos de mejora

1. Migrar a PCB v0.0.2 SMD con plano GND continuo bajo IMU y “via-stitching”.

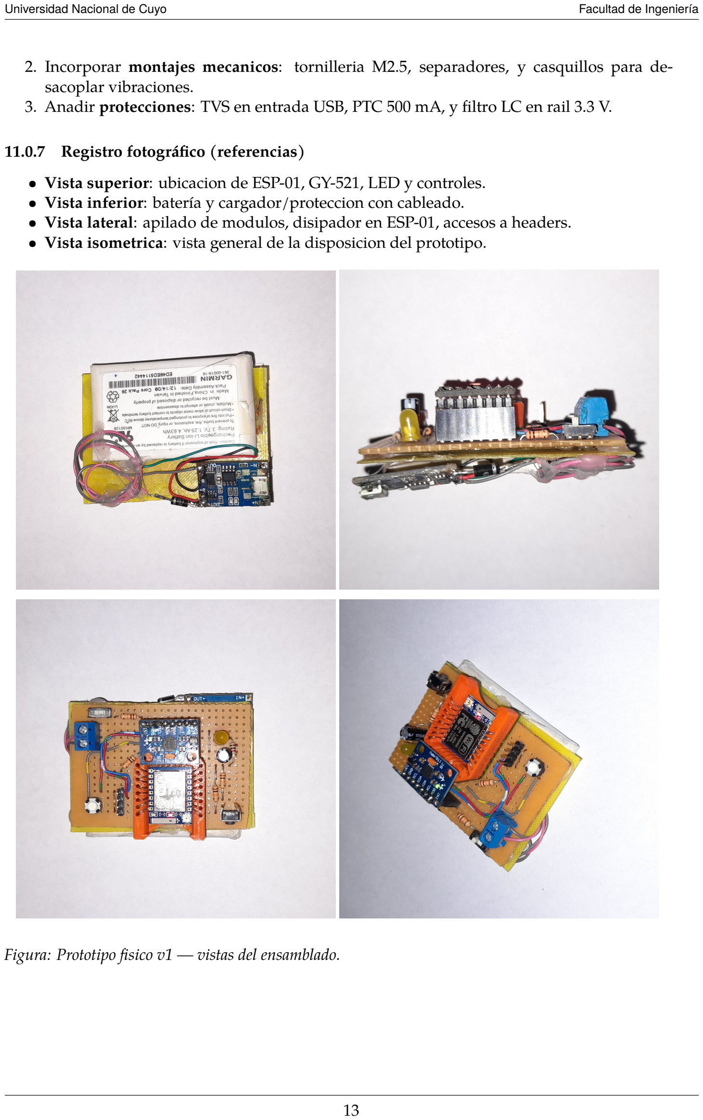
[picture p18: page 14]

2. Incorporar montajes mecanicos: tornilleria M2.5, separadores, y casquillos para desacoplar vibraciones.
3. Anadir protecciones: TVS en entrada USB, PTC 500 mA, y filtro LC en rail 3.3 V.

### 11.0.7 Registro fotográfico (referencias)

- Vista superior: ubicacion de ESP-01, GY-521, LED y controles.
- Vista inferior: batería y cargador/proteccion con cableado.
- Vista lateral: apilado de modulos, disipador en ESP-01, accesos a headers.
- Vista isometrica: vista general de la disposicion del prototipo.

Figura: Prototipo fisico v1 — vistas del ensamblado.

### 12 Firmware (ESP8266/ESP32)

### 12.1 Objetivo y alcance

El firmware temporiza la adquisicion con un timer periodico (200 Hz). La ISR solo encola un disparo; una tarea lee la IMU (MPU6050) por I2C en burst, aplica calibracion de offset (guardada en NVS/EEPROM) y llena un buffer de tamano fijo. Al completar el bloque, otra tarea empaqueta y publica por MQTT con QoS1; si no hay red, encola en SPIFFS para reenvio. El payload incluye ts_ms (marca de tiempo UTC en milisegundos del inicio del bloque), fs_hz, seq, n y las series crudas por canal. En ESP8266, el deep-sleep despierta por GPIO16→RST, por lo que el arranque rehidrata NTP/MQTT/IMU y seq. Adquirir datos crudos de la MPU6050 y publicarlos sin procesamiento local, delegando el posprocesado en el backend. Veanse §§14 y 15 para la integracion con deep-sleep y la justificacion de F_s.

### 12.2 Temporización y ejecución

- Temporizador periodico: genera una interrupcion cada T = 1/FSHZ para disparar la toma de muestra.
- ISR minima: coloca un “trigger” en una cola.
- Tarea de adquisición: toma el “trigger”, realiza lectura burst I2C del MPU6050, aplica calibracion y escribe la muestra cruda en un ring buffer.
- Tarea de publicacion: empaqueta bloques de N muestras y publica por MQTT (o los deja en cola local si no hay red).
- Deep-sleep (ESP8266): GPIO16 $\rightarrow$ RST produce reset; en setup() se rehidrata NTP/MQTT/IMU y se continua la secuencia seq.

### 12.3 Calibración del MPU6050 (compensación de offset)

Intención: remover sesgo de fabrica y de montaje.

1) Nodo inmovil 10-20 s.
2) Capturar N muestras.
3) Calcular medias por canal. Acel: bias_a[i]=mean(acc[i]) ajustando Z a ± 1 g; Giro: bias_g[i]=mean(gyro[i]). Guardar en NVS/EEPROM junto con temp_ref. En operacion: x_corr = x_raw − bias − k_temp*(temp − temp_ref) si se calibra termicamente. Criterio de aceptacion interno: var(acc) < 0.01 g.

### 12.4 MQTT: tópicos y payload

- Tópicos:

– sismo/<site>/<nodeId>/data (QoS1, no retenido)
– sismo/<site>/<nodeId>/status (QoS1, retenido, LWT=offline) – sismo/<site>/<nodeId>/cfg (QoS1, retenido)

ts_ms significa “timestamp en milisegundos desde epoca UNIX (UTC)”. En modo por bloques, ts_ms es el instante de la primera muestra del bloque. La separacion temporal entre muestras del bloque se infiere con fs_hz o con dt_us opcional.

Payload propuesto (bloques crudos, sin filtrado):

{
"ts_ms": 1730158805123,

"fs_hz": 200,
"seq": 15231,
"n": 100,
"ax": [ ... 100 valores ... ], "ay": [ ... 100 valores ... ], "az": [ ... 100 valores ... ], "gx": [ ... 100 valores ... ], "gy": [ ... 100 valores ... ], "gz": [ ... 100 valores ... ], "temp_c": 27.5,
"vbat": 3.92
}

Justificación de parametros:

- ts_ms y fs_hz permiten reconstruir el tiempo exacto de cada muestra en servidor.
- seq asegura idempotencia extremo a extremo junto al UNIQUE(nodo_id, measured_at, seq) en DB.
- n define tamano del bloque para decodificacion eficiente.
- temp_c habilita compensaciones termicas en analisis.
- vbat permite correlacionar eventos con caida de tension.

### 13 Cobertura y propagación (plan de medicion)

La performance depende del entorno (hormigon, acero, geometria de planta). Con la v0.0.2 se respeta el keep-out RF de antena; aun asi, se realizara un site-survey en dos pasos: (1) recorrido estatico con un nodo portatil registrando RSSI y tasa efectiva de publicacion; (2) prueba dinamica en horarios pico midiendo perdida y latencia “wake→publish” con deepsleep. Criterios de accion: si RSSI < -75 dBm sostenido o perdida > 1 % en 30 min, se define AP auxiliar o antena externa (ESP-07) y se reubican nodos. El backend usara status retenido + LWT para mapear disponibilidad por ubicacion.

### 14 Deep-sleep y “reset virtual” (ESP8266)

Es un hecho tecnico que en el microcontrolador ESP8266 el modo deep-sleep no “despierta” el programa donde quedo: reinicia el chip. El despertar se logra con la union GPIO16 (D0) → RST; al vencer el temporizador interno, GPIO16 impulsa RST y se produce un reset por hardware equivalente a un “software/virtual reset”.

Implicancias de diseno

- Re-hidratacion de estado: al iniciar, el firmware debe reconstruir NTP, MQTT, configuracion de IMU y contadores (seq) de forma idempotente.
- Persistencia minima: guardar en RTC/flash ligera: seq, ultimo ts, flags de “shutdown
limpio”.
- Tiempos de servicio: medir y reportar t_wake $\rightarrow$\rightarrow$\righta$\rightarrow$\rightarrow$row$ Wi-Fi $\rightarrow$\rightarrow$\rightarrow$\rightarrow$ publish (p95); los
costos de asociacion Wi-Fi dominan el consumo si el ciclo de sueno es corto.
- Senalizacion y LWT: publicar status=boot/deepsleep_wakeup y configurar LWT para
recuperacion en backend.

Requisito eléctrico

- Trazar GPIO16 → RST con retorno GND corto y mantener pull-ups de RST/EN segun datasheet. No conectar GPIO16 a otros perifericos.

Prueba minima

1. Programar deepSleep(us), verificar pulso en RST desde GPIO16.
2. Comprobar re-inicio completo y publicacion de status en <= 3 s tras el reset.

En ESP8266, deepSleep(us) despierta por pulso de GPIO16 a RST, equivalendo a un reset por hardware. El arranque debe sincronizar NTP, reconectar MQTT publicando status=deepsleep_wakeup, restaurar seq, reconfigurar la IMU y enviar/barrer cualquier bloque encolado en SPIFFS.

### 15 Frecuencias de muestreo — justificación

Las vibraciones sismicas de interes estan en 0.5-30 Hz. Se adopta Fs = 200 Hz por sobre-muestreo >= 5x respecto de fmax y margen para transitorios y jitter; Nyquist queda en 100 Hz. Publicar por bloques a 200 Hz mantiene resolucion y un volumen de datos razonable; cualquier filtrado/decimado se realiza en servidor.

### 15.1 Justificación de frecuencias de muestreo

Las vibraciones sismicas estructurales de interes se concentran tipicamente entre 0.5 y 30 Hz. Para capturarlas sin distorsion y con margen de analisis, se adopta un factor de sobre-muestreo >= 5x respecto de la frecuencia maxima de interes:

Fs ≥ k ⋅ fmax con k ∈ [5, 10]

Con fmax = 30 Hz y k = 5 resulta Fs ≥ 150 Hz. Se fija Fs = 200 Hz por las siguientes razones:

1. deja banda util hasta 100 Hz (Nyquist) para cubrir picos transitorios o impactos por encima de 30 Hz;
2. mejora la estimacion de espectros y tiempos caracteristicos al contar con mas muestras por ciclo;
3. aporta robustez a jitter del temporizador y a pequenas derivas del bus I2C sin perder cobertura;
4. mantiene un coste de red razonable cuando se publica en bloques (sin filtrado en el nodo), dejando todo el posprocesamiento al servidor.

Parametros operativos asociados:

- FS_HZ = 200 define la frecuencia de adquisicion en el microcontrolador.
- PUB_BLOCK_SAMPLES controla el tamano del bloque publicado y, por ende, la latencia y el ancho de banda efectivo. Por ejemplo, PUB_BLOCK_SAMPLES = 100 implica bloques de 0.5 s a 200 Hz.

Este esquema garantiza resolucion suficiente para la banda 0.5-30 Hz con margen de analisis y sin carga de computo en el firmware, que solo mide y publica datos crudos.

### 16 Base de datos (MySQL) — resumen operativo

El esquema guarda mediciones crudas por nodo con trazabilidad minima y consultas rapidas por ventana temporal. La tabla mediciones usa DATETIME(3) en UTC, payload_json y columnas generadas (seq, fs_hz, vbat). La restriccion UNIQUE (nodo_id, measured_at, seq) permite ingesta idempotente. Se recomienda particionado mensual y roles minimos de acceso (ingesta, dashboard, administracion).

### 16.1 Objetivo

Almacenar mediciones por nodo con trazabilidad minima y consultas rapidas por ventana temporal, usando UTC con milisegundos. El diagrama proporcionado es la referencia del modelo: cliente posee sistemas; cada sistema agrupa nodos; cada nodo genera mediciones; los usuarios acceden por rol mediante una tabla de relacion.

### 16.2 Modelo lógico

Tablas de administracion: cliente, sistema, usuario, usuario_sistema. Tablas operativas: nodo (metadatos, keep-alive, habilitacion) y mediciones (serie temporal). Identificadores BIG-INT autoincrementales y campos created_at, updated_at, deleted_at en DATETIME(3) para auditoria y soft-delete. Codigos legibles (*_code) unicos para direccionamiento desde flujos y UI.

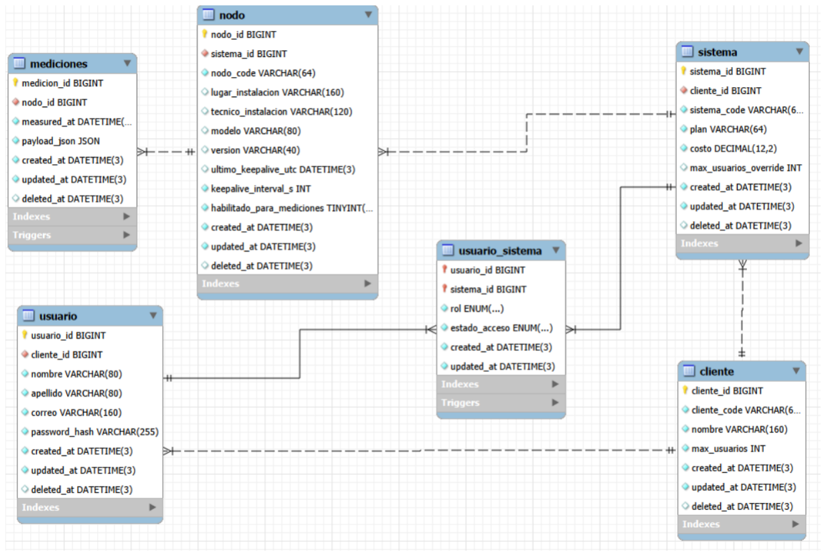
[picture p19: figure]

### 16.3 Tabla central

mediciones guarda el instante de captura y el payload crudo en JSON, mas columnas generadas para filtrar por secuencia, frecuencia de muestreo y tension de batería. Se impone unicidad por (nodo_id, measured_at, seq) para lograr ingesta idempotente y evitar duplicados ante reintentos.

CREATE TABLE mediciones (
medicion_id BIGINT UNSIGNED PRIMARY KEY AUTO_INCREMENT,
nodo_id BIGINT UNSIGNED NOT NULL,
measured_at DATETIME(3) NOT NULL, | -- UTC
payload_json JSON NOT NULL, | -- ax, ay, az, fs_hz, seq, vbat...
seq | INT | GENERATED ALWAYS AS (CAST(JSON_UNQUOTE(JSON_EXTRACT(payload_json,'$.seq')) | AS UNSIGNED)) STORED,
fs_hz SMALLINT GENERATED ALWAYS AS (CAST(JSON_UNQUOTE(JSON_EXTRACT(payload_json,'$.fs_hz')) AS UNSIGNED)) STORED,
vbat DECIMAL(4,2) GENERATED ALWAYS AS (CAST(JSON_UNQUOTE(JSON_EXTRACT(payload_json,'$.vbat')) AS DECIMAL(4,2))) STORED, created_at DATETIME(3) NOT NULL DEFAULT CURRENT_TIMESTAMP(3),
updated_at DATETIME(3) NOT NULL DEFAULT CURRENT_TIMESTAMP(3) ON UPDATE CURRENT_TIMESTAMP(3),
UNIQUE KEY uk_med (nodo_id, measured_at, seq),
KEY k_nodo_ts (nodo_id, measured_at),
CONSTRAINT fk_med_nodo FOREIGN KEY (nodo_id) REFERENCES nodo(nodo_id)
) ENGINE=InnoDB;

## Ingesta (idempotente)

El flujo de Node-RED inserta usando `INSERT ... ON DUPLICATE KEY UPDATE`, con tres parametros: `nodo_id` (identidad del dispositivo), `ts_ms` (marca de tiempo en milisegundos convertida a `DATETIME(3)` UTC) y `payload_json` (mensaje validado).

```sql
INSERT INTO mediciones (nodo_id, measured_at, payload_json)
VALUES (?nodo_id, FROM_UNIXTIME(?ts_ms/1000), ?payload_json)
ON DUPLICATE KEY UPDATE payload_json = VALUES(payload_json), updated_at = CURRENT_TIMESTAMP(3);

### 16.4 Consulta tipica

Para graficar una ventana temporal por nodo se filtra por nodo_id y rango de measured_at, aprovechando el indice k_nodo_ts.

SELECT measured_at, payload_json
FROM mediciones
WHERE nodo_id = ? AND measured_at BETWEEN ?ini AND ?fin ORDER BY measured_at;

### 16.5 Particionado y operacion

Se recomienda particionar mediciones por rango mensual de measured_at para mantener indices compactos y facilitar la retencion de crudos (p. ej., 180 dias). El acceso desde Node-RED debe ir por TLS y con privilegios minimos; la UI solo requiere SELECT.

Roles propuestos:

- ingestor (INSERT/SELECT en mediciones y SELECT en nodo)
- dashboard (SELECT)
- admin_db (DDL/particiones).

### 17 Backend y dashboard

Node-RED procesa la ingesta (validacion del esquema, construccion de SQL) y publica KPIs en un dashboard (disponibilidad por nodo, volumen por dia y graficos de aceleracion). La conexión a MySQL se realiza con TLS y usuarios de privilegios minimos.

### 18 Riesgos y mitigaciones

Energia (dropout y autonomia), RF/cobertura (areas sombra), DB/retencion (tamano y tiempos de consulta), robustez mecanica. Mitigaciones: buck-boost 3.3 V, site-survey y/o AP auxiliar, particionado temporal, pads de test y protecciones ESD/PTC.

### 18.1 Riesgos y mitigaciones

Riesgo | Efecto | Mitigacion
Picos de TX > 200 mA | Reset
| brown-out | Capacitores cerca del SoC y del regulador, ruta de
| | GND corta
Dropout en LDO | Apagado
| prematuro | Buck-boost o cutoff a Vbat que garantice 3.3 V
| | estable
Overhead de reconexion Wi-Fi | Aumenta ta | Persistir credenciales, aumentar DTIM, batch de
| | publicaciones
Deriva de consumo IMU | Baja
| autonomia | Cambiar a modo low-power accel entre eventos

### 19 Plan de proxima iteracion

Energia (mediciones por estado y decision de regulador), cobertura (site-survey y acciones), firmware (cola local y secuencia persistente), DB (particiones y vistas), instalacion piloto acotada.

### 19.1 Cronograma y plan de la siguiente iteracion

Objetivos verificables

- Crear un prototipo funcional de la placa de desarrollo v0.0.2 (SMD)
- Implementar cola local en firmware con reenvio y prueba de caida 10 min.
- Integrar TLS mutual en Mosquitto y validar ACLs por topico.
- Completar dashboard con espectro en ventana movil y alarmas.
- Ensayo de calibracion de 2 nodos y reporte de error con incertidumbre.

### 20 Anexos

Esquematicos/layout, tablas de pinout, DDL, fragmentos de firmware, y registro fotografico.

### 20.1 Solicitudes al comite/directores (bloqueadores)

### 20.2 Bibliografía y referencias

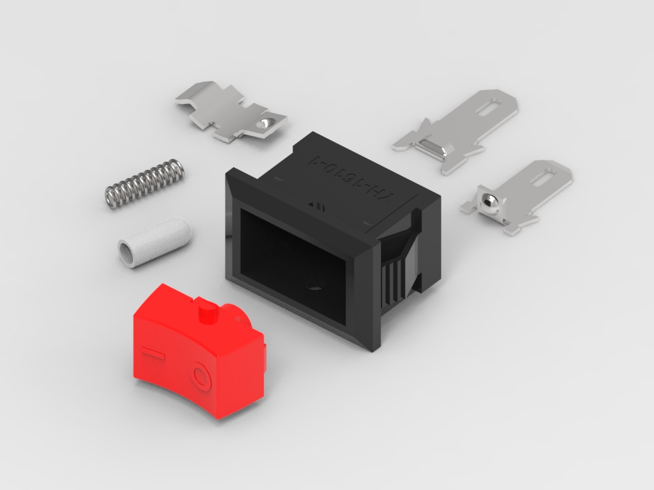
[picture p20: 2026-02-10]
DESIGN/rocker-switch-2-terminals-1.snapshot.2/EXPLODED-2.jpg

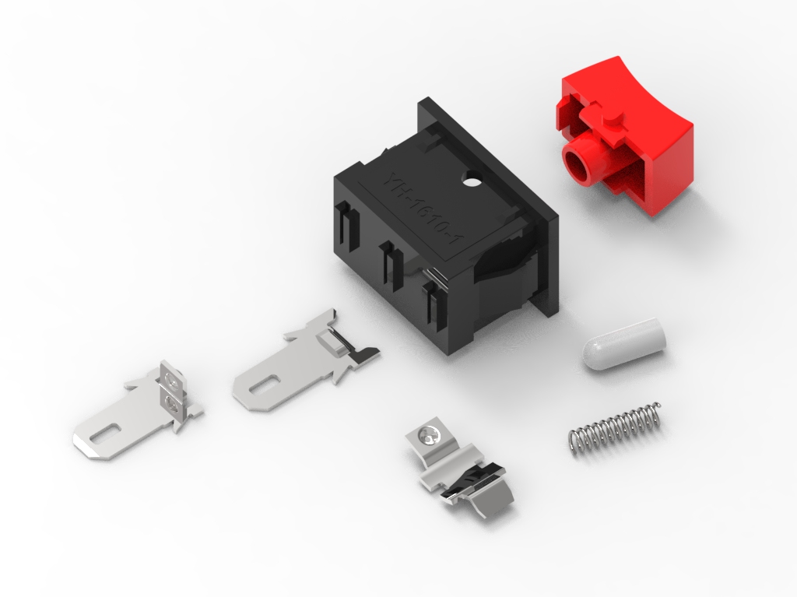
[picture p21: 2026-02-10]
DESIGN/rocker-switch-2-terminals-1.snapshot.2/EXPLODED-1.jpg

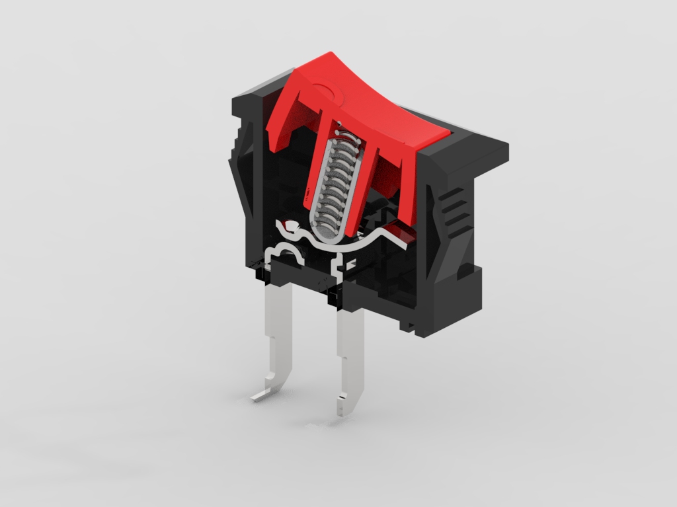
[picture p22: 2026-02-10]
DESIGN/rocker-switch-2-terminals-1.snapshot.2/SECTION VIEW.jpg

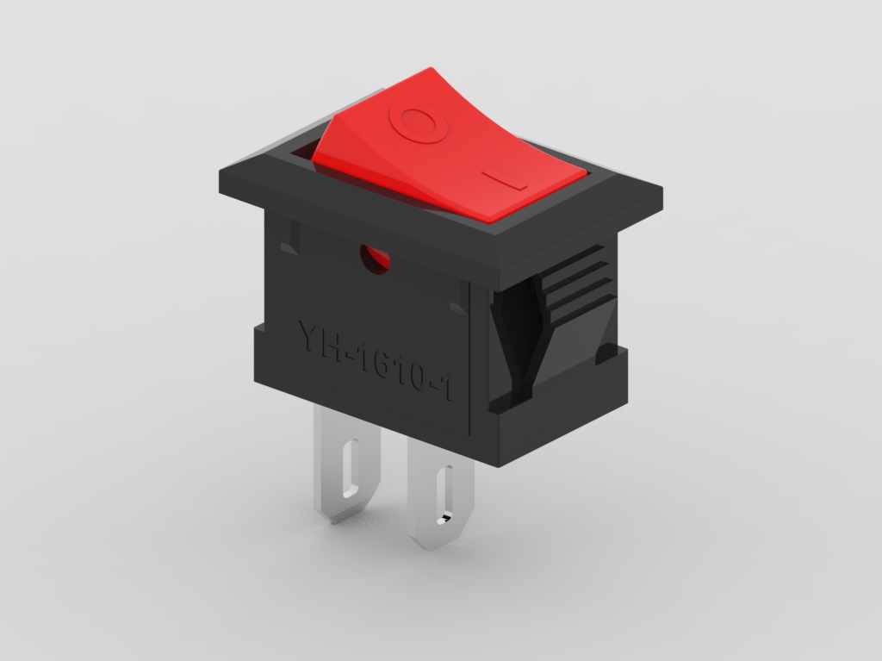
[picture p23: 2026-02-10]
DESIGN/rocker-switch-2-terminals-1.snapshot.2/ROCKER SWITCH.jpg

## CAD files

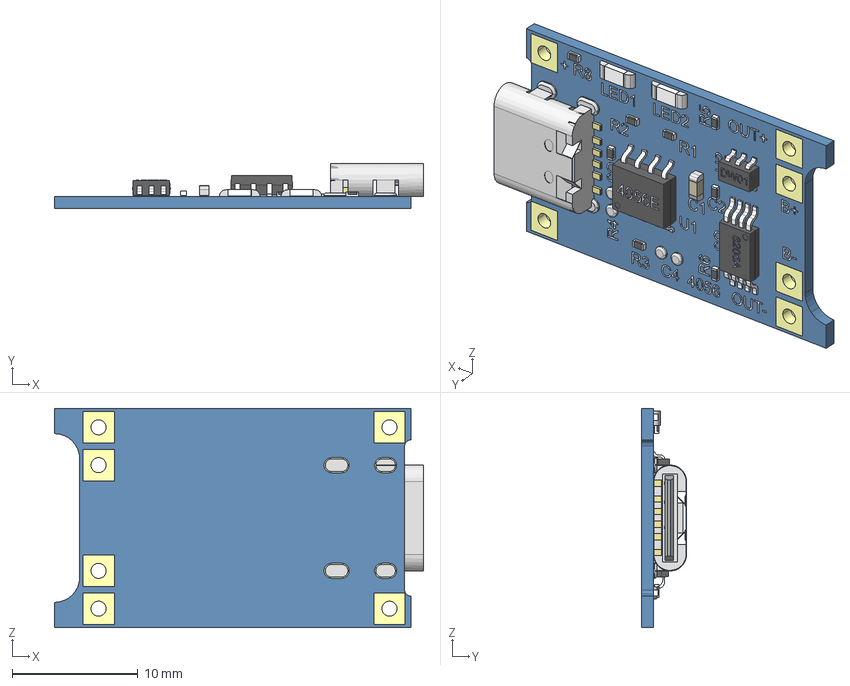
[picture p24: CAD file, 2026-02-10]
DESIGN/hw-373-1.snapshot.2/HW-373.stp
29.3 x 3.59 x 17.4 mm
pcb Geometry
txt
cu
sold
8205A Geometry
PIN
R Geometry x 6
PIN2 x 6
C Geometry x 2
pin3 x 2
4056E Geometry
Pin4
DW01 Geometry
PIN5
C2 Geometry
pin6
frm
pin7
LED x 2

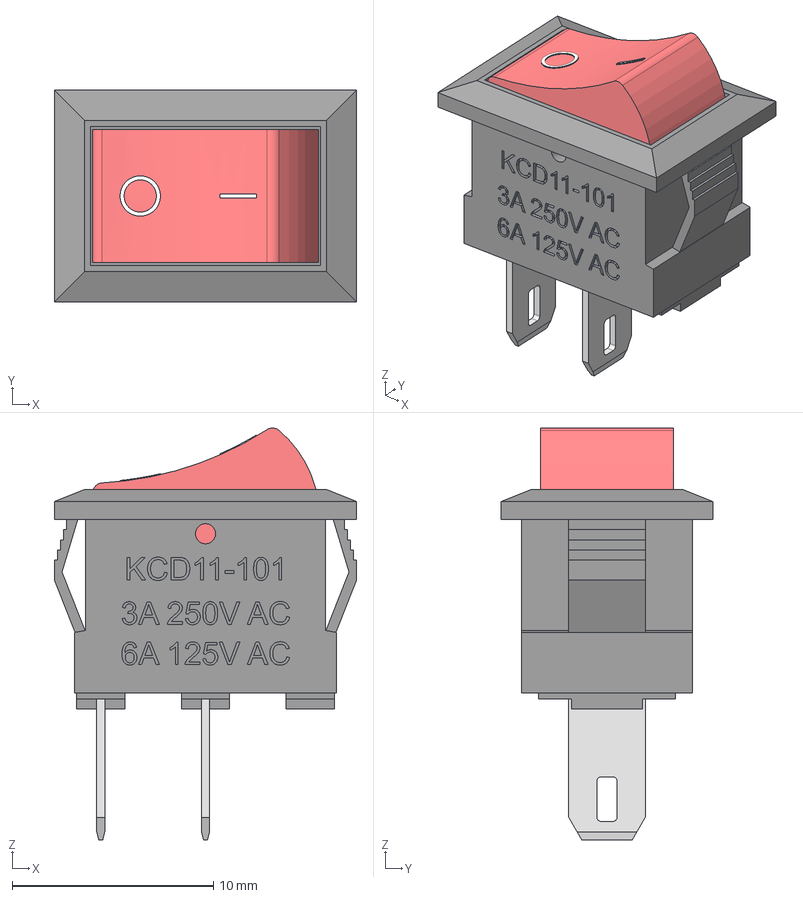
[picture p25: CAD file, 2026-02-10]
DESIGN/mini-on-off-rocker-switch-2-pins-1.snapshot.4/small_MA_switch_b.step
15.0 x 10.5 x 20.4 mm
pin001 x 2
Corps001
bouton001

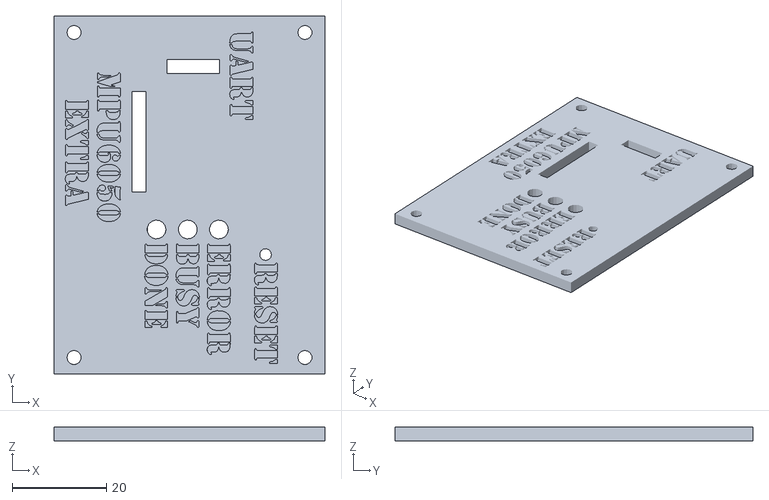
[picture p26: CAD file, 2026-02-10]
DESIGN/tapaSuperior.stl
57.5 x 76.0 x 3.00

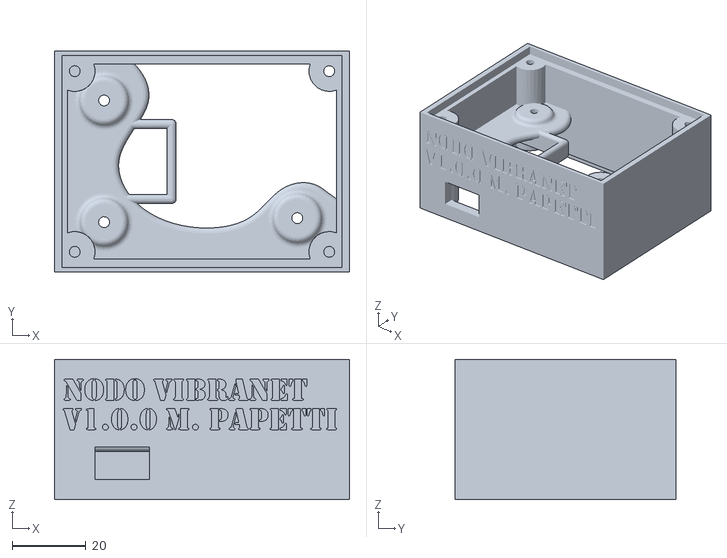
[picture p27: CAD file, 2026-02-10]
DESIGN/chasis.stl
80.0 x 60.0 x 38.0

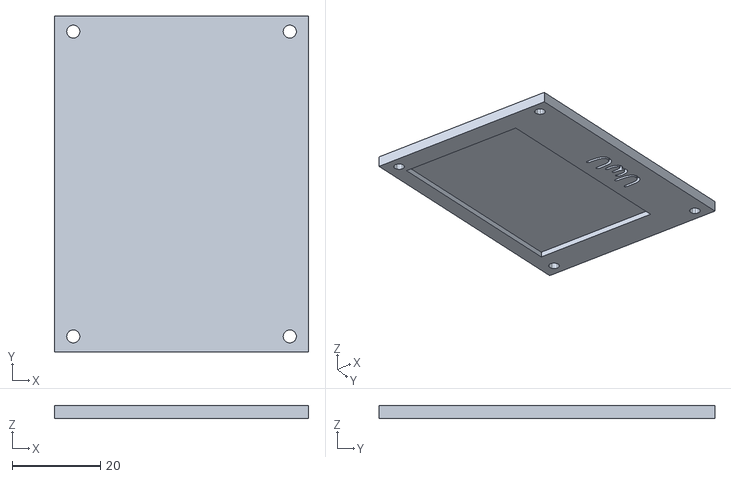
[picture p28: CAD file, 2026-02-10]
DESIGN/tapaBateria.stl
57.5 x 76.0 x 3.00

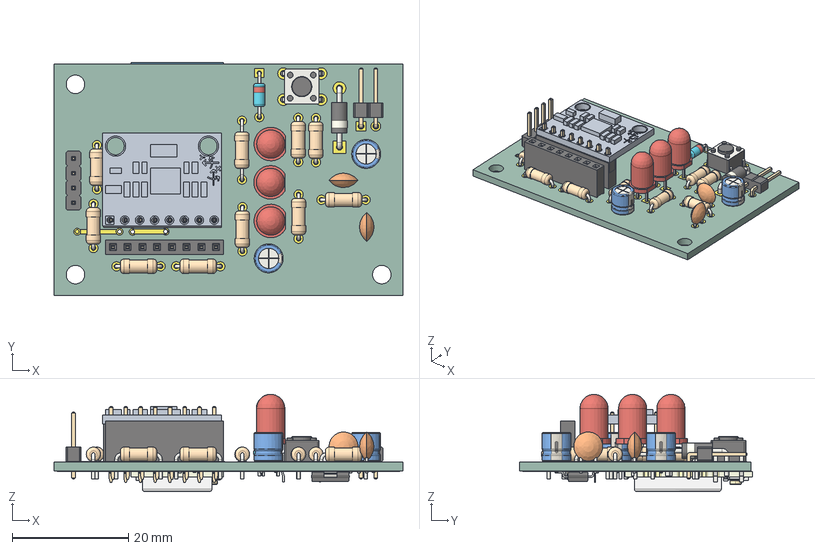
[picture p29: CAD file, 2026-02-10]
DESIGN/NodoVibraciones.step
60.1 x 40.2 x 16.8 mm
R_Axial_DIN0207_L63mm_D25mm_P762mm_Horizontal x 10
R_Axial_DIN0207_L63mm_D25mm_P1016mm_Horizontal
C_Disc_D50mm_W25mm_P250mm x 2
PinHeader_1x02_P254mm_Horizontal
LED_D5.0mm x 3
CP_Radial_D50mm_P250mm x 3
PinSocket_1x08_P254mm_Vertical x 2
SW_PUSH_6mm_h4.3mm
D_DO-41_SOD81_P10.16mm_Horizontal
MPU 6050 v3
PinHeader_1x08_P254mm_Vertical
PinHeader_1x04_P254mm_Vertical
D_DO-35_SOD27_P7.62mm_Horizontal
ESP07
SOT_223
NodoVibraciones_track_1
NodoVibraciones_track_2
NodoVibraciones_track_3
NodoVibraciones_track_4
NodoVibraciones_track_5
NodoVibraciones_track_6
NodoVibraciones_track_7
NodoVibraciones_track_8
NodoVibraciones_track_9
NodoVibraciones_track_10
NodoVibraciones_track_11
NodoVibraciones_track_12
NodoVibraciones_track_13
NodoVibraciones_track_14
NodoVibraciones_track_15
NodoVibraciones_track_16
NodoVibraciones_track_17
NodoVibraciones_track_18
NodoVibraciones_track_19
NodoVibraciones_track_20
NodoVibraciones_track_21
NodoVibraciones_track_22
NodoVibraciones_track_23
NodoVibraciones_track_24
NodoVibraciones_track_25
NodoVibraciones_track_26
NodoVibraciones_track_27
NodoVibraciones_track_28
NodoVibraciones_track_29
NodoVibraciones_track_30
NodoVibraciones_track_31
NodoVibraciones_track_32
NodoVibraciones_track_33
NodoVibraciones_track_34
NodoVibraciones_track_35
NodoVibraciones_track_36
NodoVibraciones_track_37
NodoVibraciones_track_38
NodoVibraciones_track_39
NodoVibraciones_track_40
NodoVibraciones_track_41
NodoVibraciones_track_42
NodoVibraciones_track_43
NodoVibraciones_track_44
NodoVibraciones_track_45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

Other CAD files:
DESIGN/rocker-switch-2-terminals-1.snapshot.2/yh-1610-1.prt
DESIGN/rocker-switch-2-terminals-1.snapshot.2/yh-1610-2.prt
DESIGN/rocker-switch-2-terminals-1.snapshot.2/yh-1610-3.prt
DESIGN/rocker-switch-2-terminals-1.snapshot.2/yh-1610-4-punch.prt
DESIGN/rocker-switch-2-terminals-1.snapshot.2/yh-1610-4.prt
DESIGN/rocker-switch-2-terminals-1.snapshot.2/yh-1610-5-punch.prt
DESIGN/rocker-switch-2-terminals-1.snapshot.2/yh-1610-5.prt
DESIGN/rocker-switch-2-terminals-1.snapshot.2/yh-1610-6-punch.prt
DESIGN/rocker-switch-2-terminals-1.snapshot.2/yh-1610-6.prt
DESIGN/rocker-switch-2-terminals-1.snapshot.2/yh-1610-7.prt

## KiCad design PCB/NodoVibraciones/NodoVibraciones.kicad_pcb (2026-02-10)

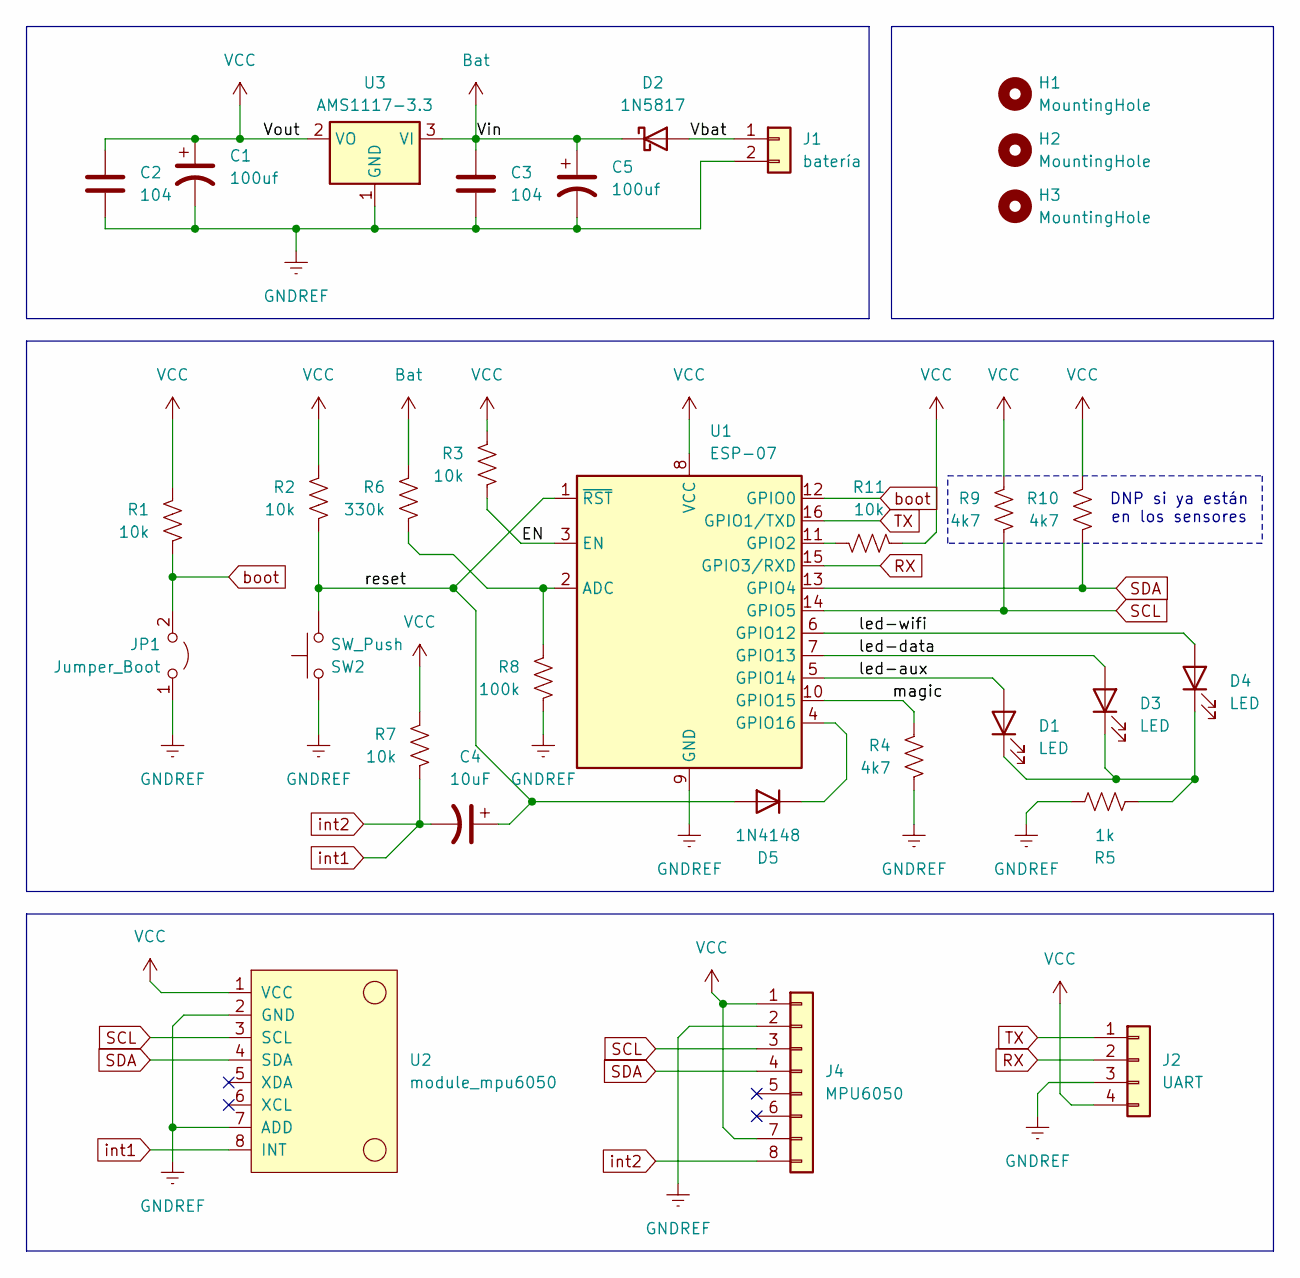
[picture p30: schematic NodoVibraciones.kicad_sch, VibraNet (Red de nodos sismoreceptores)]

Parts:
C1, C5: 100uf; CP_Radial_D5.0mm_P2.50mm
C2, C3: 104; C_Disc_D5.0mm_W2.5mm_P2.50mm
C4: 10uF; CP_Radial_D5.0mm_P2.50mm
D1, D3, D4: LED; LED_D5.0mm
D2: 1N5817; D_DO-41_SOD81_P10.16mm_Horizontal
D5: 1N4148; D_DO-35_SOD27_P7.62mm_Horizontal
H1, H2, H3: MountingHole; MountingHole_3.2mm_M3
J1: batería; PinHeader_1x02_P2.54mm_Horizontal
J2: UART; PinHeader_1x04_P2.54mm_Vertical
J4: MPU6050; PinSocket_1x08_P2.54mm_Vertical
JP1: Jumper_Boot; SolderJumper-2_P1.3mm_Open_RoundedPad1.0x1.5mm
R1, R2, R7, R11: 10k; R_Axial_DIN0207_L6.3mm_D2.5mm_P7.62mm_Horizontal
R3: 10k; R_Axial_DIN0207_L6.3mm_D2.5mm_P10.16mm_Horizontal
R4, R9, R10: 4k7; R_Axial_DIN0207_L6.3mm_D2.5mm_P7.62mm_Horizontal
R5: 1k; R_Axial_DIN0207_L6.3mm_D2.5mm_P7.62mm_Horizontal
R6: 330k; R_Axial_DIN0207_L6.3mm_D2.5mm_P7.62mm_Horizontal
R8: 100k; R_Axial_DIN0207_L6.3mm_D2.5mm_P7.62mm_Horizontal
SW2: SW_Push; SW_PUSH_6mm_H4.3mm
U1: ESP-07
U2: module_mpu6050
U3: AMS1117-3.3; SOT-223-3_TabPin2

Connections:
/EN: R3.1, U1.3 (EN)
/Vbat: D2.2 (A), J1.1
/led-aux: D1.2 (A), U1.5 (GPIO14)
/led-data: D3.2 (A), U1.7 (GPIO13)
/led-wifi: D4.2 (A), U1.6 (GPIO12)
/magic: R4.2, U1.10 (GPIO15)
/reset: C4.1, D5.2 (A), R2.1, SW2.1, U1.1 (~RST)
Bat: C3.1, C5.1, D2.1 (K), R6.2, U3.3 (VI)
GNDREF: C1.2, C2.2, C3.2, C5.2, J1.2, J2.3, J4.2, JP1.1 (A), R4.1, R5.2, R8.1, SW2.2, U1.9 (GND), U2.2 (GND), U2.7 (ADD), U3.1 (GND)
unnamed: D1.1 (K), D3.1 (K), D4.1 (K), R5.1
unnamed: D5.1 (K), U1.4 (GPIO16)
unnamed: R6.1, R8.2, U1.2 (ADC)
unnamed: R11.1, U1.11 (GPIO2)
RX: J2.2, U1.15 (GPIO3/RXD)
SCL: J4.3, R9.1, U1.14 (GPIO5), U2.3 (SCL)
SDA: J4.4, R10.1, U1.13 (GPIO4), U2.4 (SDA)
TX: J2.1, U1.16 (GPIO1/TXD)
VCC: C1.1, C2.1, J2.4, J4.1, J4.7, R1.2, R2.2, R3.2, R7.2, R9.2, R10.2, R11.2, U1.8 (VCC), U2.1 (VCC), U3.2 (VO)
boot: JP1.2 (B), R1.1, U1.12 (GPIO0)
int1: C4.2, J4.8, R7.1, U2.8 (INT)

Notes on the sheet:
DNP si ya están en los sensores

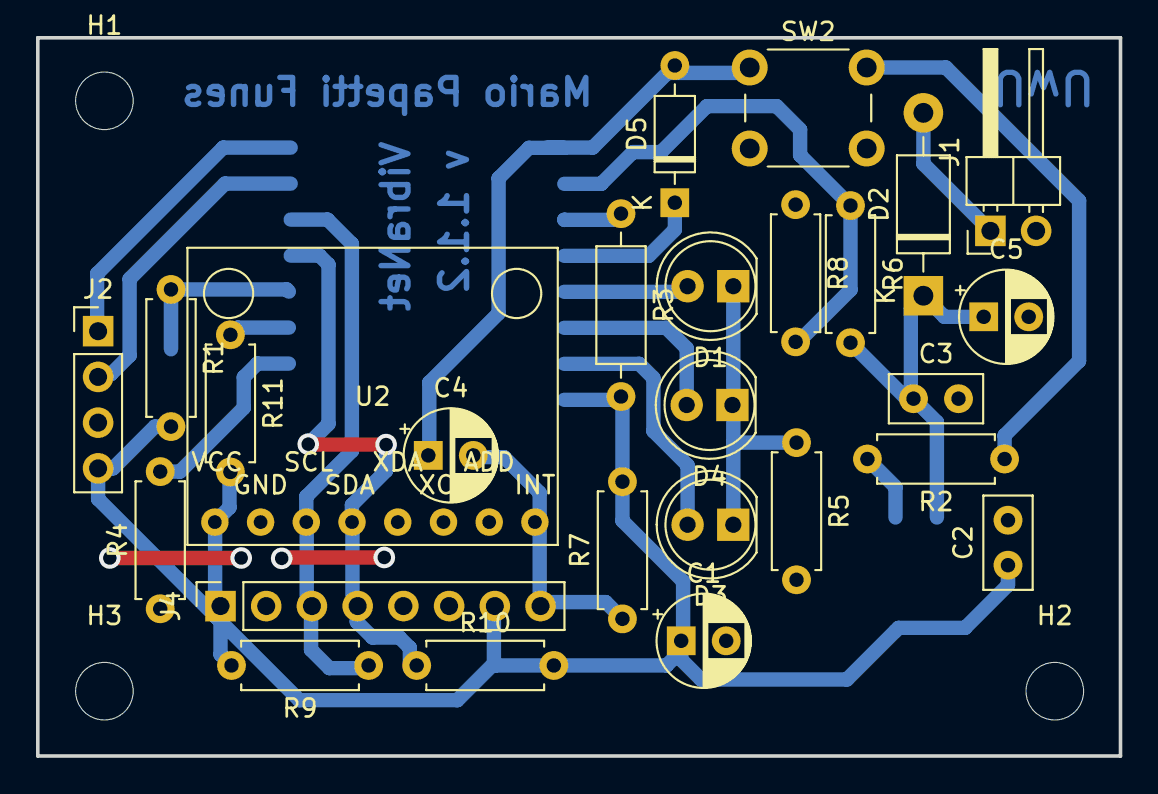
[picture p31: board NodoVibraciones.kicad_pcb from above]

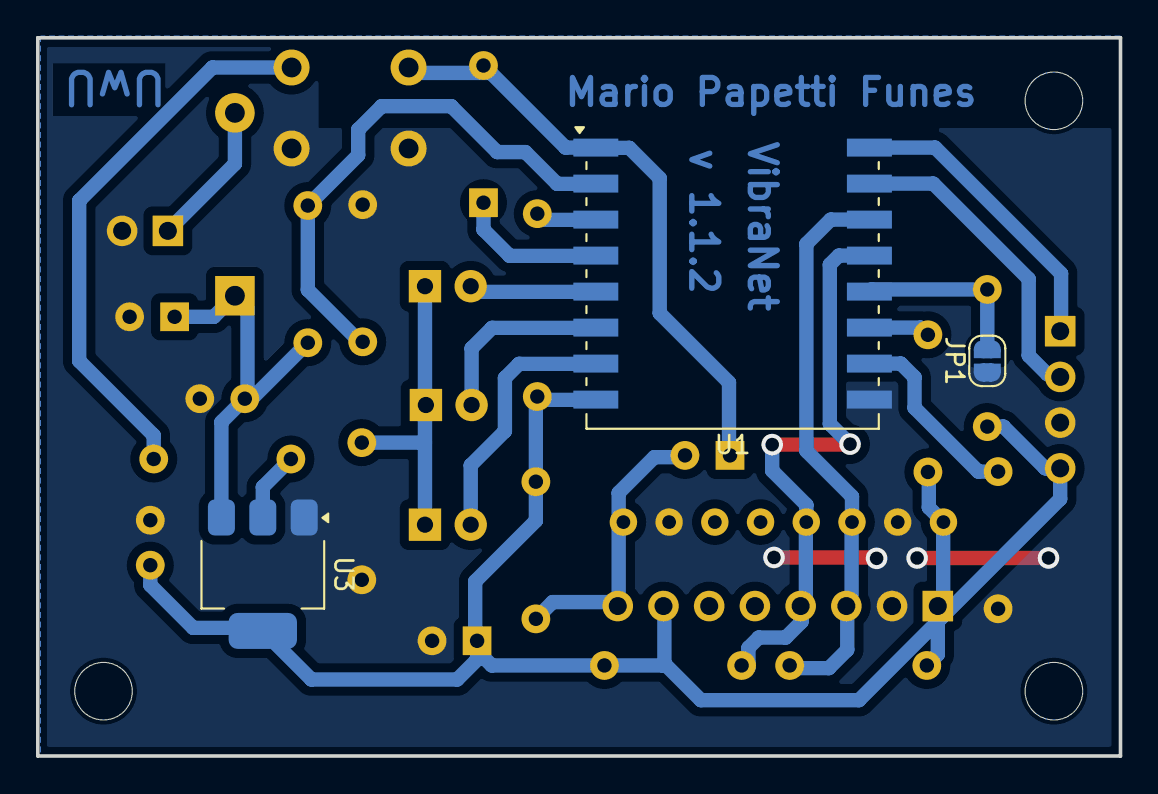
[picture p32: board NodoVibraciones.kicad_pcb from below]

Board: 2 copper layers, 60.1 x 39.9 mm, 33 parts (3 on the bottom side), 20 nets.

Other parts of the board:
H4: MountingHole; MountingHole_3.2mm_M3

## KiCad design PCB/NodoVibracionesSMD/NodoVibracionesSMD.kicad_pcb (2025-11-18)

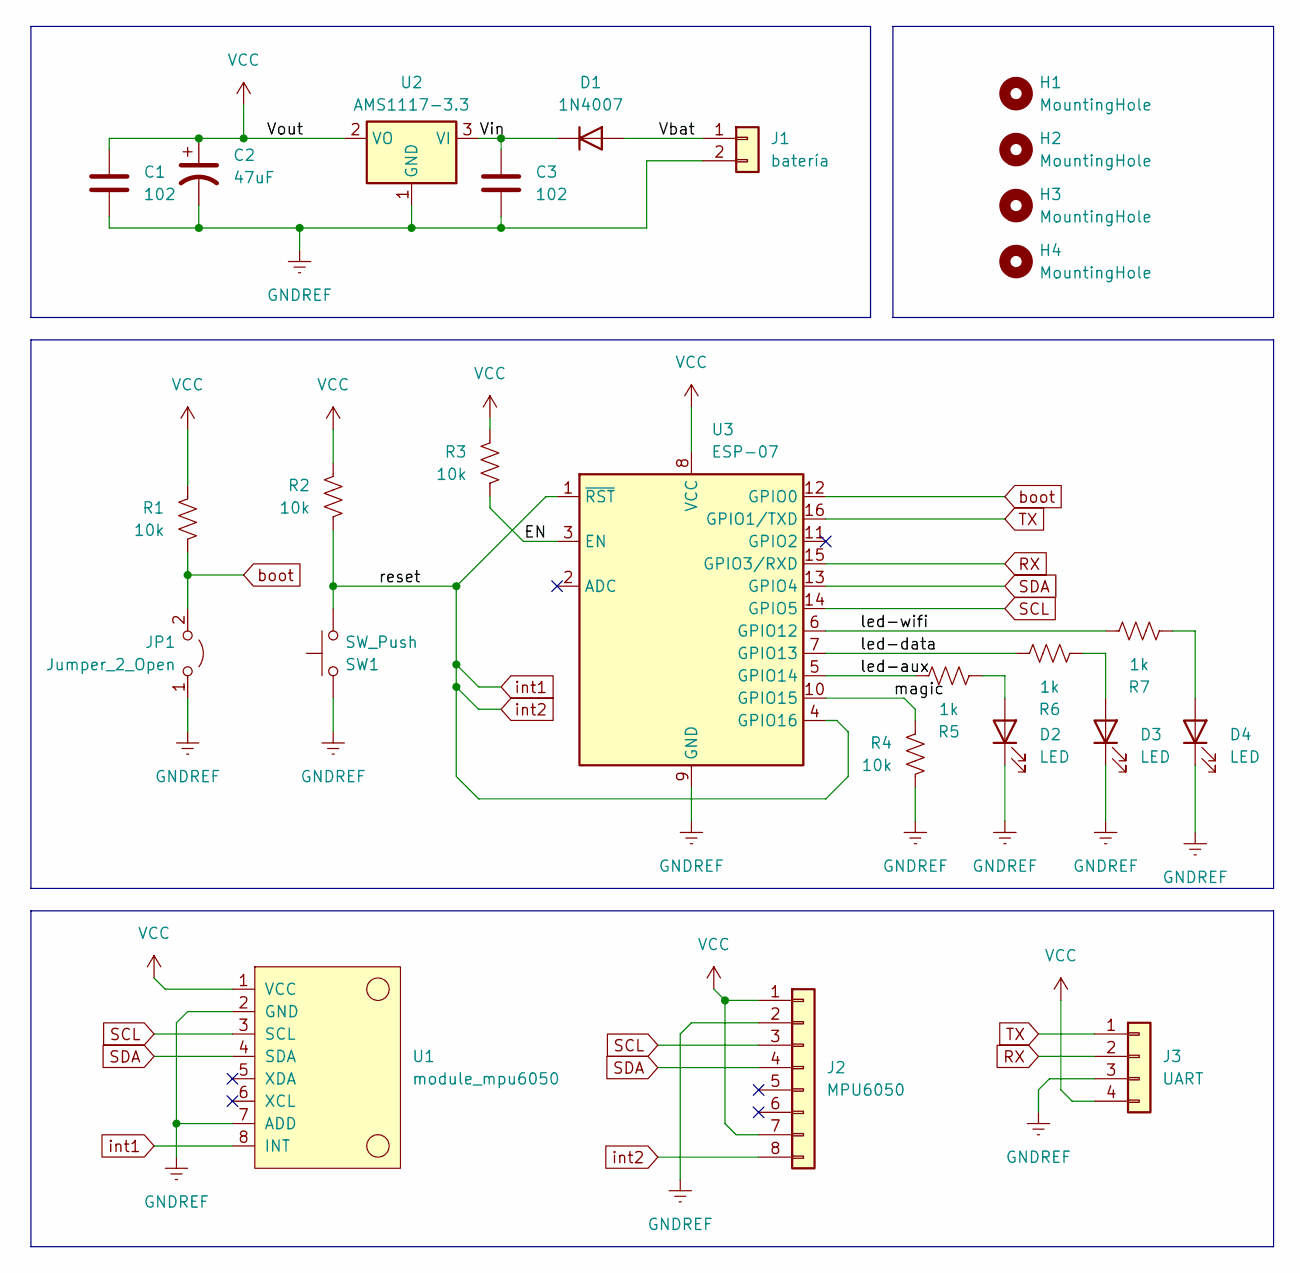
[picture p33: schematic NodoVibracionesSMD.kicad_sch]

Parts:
C1, C3: 102; C_1812_4532Metric_Pad1.57x3.40mm_HandSolder
C2: 47uF; CP_Elec_5x4.5
D1: 1N4007; D_SOD-123
D2, D3, D4: LED; LED_2010_5025Metric_Pad1.52x2.65mm_HandSolder
H1, H2, H3, H4: MountingHole; MountingHole_3.2mm_M3
J1: batería; PinHeader_1x02_P2.54mm_Horizontal
J2: MPU6050; PinSocket_1x08_P2.54mm_Vertical
J3: UART; PinHeader_1x04_P2.54mm_Vertical
JP1: Jumper_2_Open; SolderJumper-2_P1.3mm_Open_RoundedPad1.0x1.5mm
R1, R2, R3, R4: 10k; R_2010_5025Metric_Pad1.40x2.65mm_HandSolder
R5, R6, R7: 1k; R_2010_5025Metric_Pad1.40x2.65mm_HandSolder
SW1: SW_Push; SW_SPST_PTS645
U1: module_mpu6050
U2: AMS1117-3.3; SOT-223-3_TabPin2
U3: ESP-07

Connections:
/EN: R3.1, U3.3 (EN)
/Vbat: D1.2 (A), J1.1
/Vin: C3.1, D1.1 (K), U2.3 (VI)
/led-aux: R5.2, U3.5 (GPIO14)
/led-data: R6.2, U3.7 (GPIO13)
/led-wifi: R7.2, U3.6 (GPIO12)
/magic: R4.2, U3.10 (GPIO15)
GNDREF: C1.2, C2.2, C3.2, D2.1 (K), D3.1 (K), D4.1 (K), J1.2, J2.2, J3.3, JP1.1 (A), R4.1, SW1.2, U1.2 (GND), U1.7 (ADD), U2.1 (GND), U3.9 (GND)
unnamed: D2.2 (A), R5.1
unnamed: D3.2 (A), R6.1
unnamed: D4.2 (A), R7.1
RX: J3.2, U3.15 (GPIO3/RXD)
SCL: J2.3, U1.3 (SCL), U3.14 (GPIO5)
SDA: J2.4, U1.4 (SDA), U3.13 (GPIO4)
TX: J3.1, U3.16 (GPIO1/TXD)
VCC: C1.1, C2.1, J2.1, J2.7, J3.4, R1.2, R2.2, R3.2, U1.1 (VCC), U2.2 (VO), U3.8 (VCC)
boot: JP1.2 (B), R1.1, U3.12 (GPIO0)
int1: J2.8, R2.1, SW1.1, U1.8 (INT), U3.1 (~RST), U3.4 (GPIO16)

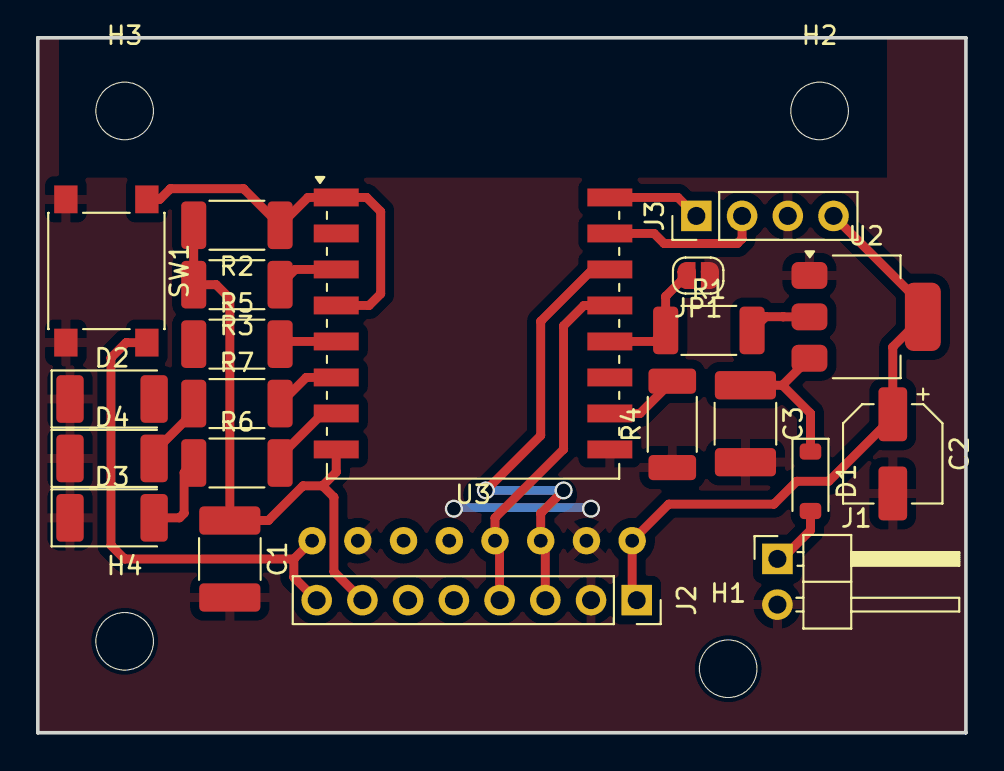
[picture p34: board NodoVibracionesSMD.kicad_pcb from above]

Board: 2 copper layers, 51.6 x 38.6 mm, 26 parts (1 on the bottom side), 18 nets.

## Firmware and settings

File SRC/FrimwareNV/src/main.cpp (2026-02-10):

/**
 * Vibranet Node v6.0 - Triaxial Snapshot & Debug Edition
 * PATCH: Soft Start + WAKE_RF_DISABLED (Solución Brownout)
 */

#include <Arduino.h>
#include <ESP8266WiFi.h>
#include <PubSubClient.h>
#include <Adafruit_MPU6050.h>
#include <Adafruit_Sensor.h>
#include <Wire.h>
#include <WiFiManager.h> 
#include <FS.h>
#include <LittleFS.h>
#include <ESP8266mDNS.h>
#include <ArduinoJson.h>

#include "config.h" 

// PINES
#define SDA_PIN 4 
#define SCL_PIN 5
#define LED_YELLOW  12 
#define LED_GREEN   13 
#define LED_RED     14 

// VERSIONES
#define HW_VER "1.5"
#define SW_VER "6.1" // Actualizado para reflejar el parche de energía

// VARIABLES
struct DeviceConfig {
    int mode; int sleep_time_s; int mpu_threshold; int sampling_freq; uint32_t burst_size;
};
DeviceConfig config = {1, 60, 10, 500, 256};  
char node_id[32] = "dango_node_002"; // Valor por defecto si no hay config guardada
char mqtt_server[40] = ""; char mqtt_port[6] = "1883";
WiFiClient espClient; PubSubClient client(espClient);
Adafruit_MPU6050 mpu1; Adafruit_MPU6050 mpu2;
bool mpu1_active = false; bool mpu2_active = false;
bool shouldSaveConfig = false;

// ================= HELPERS VISUALES =================
void setStatus(int pinOn) {
    digitalWrite(LED_YELLOW, (pinOn == LED_YELLOW) ? HIGH : LOW);
    digitalWrite(LED_GREEN, (pinOn == LED_GREEN) ? HIGH : LOW);
    digitalWrite(LED_RED, (pinOn == LED_RED) ? HIGH : LOW);
}

void blinkErrorAndRestart() {
    Serial.println("!!! FALLO CRITICO - REINICIANDO SISTEMA !!!");
    for(int i=0; i<5; i++) { digitalWrite(LED_RED, HIGH); delay(100); digitalWrite(LED_RED, LOW); delay(100); }
    ESP.restart();
}

void printCurrentConfig() {
    Serial.println("\n--- CONFIGURACION ACTUAL ---");
    Serial.print("Modo: "); Serial.println(config.mode == 1 ? "BURST (FFT)" : "SNAPSHOT (Acel)");
    Serial.print("Sleep: "); Serial.print(config.sleep_time_s); Serial.println(" s");
    Serial.print("Umbral: "); Serial.println(config.mpu_threshold);
    Serial.print("Freq: "); Serial.println(config.sampling_freq);
    Serial.println("----------------------------\n");
}

// ================= I2C RECOVERY =================
void aggressiveBusRecover() {
    Serial.println(">> [1] Lavado de Bus I2C...");
    pinMode(SDA_PIN, INPUT_PULLUP); pinMode(SCL_PIN, OUTPUT);
    for (int i = 0; i < 16; i++) {
        digitalWrite(SCL_PIN, LOW); delayMicroseconds(10);
        if (i == 8) pinMode(SDA_PIN, INPUT_PULLUP); 
        digitalWrite(SCL_PIN, HIGH); delayMicroseconds(10);
        if (digitalRead(SDA_PIN) == HIGH && i > 8) break;
    }
    pinMode(SDA_PIN, OUTPUT); digitalWrite(SDA_PIN, LOW); delayMicroseconds(10);
    digitalWrite(SCL_PIN, HIGH); delayMicroseconds(10); digitalWrite(SDA_PIN, HIGH); delayMicroseconds(10);
    pinMode(SDA_PIN, INPUT); pinMode(SCL_PIN, INPUT);
}

void groundingPins() {
    Serial.println(">> [2] Grounding SDA/SCL...");
    pinMode(SDA_PIN, OUTPUT); digitalWrite(SDA_PIN, LOW); pinMode(SCL_PIN, OUTPUT); digitalWrite(SCL_PIN, LOW);
    delay(100); pinMode(SDA_PIN, INPUT); pinMode(SCL_PIN, INPUT);
}

void blindSensorReset(uint8_t addr) {
    Wire.beginTransmission(addr); Wire.write(0x6B); Wire.write(0x80); Wire.endTransmission(); 
    Serial.print(">> [3] Reset Ciego -> 0x"); Serial.println(addr, HEX);
}

// ================= CONFIG JSON =================
void loadMQTTConfig() { if (LittleFS.exists("/mqtt_config.json")) { File f = LittleFS.open("/mqtt_config.json", "r"); if (f) { DynamicJsonDocument doc(512); deserializeJson(doc, f); strcpy(mqtt_server, doc["server"]); strcpy(mqtt_port, doc["port"]); f.close(); } } }
void saveMQTTConfig() { DynamicJsonDocument doc(512); doc["server"] = mqtt_server; doc["port"] = mqtt_port; File f = LittleFS.open("/mqtt_config.json", "w"); if (f) { serializeJson(doc, f); f.close(); } }
void loadSystemConfig() { if (LittleFS.exists("/sys_config.json")) { File f = LittleFS.open("/sys_config.json", "r"); if (f) { DynamicJsonDocument doc(512); deserializeJson(doc, f); config.mode = doc["mode"]|1; config.sleep_time_s = doc["sleep"]|900; config.mpu_threshold = doc["thr"]|20; config.sampling_freq = doc["freq"]|500; config.burst_size = doc["bsize"]|256; if(doc.containsKey("id")) strlcpy(node_id, doc["id"], sizeof(node_id)); f.close(); } } }
void saveSystemConfig() { File f = LittleFS.open("/sys_config.json", "w"); if (!f) return; DynamicJsonDocument doc(512); doc["mode"]=config.mode; doc["sleep"]=config.sleep_time_s; doc["thr"]=config.mpu_threshold; doc["freq"]=config.sampling_freq; doc["bsize"]=config.burst_size; doc["id"] = node_id; serializeJson(doc, f); f.close(); }
void saveConfigCallback() { shouldSaveConfig = true; }

// ================= CONFIG SENSORES =================
void setupMPU_Latch(Adafruit_MPU6050 &mpu, int MPU_ADDR) {
    // 1. Reset y Wake Up
    Wire.beginTransmission(MPU_ADDR); Wire.write(0x6B); Wire.write(0x00); Wire.endTransmission();
    
    // 2. Filtro Pasa Altos (5Hz) - Para que no detecte gravedad estática
    Wire.beginTransmission(MPU_ADDR); Wire.write(0x1C); Wire.write(0x01); Wire.endTransmission();
    
    // 3. CONFIGURACIÓN DEL PIN (CRÍTICO)
    // Usamos 0xF0 (11110000) -> Active Low, Open Drain, Latch.
    // Open Drain es OBLIGATORIO si tienes dos sensores unidos.
    Wire.beginTransmission(MPU_ADDR); Wire.write(0x37); Wire.write(0xF0); Wire.endTransmission();
    
    // 4. Umbral de detección (Motion Threshold)
    Wire.beginTransmission(MPU_ADDR); Wire.write(0x1F); Wire.write(config.mpu_threshold); Wire.endTransmission();
    
    // 5. Duración (Motion Duration) - 1ms
    Wire.beginTransmission(MPU_ADDR); Wire.write(0x20); Wire.write(1); Wire.endTransmission();
    
    // 6. HABILITAR INTERRUPCIÓN (FALTABA ESTO)
    // Sin esto, el sensor mide el golpe pero no avisa por el pin INT.
    Wire.beginTransmission(MPU_ADDR); Wire.write(0x38); Wire.write(0x40); Wire.endTransmission();
}

// Función para limpiar la interrupción del MPU (Desbloquear el Latch)
void clearMPUInterrupt(uint8_t addr) {
    Wire.beginTransmission(addr);
    Wire.write(0x3A); // Registro INT_STATUS
    Wire.endTransmission();
    Wire.requestFrom(addr, (uint8_t)1);
    Wire.read(); // Leemos el byte para limpiar el flag
    // Serial.println(">> INT Limpiado para addr 0x" + String(addr, HEX));
}

// ================= CAPTURA SNAPSHOT TRIAXIAL (X, Y, Z) =================
bool runSnapshotMode(Adafruit_MPU6050 &mpu, String sensorName) {
    sensors_event_t a, g, t; 
    mpu.getEvent(&a, &g, &t);
    
    // DEBUG SERIAL: Ver los datos capturados
    Serial.print(">> [" + sensorName + "] SNAPSHOT: ");
    Serial.print("X:"); Serial.print(a.acceleration.x, 2);
    Serial.print(" Y:"); Serial.print(a.acceleration.y, 2);
    Serial.print(" Z:"); Serial.println(a.acceleration.z, 2);

    StaticJsonDocument<384> doc; 
    doc["id"] = node_id; 
    doc["t"] = "snap"; 
    doc["s"] = sensorName;
    
    // AHORA ENVIAMOS LAS 3 DIRECCIONES
    doc["ax"] = serialized(String(a.acceleration.x, 2));
    doc["ay"] = serialized(String(a.acceleration.y, 2));
    doc["az"] = serialized(String(a.acceleration.z, 2));
    
    // VCC ya se manda en heartbeat, no hace falta aquí.
    
    char buffer[384]; 
    serializeJson(doc, buffer); 
    return client.publish("vibranet/data", buffer);
}

// ================= CAPTURA BURST TRIAXIAL =================
bool performBurstCapture(Adafruit_MPU6050 &mpu, String sensorName) {
    mpu.enableSleep(false); mpu.enableCycle(false); mpu.setFilterBandwidth(MPU6050_BAND_260_HZ);
    
    if (ESP.getFreeHeap() < 15000) { Serial.println("RAM Baja -> 128 muestras"); config.burst_size = 128; }

    float *waveformX = new (std::nothrow) float[config.burst_size];
    float *waveformY = new (std::nothrow) float[config.burst_size];
    float *waveformZ = new (std::nothrow) float[config.burst_size];

    if (!waveformX || !waveformY || !waveformZ) {
        Serial.println("Error RAM");
        if (waveformX) delete[] waveformX;
        if (waveformY) delete[] waveformY;
        if (waveformZ) delete[] waveformZ;
        return false; 
    }

    unsigned long period = 1000000 / config.sampling_freq;
    unsigned long nextSample = micros();
    sensors_event_t a, g, t;

    for (uint32_t i = 0; i < config.burst_size; i++) {
        while (micros() < nextSample) yield();
        mpu.getEvent(&a, &g, &t);
        waveformX[i] = a.acceleration.x; waveformY[i] = a.acceleration.y; waveformZ[i] = a.acceleration.z;
        nextSample += period;
    }

    String payload = ""; payload.reserve(500 + (config.burst_size * 22)); 
    payload = "{\"id\":\"" + String(node_id) + "\",\"s\":\"" + sensorName + "\",\"t\":\"burst\",\"fs\":" + String(config.sampling_freq) + ",";
    
    payload += "\"dx\":["; for (uint32_t i=0; i<config.burst_size; i++) { payload += String(waveformX[i], 2); if(i<config.burst_size-1) payload+=","; } payload += "],";
    payload += "\"dy\":["; for (uint32_t i=0; i<config.burst_size; i++) { payload += String(waveformY[i], 2); if(i<config.burst_size-1) payload+=","; } payload += "],";
    payload += "\"dz\":["; for (uint32_t i=0; i<config.burst_size; i++) { payload += String(waveformZ[i], 2); if(i<config.burst_size-1) payload+=","; } payload += "]}";

    bool res = client.publish("vibranet/burst", payload.c_str(), false);
    if(res) Serial.println(">> Burst " + sensorName + " enviado (" + String(payload.length()) + " bytes)");
    
    delete[] waveformX; delete[] waveformY; delete[] waveformZ;
    return res;
}

// ================= LEER VOLTAJE DE BATERÍA =================
float leerBateria() {
  // 1. Leemos el valor crudo (0 a 1023)
  int adcRaw = analogRead(A0);
  
  // 2. Convertimos ese número a Voltaje que llega al pin (0V a 1.0V)
  //    (1.0V / 1023 pasos = 0.0009775)
  float voltajePin = adcRaw * 0.0009775;
  
  // 3. Deshacemos el Divisor Resistivo (470k + 100k) / 100k = 5.7
  //    Multiplicamos por 5.7 para saber qué voltaje había ANTES de las resistencias
  float voltajeDivisor = voltajePin * 5.7;
  
  // 4. Sumamos lo que se comió el Diodo Schottky (Tu medición: 0.2V)
  float voltajeBateria = voltajeDivisor + 0.2;

  // --- Opcional: Ajuste fino ---
  // Si con esto te marca 4.05V y el multímetro dice 4.02V, cambia el 0.2 por 0.17
  
  return voltajeBateria;
}

// ================= HEARTBEAT & CALLBACKS =================
void publishStatus(String reason) {
    StaticJsonDocument<512> doc; // Aumentamos tamaño para SSID y versiones
    doc["id"] = node_id;
    doc["t"] = "status";
    doc["reason"] = reason;
    
    // Datos Dinámicos
    float vcc = leerBateria(); 
    doc["bat"] = serialized(String(vcc, 2));
    doc["ip"] = WiFi.localIP().toString();
    doc["rssi"] = WiFi.RSSI();
    doc["ssid"] = WiFi.SSID(); // <--- NUEVO: Red actual
    
    // Datos Estáticos (Versiones)
    doc["hw"] = HW_VER;       // <--- NUEVO
    doc["sw"] = SW_VER;       // <--- NUEVO
    
    // Configuración
    JsonObject cfg = doc.createNestedObject("conf");
    cfg["mode"] = config.mode; 
    cfg["sleep"] = config.sleep_time_s; 
    cfg["thr"] = config.mpu_threshold; 
    cfg["fs"] = config.sampling_freq;

    char buffer[512];
    serializeJson(doc, buffer);
    
    String statusTopic = "vibranet/status/" + String(node_id);
    client.publish(statusTopic.c_str(), buffer, true);
    Serial.println(">> Status enviado (v" + String(SW_VER) + ") en red: " + WiFi.SSID());
}

void mqttCallback(char* topic, byte* payload, unsigned int length) {
    StaticJsonDocument<200> doc;
    DeserializationError error = deserializeJson(doc, payload, length);
    if (error) { Serial.println("Error JSON Config"); return; }

    bool changed = false; bool restartRequired = false; // Bandera para saber si reiniciamos
    Serial.println("\n--- Recibiendo Config Remota ---");
    if (doc.containsKey("id")) {
        const char* newId = doc["id"];
        if (strcmp(node_id, newId) != 0) { // Solo si es diferente
            strlcpy(node_id, newId, sizeof(node_id));
            Serial.println("Update NODE ID -> " + String(node_id));
            changed = true;
            restartRequired = true; // El ID requiere reinicio obligatorio
        }
    }
    if (doc.containsKey("sleep")) { config.sleep_time_s = doc["sleep"]; Serial.println("Update Sleep -> " + String(config.sleep_time_s)); changed = true; }
    if (doc.containsKey("mode"))  { config.mode = doc["mode"]; Serial.println("Update Mode -> " + String(config.mode)); changed = true; }
    if (doc.containsKey("thr"))   { config.mpu_threshold = doc["thr"]; Serial.println("Update Thr -> " + String(config.mpu_threshold)); changed = true; }
    if (doc.containsKey("fs"))    { config.sampling_freq = doc["freq"]; Serial.println("Update Freq -> " + String(config.sampling_freq)); changed = true; }

    if (changed) {
        saveSystemConfig();
        publishStatus("config_updated"); 
        printCurrentConfig(); // Muestra la config final tras el cambio
        if (restartRequired) {
            Serial.println(">> ID CAMBIADO. REINICIANDO EN 1s...");
            delay(1000);
            ESP.restart();
        }
    }
}
// ================= SETUP =================
void setup() {
    // 1. Iniciar Serial y esperar estabilización
    delay(500);
    Serial.begin(115200);
    Serial.println("\n\n>>> ARRANQUE VIBRANET V6.2 (LOW POWER MODE) <<<");

    // -----------------------------------------------------------
    // TRUCO SALVAVIDAS: LIMITAR CORRIENTE DEL WIFI
    // -----------------------------------------------------------
    // Forzamos modo estación primero
    WiFi.mode(WIFI_STA);
    
    // Ponemos la potencia de salida al MÍNIMO (0 dBm)
    // Esto reduce el pico de consumo drásticamente.
    // Rango: 0 (min) a 20.5 (max)
    WiFi.setOutputPower(0); 
    // -----------------------------------------------------------

    aggressiveBusRecover(); groundingPins();
    pinMode(LED_YELLOW, OUTPUT); pinMode(LED_GREEN, OUTPUT); pinMode(LED_RED, OUTPUT);
    setStatus(LED_YELLOW); 

    LittleFS.begin(); loadMQTTConfig(); loadSystemConfig(); 
    
    // DEBUG: Ver qué ID estamos usando
    Serial.print("Node ID: "); Serial.println(node_id);
    printCurrentConfig();

    Wire.begin(); Wire.setClock(10000); delay(50);
    blindSensorReset(MPU1_ADDR); blindSensorReset(MPU2_ADDR); delay(100); 
    Wire.setClock(100000); 
    
    if (!mpu1.begin(MPU1_ADDR)) { Serial.println("ERROR: MPU1 no responde."); blinkErrorAndRestart(); } 
    else { Serial.println("MPU1 OK."); mpu1_active = true; mpu1.setAccelerometerRange(MPU6050_RANGE_4_G); mpu1.setFilterBandwidth(MPU6050_BAND_21_HZ); }
    
    if (mpu2.begin(MPU2_ADDR)) { Serial.println("MPU2 OK."); mpu2_active = true; mpu2.setAccelerometerRange(MPU6050_RANGE_4_G); mpu2.setFilterBandwidth(MPU6050_BAND_21_HZ); }
    
    WiFiManager wm; 
    wm.setSaveConfigCallback(saveConfigCallback);
    
    // AUMENTA EL TIMEOUT para darle tiempo si la señal es débil por la baja potencia
    wm.setConnectTimeout(30); 
    wm.setConfigPortalTimeout(120);

    WiFiManagerParameter custom_mqtt_server("server", "MQTT Server IP", mqtt_server, 40);
    WiFiManagerParameter custom_mqtt_port("port", "MQTT Port", mqtt_port, 6);
    wm.addParameter(&custom_mqtt_server); wm.addParameter(&custom_mqtt_port);
    
    if (!wm.autoConnect("VibraNet_AP")) {
        Serial.println("WiFi Fail");
        // Si falla, dormimos SIN radio para ahorrar energía
        ESP.deepSleep(5e6, WAKE_RF_DISABLED);
    }

    // --- OPCIONAL: SUBIDA DE POTENCIA ---
    // COMENTADO POR SEGURIDAD: Si usas el conversor USB-TTL, descomentar esto 
    // podría causar un reinicio justo ahora. Déjalo comentado para la prueba.
    // WiFi.setOutputPower(10); 

    if (shouldSaveConfig) { strcpy(mqtt_server, custom_mqtt_server.getValue()); strcpy(mqtt_port, custom_mqtt_port.getValue()); saveMQTTConfig(); }
    
    // CORRECCIÓN: Borrada la línea duplicada que tenías aquí
    client.setServer(mqtt_server, atoi(mqtt_port)); client.setCallback(mqttCallback); client.setBufferSize(8192);

    // Usamos la variable 'node_id' en lugar de la constante NODE_ID
    String clientId = String(node_id) + "_" + String(random(0xffff), HEX);
    
    if (client.connect(clientId.c_str())) {
        Serial.println("MQTT Conectado.");
        // Suscripción dinámica basada en el nombre actual
        client.subscribe(("vibranet/config/"+String(node_id)).c_str());

        // --- SALA DE ESPERA (500ms) ---
        Serial.print("Esperando config remota...");
        unsigned long startWait = millis();
        while (millis() - startWait < 500) { client.loop(); delay(10); }
        Serial.println(" Listo.");

        publishStatus("wake_up");
        
        // EJECUCIÓN SEGÚN MODO
        if (config.mode == 1) { // BURST
            Serial.println(">> Iniciando Captura BURST...");
            if (mpu1_active) performBurstCapture(mpu1, "s1");
            if (mpu2_active) performBurstCapture(mpu2, "s2");
        } else { // SNAPSHOT
            Serial.println(">> Iniciando Captura SNAPSHOT...");
            if (mpu1_active) runSnapshotMode(mpu1, "s1");
            if (mpu2_active) runSnapshotMode(mpu2, "s2");
        }
        
        if (mpu1_active) setupMPU_Latch(mpu1, MPU1_ADDR);
        if (mpu2_active) setupMPU_Latch(mpu2, MPU2_ADDR);

        // Limpiamos cualquier interrupción pendiente para que el pin INT suba a HIGH
        if (mpu1_active) clearMPUInterrupt(MPU1_ADDR);
        if (mpu2_active) clearMPUInterrupt(MPU2_ADDR);
        delay(150); 
        // -------------------------

        Serial.println("Durmiendo " + String(config.sleep_time_s) + "s (RF OFF)...");
        setStatus(LED_GREEN); delay(1000); setStatus(-1);
        
        // >>> DEEP SLEEP MEJORADO <<<
        // WAKE_RF_DISABLED: El próximo despertar será con la radio APAGADA,
        // evitando el pico de corriente inicial.
        ESP.deepSleep(config.sleep_time_s * 1000000ULL, WAKE_RF_DISABLED);
        
    } else {
        Serial.println("MQTT Fail -> Sleep 5s"); 
        // También usamos RF DISABLED aquí por seguridad
        ESP.deepSleep(5 * 1000000ULL, WAKE_RF_DISABLED); 
    }
}

void loop() {}

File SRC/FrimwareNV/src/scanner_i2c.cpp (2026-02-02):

// Escaner de I2C addres de los sensores

/*
#include <Arduino.h>
#include <Wire.h>

void setup() {
  Wire.begin();
  Serial.begin(115200);
  while (!Serial);
  Serial.println("\nI2C Scanner");
}

void loop() {
  byte error, address;
  int nDevices = 0;

  Serial.println("Scanning...");

  for(address = 1; address < 127; address++ ) {
    Wire.beginTransmission(address);
    error = Wire.endTransmission();

    if (error == 0) {
      Serial.print("I2C device found at address 0x");
      if (address < 16) Serial.print("0");
      Serial.print(address, HEX);
      Serial.println("  !");
      nDevices++;
    }
  }
  if (nDevices == 0) Serial.println("No I2C devices found\n");
  else Serial.println("done\n");

  delay(5000);
}
  
*/

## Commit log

2025-10-04 Creación de estructura
    [NodoVibraciones.kicad_pcb, NodoVibraciones.kicad_sch]
2025-10-04 Se creó la carpeta de frimware
2025-10-05 Se creó PCB v0.0.1 de nodo VibraNet
    [NodoVibraciones.kicad_pcb, NodoVibraciones.kicad_sch]
2025-10-29 Imágenes y primera template.
    Se suben las imágenes del avance del proyecto.
    Se decide la primera plantilla de LaTeX para el informe del avance.
2025-11-03 Informe de avance v1.2
2025-11-18 se agregó la carpeta node-red para trabajar con los flujos de node-red
    [NodoVibraciones-B_Cu.gbr, NodoVibraciones-B_Mask.gbr, NodoVibraciones-B_Paste.gbr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]
2026-01-08 Se logró mandar datos a InfluxDB y visualizarlos en Grafana, también esp8266-Arduino
2026-02-02 Se implementaron interrupciones y diseño de PCB v1.0.8
    [NodoVibraciones.kicad_pcb, NodoVibraciones.kicad_sch]
2026-02-10 Lanzamiento primer prototipo funcional ESP07 verHW1.5
    [ConjuntoNodoVibranet.cfg, HW-373.stp, NodoVibraciones.kicad_pcb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]
